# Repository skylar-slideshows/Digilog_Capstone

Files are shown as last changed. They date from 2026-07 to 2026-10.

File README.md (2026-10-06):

# Digitally Controlled Analog Mixing Console

### Capstone, 2026, Northeastern University Department of Electrical Engineering

### Contributors: Skylar Denno, Darya Petrova, Evan Forcucci, Xinhao Chen, Luke Garrity, Daniel Salas

### Advisor: [Milad Siami](https://coe.northeastern.edu/people/siami-milad/)

## [Firmware Documentation](https://docs.skylar.lgbt/)

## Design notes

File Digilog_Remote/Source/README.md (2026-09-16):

### $chct [N]^
STM32 -> Remote. Reports the number of physical channels present in the console to the remote program.
### $chnm [n] [name]^
STM32 -> Remote. Sets channel n's name in the GUI to reflect the console.
### $ud [n] [controlID]^
STM32 -> Remote. User has turned physical knob. Update it in GUI to new position.
### $sw [n] [switchID]^
STM32 -> Remote. User has toggled routing switch. Update it in GUI to new state.
### $sel [n]^
STM32 -> Remote. Indicate a channel selected in physical console. Sync to app.
### (No manual commanding) $ack [message]^
STM32 -> Remote. Indicate console's recept of any message (except ack) from remote.
###________________________________________________________________
### chnm [n] [name]
Remote -> STM32. User changed name in remote. Set it in console.
### ud [n] [controlID]
Remote -> STM32. User changed knob in remote. Update it in console.
### sw [n] [switchID]
Remote -> STM32. User toggled switch in remote. Update it in console.
### sel [n]
Remote -> STM32. Indicate a channel selected on remote app.
### sett [s] [value]
Remote -> STM32. Update a setting.
### md [t] [data]
Remote -> STM32. Send mass data (entire channel's values).
t = 0 -> channel info, t = 1 -> console settings, t = 2 -> insert/chain routing
md begin // md end
### ack [message]
Remote -> STM32. Indicate remotes's recept of any message (except ack) from console.
###________________________________________________________________
n = Channel
###________________________________________________________________
###controlID:
0 = GAIN (Input)
1 = AUX 1 (Send)
2 = PAN (Send 1)
3 = AUX 2 (Send)
4 = PAN (Send 2)
5 = AUX 3 (Send)
6 = PAN (Send 3)
7 = AUX 4 Mono (Send)
8 = HF Gain (EQ)
9 = HF Freq (EQ)
10 = HMF Gain (EQ)
11 = HMF Freq (EQ)
12 = HMF Q (EQ)
13 = LMF Gain (EQ)
14 = LMF Freq (EQ)
15 = LMF Q (EQ)
16 = LF Gain (EQ)
17 = LF Freq (EQ)
18 = Input (Comp)
19 = Attack (Comp)
20 = Threshold (Comp)
21 = Release (Comp)
22 = De-Ess (Comp)
23 = Ratio (Comp)
24 = Output (Comp)
25 = PAN (extra knob)
26 = Fader
###________________________________________________________________
###switchID:
0 = Input Source (cycle: 0 Line / 1 Mic / 2 Hi-Z)
1 = Phase (PHS)
2 = +48V
3 = HPF
4 = Solo
5 = Mute
6 = Insert (INS)
7 = Pre-fader insert
###________________________________________________________________
###s:

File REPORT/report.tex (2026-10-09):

\documentclass[11pt, letterpaper,titlepage]{article}

% --- Essential Packages ---
\usepackage[utf8]{inputenc}
\usepackage[margin=1in]{geometry}
\usepackage{fancyhdr} % For custom headers and footers
\usepackage{graphicx}
\usepackage{amsfonts}

\usepackage{amsmath}
\usepackage{float}

\usepackage{hyperref}
\usepackage{setspace}

\usepackage{ragged2e}
\usepackage{parskip}

\usepackage{booktabs}
% --- Header/Footer Configuration ---
\pagestyle{fancy}
\fancyhf{} % Clear all default header and footer settings
\fancyhead[L]{DIGITALLY CONTROLLED ANALOG MIXER} % Left header text
\fancyhead[C]{} % Center header text (empty)
\fancyhead[R]{\thepage} % Right header (page number)
\renewcommand{\headrulewidth}{0.4pt} % Line below header
\linespread{1.2}

\begin{document}
\begin{titlepage}
    \centering
    \vspace*{0cm}
    
    {\huge \textbf{Analog Mixing Console with Digital Control\\ \vspace{0.5cm}and Automated Signal Path Configuration}} \\[1cm]
    
    \vspace{0.5cm}
    
    {\huge Capstone Project Report}
    
    \vspace{5cm}

    {\Large \textbf{Skylar Denno}}
    
    \vspace{0.3cm}
    
    {\Large \textbf{Darya Petrova}}
    
        \vspace{0.3cm}
    
    {\Large \textbf{Evan Forcucci}}
    
        \vspace{0.3cm}
    
    {\Large \textbf{Xinhao Chen}}
    
        \vspace{0.3cm}
    
    {\Large \textbf{Luke Garrity}}
    
        \vspace{0.3cm}
    
    {\Large \textbf{Daniel Salas}}

    \vspace{0.5cm}
    
        {\large \textbf{Advisor: }Milad Siami \textbf{[Team \#2]}}
    
        \vspace{1.3cm}

        {\LARGE \textbf{Northeastern University}} \\
        
    Department of Electrical and Computer Engineering \\
    \vspace{1cm}

    \today

\end{titlepage}
\setlength{\parindent}{6pt}

\justify

\tableofcontents
\newpage

\section{Introduction}
\subsection{Background}
\subsection{Problem Statement}
\subsection{Scope and Design Goals}

\newpage

\section{Analog Design}

\subsection{Analog Systems Overview}

\subsection{Voltage Controlled Amplifiers}
\label{sec:vca}
% ----------------------------------------------------------------------------
% [PROSE] Opening -- sketch:
%   - Every gain in the console is set by a DC control voltage from the digital
%     side; the audio never passes through a digital stage.
%   - Pan/fader module used to introduce the basics: two identical VCAs, one
%     control voltage each, so the VCA and its temperature behavior can be
%     shown without extra circuitry. EQ, input and compressor modules reuse this.
%   - Part: THAT2180A (Blackmer log-antilog cell): dB-linear control,
%     >120 dB dynamic range, 0.005 % THD typ., pre-trimmed. [cite datasheet]
%   - One sentence on the module path (input buffer -> insert switching ->
%     two VCAs -> I/V -> balanced bus drivers), point to Fig.~\ref{fig:vca-stage}.
% ----------------------------------------------------------------------------
The most fundamental part of an audio mixer is control of each individual channels' gain before summing to the final stereo signal. To implement gain control that can be remote controlled by a voltage, voltage controlled amplifiers (VCAs) were used. Two VCAs were actually used on every channel. Since we aim to build a stereo mixer, the two VCAs feed the left and right summing channel of the mix bus, respectively. Each channel's two VCAs may be given different gain control voltages (CVs) to pan the channel's audio in the stereo field. For example, if a channel's left VCA had a CV to attenuate by -90dB (basically muted) and the right VCA had the CV to add 6dB of gain, that channel's audio would sound like it was coming from the right speaker after summing. To implement the regular fader behavior, which changes the gain of the left and right side together, both the left and right control voltages would be scaled together to change gain equally in both channels.

The specific VCA we picked for this purpose was the THAT 2180 from the Massachusetts-based THAT Corporation. It is the industry standard VCA for high fidelity audio performance. This is due to its total harmonic distortion (THD) of just 0.005\% (for the 'A' grade 2180s), which is extremely low for a VCA. Additionally, it uses a Blackmer gain cell, which has a logarithmic gain curve, allowing control voltage and decibel gain to coincide linearly. Unfortunately, in September 2026, halfway through the design of the project, THAT Corporation announced it was discontinuing its legendary 2180 series, sending shockwaves through the audio electronics community. Frantically, we bought 32 of the 'A' grade THAT 2180s to use for this purpose, but the rest of the analog systems use clones of the THAT 2180 (Alfa RPAR AS2180, which from our tests, seems to have nearly as good performance as the genuine 'A' grade 2180s) or the SSI2164 VCA.

\begin{figure}[H]
    \centering
    % \includegraphics[width=0.8\textwidth]{figures/vca_stage.pdf}
    \fbox{\parbox[c][4.5cm][c]{0.8\textwidth}{\centering
        Placeholder: one VCA channel --- $C_\text{in}$, $R_\text{in}$, THAT2180A,
        I/V converter ($R_f \parallel C_f$), control-port snubber, $R_\text{SET}$}}
    \caption{One channel of the pan/fader VCA stage.}
    \label{fig:vca-stage}
\end{figure}

\paragraph{Current-mode operation.}
% [PROSE] sketch:
%   - Current in, current out: pins 1 and 8 sit at virtual ground.
%   - R_in turns the input voltage into a current; an op-amp I/V converter turns
%     the output current back into a voltage. Overall path is non-inverting.
%   - With R_f = R_in the stage is unity gain when the cell is at 0 dB.
\begin{equation}
    I_\text{in} = \frac{V_\text{in}}{R_\text{in}}, \qquad
    I_\text{out} = A_I\, I_\text{in}, \qquad
    V_\text{out} = R_f\, I_\text{out}
    \quad\Longrightarrow\quad
    \frac{V_\text{out}}{V_\text{in}} = \frac{R_f}{R_\text{in}}\,A_I
    \label{eq:vca-transfer}
\end{equation}

\paragraph{Exponential gain control.}
% [PROSE] sketch:
%   - The cell logs the input current across matched junctions, adds the control
%     voltage, and antilogs it back. [cite THAT DN128 / Hebert, AES 1995]
%   - Gain is exponential in the control voltage, i.e. linear in dB.
%   - kappa comes from kT/q; datasheet value 6.1 mV/dB at a die temperature of
%     about 35 C.
%   - E_C+ carries the fader/pan CV here; E_C- is grounded (the compressor CV
%     enters there in a later module).
\begin{equation}
    \begin{gathered}
    A_I = \exp\!\left(\frac{q\,(E_{C+}-E_{C-})}{2kT}\right)
    \quad\Longrightarrow\quad
    G_\text{dB} = 20\log_{10}A_I = \frac{E_{C+}-E_{C-}}{\kappa(T)}, \\
    \kappa(T) = \frac{\ln 10}{10}\,\frac{kT}{q} \approx 6.1\ \mathrm{mV/dB}
    \end{gathered}
    \label{eq:vca-law}
\end{equation}

\paragraph{Temperature sensitivity.}
% [PROSE] sketch:
%   - kappa is proportional to absolute temperature (PTAT), so the dB gain scales
%     by T0/T: a span error that pivots about 0 dB.
%   - Example: -20 dB setting, +20 C warm-up -> about 1.3 dB error. This is what
%     Section~\ref{sec:cv-buffer} compensates.
\begin{equation}
    G_\text{dB}(T) = G_\text{dB}(T_0)\,\frac{T_0}{T}
    \quad\Longrightarrow\quad
    \frac{\Delta G_\text{dB}}{G_\text{dB}} \approx -\frac{\Delta T}{T_0} \approx -0.33\,\%/\mathrm{K}
    \label{eq:vca-tempco}
\end{equation}

\paragraph{Operating point.}
% [PROSE] sketch:
%   - Pin 5 is not a supply: R_SET sets the cell current (pin sits about four
%     Vbe below ground). Datasheet rule: I_SET covers the peak signal currents
%     plus 570 uA of bias. Worst case 0 dB with a 14 V peak: 0.70 mA in and out.
%   - Control port must be driven from well under 50 ohm: base currents are
%     signal-related, and 10 uV of audio at the port already gives 0.01 % THD.
%     Hence op-amp drive plus a shunt RC snubber at the pin.
%   - Remaining choices in Table~\ref{tab:vca-op}.
\begin{equation}
    I_\text{SET} = \frac{V_\text{pin5}-V_{EE}}{R_\text{SET}}
    = \frac{-2.85\,\mathrm{V}+15\,\mathrm{V}}{5.1\,\mathrm{k}\Omega} = 2.38\,\mathrm{mA}
    \;\geq\; \hat I_\text{in} + \hat I_\text{out} + 570\,\mu\mathrm{A} = 1.97\,\mathrm{mA}
    \label{eq:iset}
\end{equation}

\begin{table}[H]
    \centering
    \begin{tabular}{@{}lll@{}}
        \toprule
        Component & Value & Purpose \\
        \midrule
        $R_\text{in}$, $R_f$ & $20\,\mathrm{k}\Omega$ & unity gain at 0 dB; datasheet noise/THD point \\
        $C_\text{in}$ & $10\,\mu\mathrm{F}$ bipolar & $f_c = 1/(2\pi R_\text{in} C_\text{in}) = 0.8$ Hz; blocks DC \\
        $C_f$ & $22\,\mathrm{pF}$ & cancels 15 pF at pin 8 (I/V stability) \\
        $R_\text{SET}$ & $5.1\,\mathrm{k}\Omega$ & $I_\text{SET} = 2.38$ mA, Eq.~\eqref{eq:iset} \\
        Port snubber & $100\,\Omega$ + $2.2\,\mathrm{nF}$ to ground & damps inductive op-amp output \\
        Sym (pin 4) & open & keeps factory THD trim \\
        \bottomrule
    \end{tabular}
    \caption{THAT2180A operating point.}
    \label{tab:vca-op}
\end{table}

\paragraph{Pan and fader law.}
% [PROSE] sketch:
%   - Constant-power pan: the sum of squares is constant, so a source keeps its
%     loudness across the stereo field; -3.01 dB per side at centre.
%   - Because the VCA is dB-linear, fader and pan simply add in the control
%     domain: no multiplier, one CV per channel, computed in firmware.
\begin{gather}
    g_L = G\cos\!\left(\tfrac{\pi\theta}{2}\right), \qquad
    g_R = G\sin\!\left(\tfrac{\pi\theta}{2}\right), \qquad
    g_L^2 + g_R^2 = G^2, \qquad \theta \in [0,1]
    \label{eq:panlaw}\\
    G_{\text{dB},L} = 20\log_{10}G + 20\log_{10}\cos\!\left(\tfrac{\pi\theta}{2}\right), \qquad
    G_{\text{dB},R} = 20\log_{10}G + 20\log_{10}\sin\!\left(\tfrac{\pi\theta}{2}\right)
    \label{eq:panlaw-db}
\end{gather}

\subsection{Control Voltage Buffering and Temperature Drift Compensation}
\label{sec:cv-buffer}
% ----------------------------------------------------------------------------
% [PROSE] Opening -- sketch:
%   - One op-amp stage per channel has four jobs: (1) map the DAC range onto the
%     VCA's useful control range, (2) drive the control port from a low
%     impedance, (3) filter DAC steps and noise (ripple on E_C modulates the
%     audio), (4) cancel the PTAT drift of Eq.~\eqref{eq:vca-tempco}.
%   - Topology: inverting multiple-feedback (MFB) low-pass fed by a small
%     network -- DAC current, an offset current from a -2.5 V reference, and
%     an NTC thermistor. Fig.~\ref{fig:cv-buffer}, values in
%     Table~\ref{tab:cv-values}.
%   - Why MFB: inverting (the sign needed), good rejection far above the
%     corner, scaling and filtering in one stage.
% ----------------------------------------------------------------------------

\begin{figure}[H]
    \centering
    % \includegraphics[width=0.8\textwidth]{figures/cv_buffer.pdf}
    \fbox{\parbox[c][4.5cm][c]{0.8\textwidth}{\centering
        Placeholder: CV buffer --- DAC input, $R_\text{cv}$ + trim,
        $R_\text{off}$ to $-2.5$ V, $R_p \parallel R_\text{NTC}$,
        MFB ($R_2$, $R_3$, $C_1$, $C_2$), OPA2197, snubber at $E_{C+}$}}
    \caption{Control voltage buffer for one VCA.}
    \label{fig:cv-buffer}
\end{figure}

\begin{figure}[H]
\centering
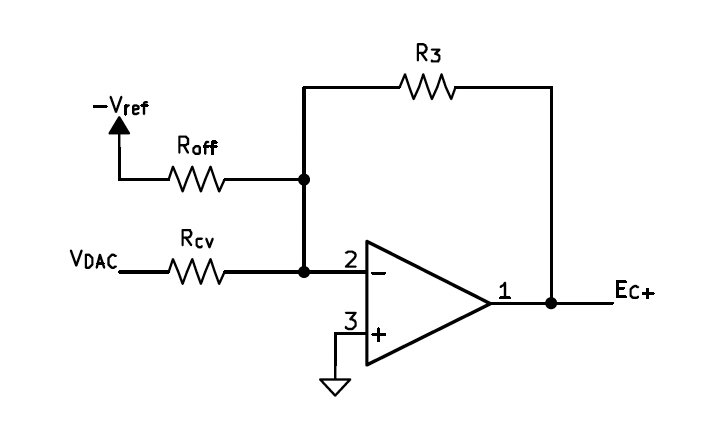
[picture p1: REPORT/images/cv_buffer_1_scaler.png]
 
\caption{TEST}
\end{figure}

\begin{figure}[H]
\centering
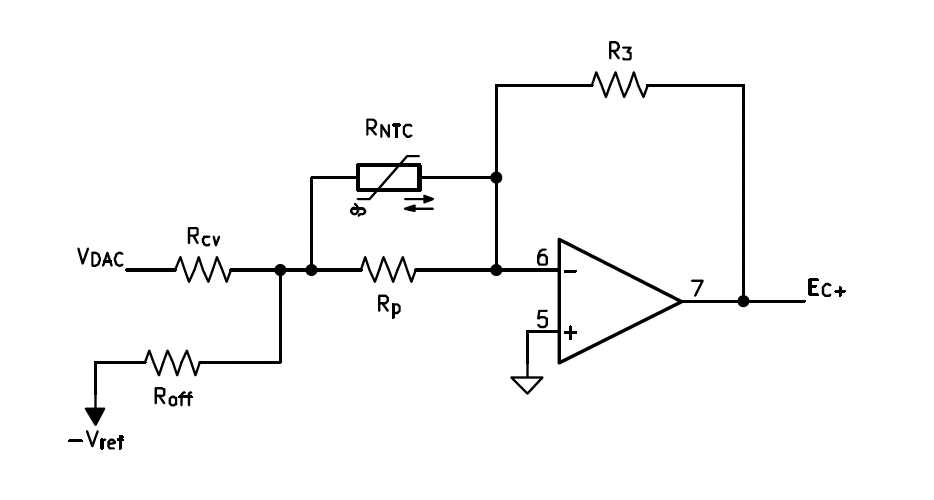
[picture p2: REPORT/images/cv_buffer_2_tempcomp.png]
 
\caption{TEST}
\end{figure}

\begin{figure}[H]
\centering
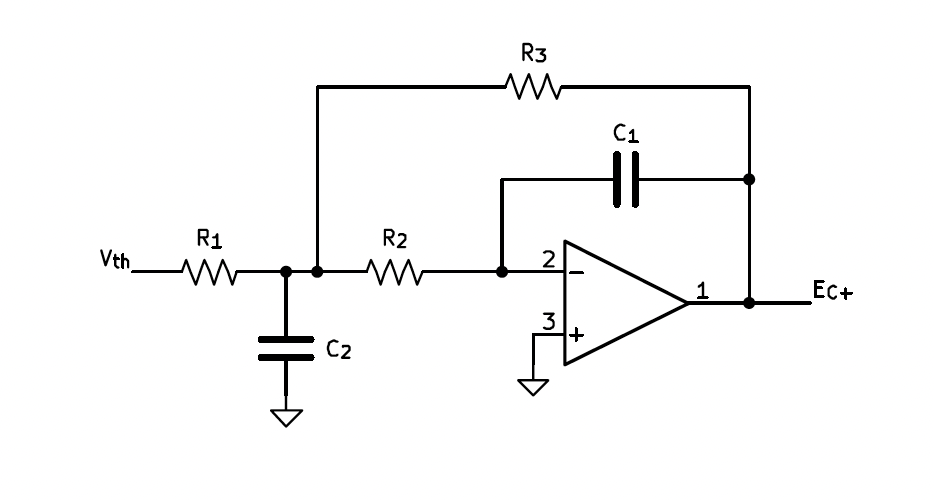
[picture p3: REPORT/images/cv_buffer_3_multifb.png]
 
\caption{TEST}
\end{figure}

\begin{figure}[H]
\centering
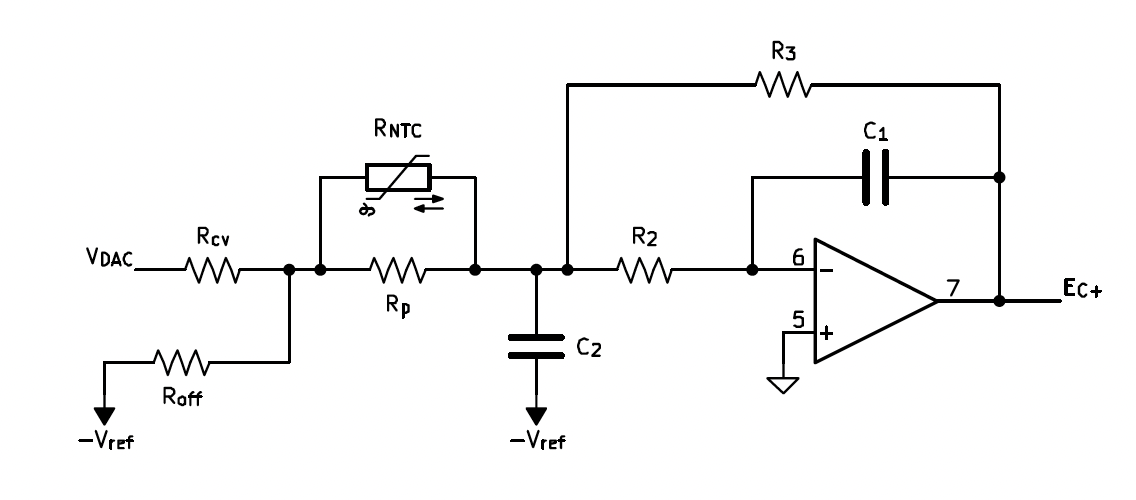
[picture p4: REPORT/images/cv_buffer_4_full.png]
 
\caption{TEST}
\end{figure}

\begin{figure}[H]
\centering
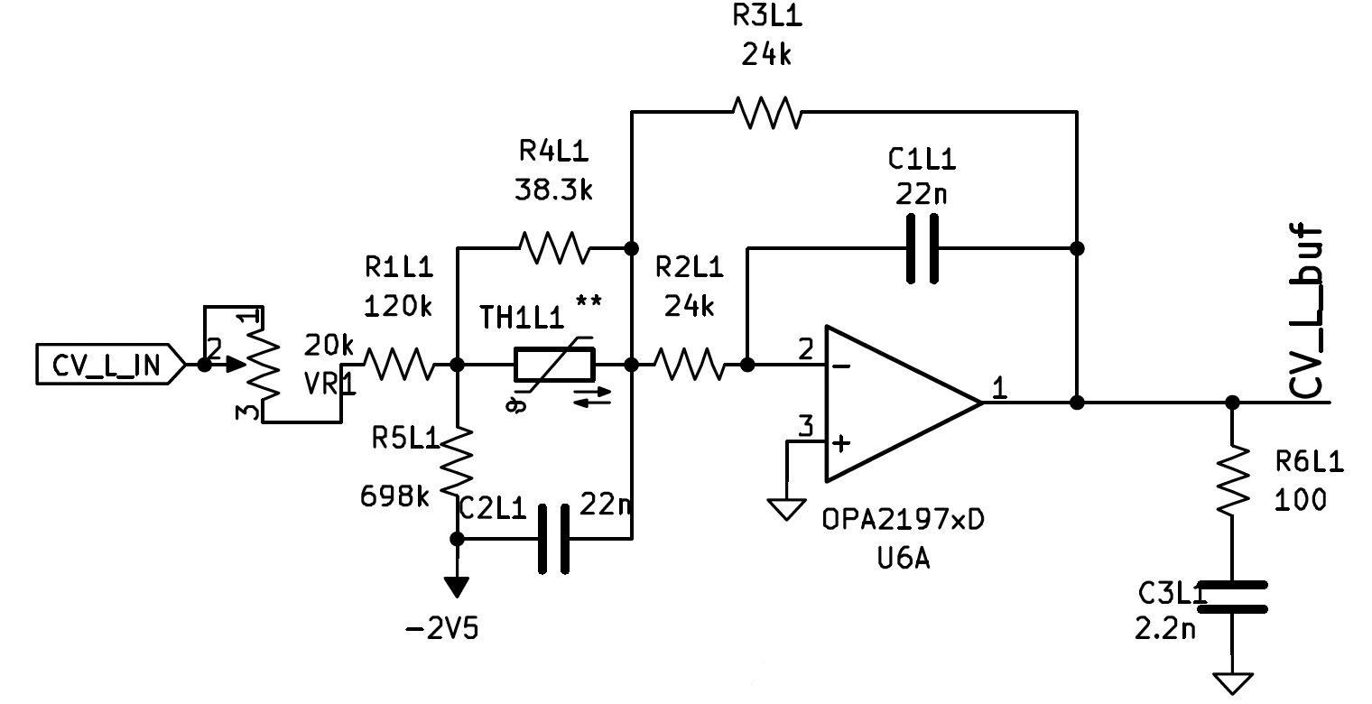
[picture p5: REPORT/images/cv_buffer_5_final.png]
 
\caption{The trim potentiometer on the left is ONLY to calibrate temperature scaling during assembly, and it is not accessible to the end user.}
\end{figure}

\begin{table}[H]
    \centering
    \begin{tabular}{@{}lll@{}}
        \toprule
        Component & Value & Role \\
        \midrule
        $R_\text{cv}$ & $120\,\mathrm{k}\Omega$ + $20\,\mathrm{k}\Omega$ trim ($133\,\mathrm{k}\Omega$ nom.) & DAC voltage to current; span trim \\
        $R_\text{off}$ & $698\,\mathrm{k}\Omega$ & offset current \\
        $R_p \parallel R_\text{NTC}$ & $38.3\,\mathrm{k}\Omega \parallel 47\,\mathrm{k}\Omega$ ($B = 4090$ K) & temperature compensation \\
        $R_2 = R_3$ & $24\,\mathrm{k}\Omega$ & filter and DC gain \\
        $C_1 = C_2$ & $22\,\mathrm{nF}$ film & filter \\
        $V_\text{ref}$ & 2.5 V (ADR5041 at $-2.5$ V, $222\,\mu$A bias) & offset reference \\
        Op-amp & OPA2197 & low offset and noise \\
        \bottomrule
    \end{tabular}
    \caption{CV buffer component values (one channel).}
    \label{tab:cv-values}
\end{table}

\paragraph{DAC.}
% [PROSE] sketch:
%   - MCP4728, internal 2.048 V reference at gain 2: 1 mV per code, and the
%     scale no longer depends on the 5 V rail.
\begin{equation}
    V_\text{DAC} = \frac{2V_\text{REF}}{4096}\,n = n \times 1\,\mathrm{mV}, \qquad
    V_\text{REF} = 2.048\,\mathrm{V}, \quad n \in \{0,\dots,4095\}
    \label{eq:dac}
\end{equation}

\paragraph{DC transfer.}
% [PROSE] sketch:
%   - Replace the DAC and offset branches by their Thevenin equivalent; Z_t is
%     in series, so the MFB sees one input resistor R_1.
%   - The node between Z_t and the MFB stays at 0 V DC (C_1 blocks DC and R_2
%     returns to the virtual ground), so the DC gain is simply -R_3/R_1.
%   - D is the fraction of the source current that reaches the MFB -- the
%     quantity the thermistor adjusts.
\begin{gather}
    R_\text{th} = R_\text{cv} \parallel R_\text{off}, \qquad
    V_\text{th} = R_\text{th}\left(\frac{V_\text{DAC}}{R_\text{cv}} - \frac{V_\text{ref}}{R_\text{off}}\right), \qquad
    Z_t = R_p \parallel R_\text{NTC}(T), \qquad
    R_1 = R_\text{th} + Z_t
    \label{eq:thevenin}\\
    E_{C+} = -\frac{R_3}{R_1}\,V_\text{th}
    = -R_3\,D\left(\frac{V_\text{DAC}}{R_\text{cv}} - \frac{V_\text{ref}}{R_\text{off}}\right), \qquad
    D = \frac{R_\text{th}}{R_\text{th}+Z_t}
    \label{eq:cv-dc}
\end{gather}
% [PROSE] sketch: with Table~\ref{tab:cv-values} at 25 C, Z_t = 21.1 k and
%   D = 0.841; give the resulting map.
\begin{equation}
    E_{C+} = 72.3\,\mathrm{mV} - 0.1518\,V_\text{DAC}
    \quad\Longrightarrow\quad
    G_\text{dB} = 11.9\,\mathrm{dB} - 24.9\,\tfrac{\mathrm{dB}}{\mathrm{V}}\,V_\text{DAC}
    \label{eq:cv-numeric}
\end{equation}

\paragraph{Code mapping.}
% [PROSE] sketch:
%   - Firmware applies the pan law (Eq.~\eqref{eq:panlaw-db}), then inverts
%     Eq.~\eqref{eq:cv-numeric} per channel. 0.025 dB per code.
%   - 0 V gives +12 dB and full scale about -90 dB, used as mute; the DAC's
%     power-up code is stored as 4095 so the board starts silent.
\begin{equation}
    n = \frac{72.3\,\mathrm{mV} - \kappa\,G_\text{dB}}{0.1518 \times 1\,\mathrm{mV}}
    \label{eq:code}
\end{equation}

\begin{table}[H]
    \centering
    \begin{tabular}{@{}lccccccc@{}}
        \toprule
        $G_\text{dB}$ & $+11.9$ & $+6$ & $0$ & $-3.01$ & $-20$ & $-70$ & $-90$ \\
        \midrule
        $n$ & 0 & 235 & 476 & 597 & 1280 & 3290 & 4095 \\
        \bottomrule
    \end{tabular}
    \caption{Example codes from Eq.~\eqref{eq:code} (nominal, before calibration).}
    \label{tab:codes}
\end{table}

\paragraph{Filtering.}
% [PROSE] sketch:
%   - Second-order low-pass smooths the 1 mV steps (zipper noise) and removes
%     digital noise before it reaches the control port.
%   - Q < 0.5 on purpose: no overshoot, since an overshooting CV is an
%     overshooting gain.
%   - Attenuation: -22 dB at 1 kHz, -40 dB at 3 kHz, -61 dB at 10 kHz.
%   - C_2 returns to the -2.5 V reference, which is an AC ground.
\begin{gather}
    \frac{E_{C+}(s)}{V_\text{th}(s)} = -\frac{R_3}{R_1}\,
    \frac{1}{1 + sC_1\!\left(R_2 + R_3 + \frac{R_2R_3}{R_1}\right) + s^2R_2R_3C_1C_2}
    \label{eq:mfb}\\
    f_0 = \frac{1}{2\pi\sqrt{R_2R_3C_1C_2}} = 301\,\mathrm{Hz}, \qquad
    Q = \frac{\sqrt{R_2R_3C_1C_2}}{C_1\left(R_2 + R_3 + R_2R_3/R_1\right)} = 0.46
    \label{eq:mfb-f0q}
\end{gather}

\paragraph{Temperature compensation.}
% [PROSE] sketch:
%   - From Eq.~\eqref{eq:vca-law}: to hold a dB setting, the control voltage
%     must itself grow in proportion to absolute temperature.
%   - E_C+ is proportional to D, and D depends on temperature only through Z_t,
%     so it is enough to make D PTAT (Eq.~\eqref{eq:dD}).
%   - The NTC is bent against the 2180 package so it follows the die; the pad
%     R_p flattens the NTC's exponential so the slope holds over a useful range.
%   - Two free parameters (R_p, R_th): set the slope at T_0 with
%     Eq.~\eqref{eq:comp-cond}, then check the residual over the range.
\begin{gather}
    E_{C+}(T) = E_{C+}(T_0)\,\frac{T}{T_0}
    \quad\Longrightarrow\quad
    \frac{1}{E_{C+}}\frac{dE_{C+}}{dT} = \frac{1}{T_0} \approx 0.33\,\%/\mathrm{K}
    \label{eq:ptat-req}\\
    \frac{1}{D}\frac{dD}{dT} = -(1-D)\,\frac{1}{Z_t}\frac{dZ_t}{dT}
    \label{eq:dD}\\
    R_\text{NTC}(T) = R_{25}\,e^{B\left(\frac{1}{T}-\frac{1}{T_{25}}\right)}, \qquad
    \frac{dR_\text{NTC}}{dT} = -\frac{B}{T^2}R_\text{NTC}, \qquad
    \frac{dZ_t}{dT} = \left(\frac{R_p}{R_p+R_\text{NTC}}\right)^{2}\frac{dR_\text{NTC}}{dT}
    \label{eq:ntc}\\
    (1-D)\left|\frac{1}{Z_t}\frac{dZ_t}{dT}\right|_{T_0} = \frac{1}{T_0}
    \label{eq:comp-cond}
\end{gather}
% [PROSE] sketch: numbers at T_0 = 25 C below. Result: residual scale error
%   0.39 % over 10--40 C (0.08 dB at -20 dB) against 1.3 dB uncompensated.
%   Optional: plot of compensated vs uncompensated error over temperature.
\begin{align}
    \left.\frac{dR_\text{NTC}}{dT}\right|_{T_0} &= -2.16\,\mathrm{k}\Omega/\mathrm{K}, &
    \frac{1}{Z_t}\frac{dZ_t}{dT} &= \frac{-436\,\Omega/\mathrm{K}}{21.1\,\mathrm{k}\Omega} = -2.07\,\%/\mathrm{K},
    \nonumber\\
    1-D &= 0.159, &
    \frac{1}{D}\frac{dD}{dT} &= 0.159 \times 2.07\,\%/\mathrm{K} = 0.33\,\%/\mathrm{K}
    \label{eq:comp-numbers}
\end{align}

\paragraph{Calibration.}
% [PROSE] sketch:
%   - Remaining static errors: resistor tolerances, DAC reference (+/-2 %), DAC
%     zero offset.
%   - Span: the 20 k trimmer in series with R_cv (120--140 k, +/-7.7 %) sets the
%     slope; it sits in the input leg so it barely affects the filter.
%   - Zero: in firmware. Measure the gain at two codes after warm-up and
%     interpolate, since the law is linear in dB.
\begin{equation}
    n(G_\text{dB}) = n_a + \left(G_\text{dB} - G_a\right)\frac{n_b - n_a}{G_b - G_a}
    \label{eq:cal}
\end{equation}

\subsection{Channel Routing and Auxiliary Buses}
\subsection{Voltage Controlled State Variable Filters and EQ Circuit}
\subsection{Input Circuitry and Preamplifier}
\subsection{Hybrid Digital/Analog Dynamic Range Compressor}
\subsection{Mix Bus and Master Section}
\subsection{Channel Insert Routing Matrix}
\subsection{PCB Design Notes}

\newpage
\section{Digital Systems}

\subsection{Digital Systems Overview}
\subsection{I2C Buses}
\subsubsection{I2C Communication Timings}
\subsubsection{Frames}
\subsubsection{Superframes}
\subsection{Control Panel Integration and Control Feedback}
\subsubsection{EC11 Rotary Encoders and Two-Bit Quadrature}
\subsubsection{Push-buttons and Debounce}
\subsubsection{MCP23017 GPIO Expanders}
\subsubsection{Shift-Register Based LED Scheme}
\subsection{LCD Displays}

\subsection{Saving of Console States}
\subsection{Communication Between Buckets and the Master Controller}
\subsection{USB Remote Control Computer Software}
\subsection{PCB Design Notes}

\newpage
\section{Testing and Results}
\subsection{Analog Performance Metrics}
\subsubsection{Linearity / Distortion}
\subsubsection{Noise}
\subsubsection{Temperature Drift Compensation}
\subsection{Digital System Bug Testing}

\newpage
\section{Financials}
\subsection{This Project's Budget and Bill of Materials}
\subsection{Exploration of Cost Reduction for Making a Commercial Product}

\end{document}

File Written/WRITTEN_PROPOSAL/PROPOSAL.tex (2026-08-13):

\documentclass[11pt, letterpaper,titlepage]{article}

% --- Essential Packages ---
\usepackage[utf8]{inputenc}
\usepackage[margin=1in]{geometry}
\usepackage{fancyhdr} % For custom headers and footers
\usepackage{graphicx}
\usepackage{amsfonts}

\usepackage{amsmath}
\usepackage{float}

\usepackage{hyperref}
\usepackage{setspace}

\usepackage{ragged2e}
\usepackage{parskip}

\usepackage{booktabs}
% --- Header/Footer Configuration ---
\pagestyle{fancy}
\fancyhf{} % Clear all default header and footer settings
\fancyhead[L]{DIGITALLY CONTROLLED ANALOG MIXER} % Left header text
\fancyhead[C]{} % Center header text (empty)
\fancyhead[R]{\thepage} % Right header (page number)
\renewcommand{\headrulewidth}{0.4pt} % Line below header
\linespread{1.2}

\begin{document}
\begin{titlepage}
    \centering
    \vspace*{0cm}
    
    {\huge \textbf{Analog Mixing Console with Digital Control\\ \vspace{0.5cm}and Automated Signal Path Configuration}} \\[1cm]
    
    \vspace{0.5cm}
    
    {\huge Capstone Project Proposal}
    
    \vspace{5cm}

    {\Large \textbf{Skylar Denno}}
    
    \vspace{0.3cm}
    
    {\Large \textbf{Evan Forcucci}}
    
        \vspace{0.3cm}
    
    {\Large \textbf{Daniil Petrov}}
    
        \vspace{0.3cm}
    
    {\Large \textbf{Xinhao Chen}}
    
        \vspace{0.3cm}
    
    {\Large \textbf{Daniel Salas}}
    
        \vspace{0.3cm}
    
    {\Large \textbf{Luke Garrity}}

    \vspace{0.5cm}
    
        {\large \textbf{Advisor: }Milad Siami \textbf{[Team \#2]}}
    
        \vspace{1.3cm}

        {\LARGE \textbf{Northeastern University}} \\
        
    Department of Electrical and Computer Engineering \\
    \vspace{1cm}

    \today

\end{titlepage}
\setlength{\parindent}{6pt}

\justify

\tableofcontents

\section{Abstract}

An analog mixing console cannot remember its own settings. Every parameter lives
in the position of a potentiometer, and the audio passes through that
potentiometer, so the two roles cannot be separated. Restoring a session means
turning every knob by hand against a paper recall sheet, and the result is never
exact. A digital console solves recall completely, but only by converting the
audio to numbers at the input and back to a voltage at the output.

This proposal describes a console that takes neither path. The audio stays
analog from the input connector to the summing bus. Only the control values
become digital. A rotary encoder produces a number instead of a resistance, a
control processor stores that number, and a control voltage carries it to the
analog circuit. The circuit then responds as though a hand had moved a knob.
Voltage controlled amplifiers set every gain, and operational transconductance
amplifiers supply every variable resistance in the equalizer. One command
therefore reconfigures a whole channel, and nothing in the signal path moves.

The design covers 16 channels and a master section. One STM32G474 processor
serves each group of four channels through four independent
I\textsuperscript{2}C buses, and it drives 20 control voltages and 42 input pins
per channel. Each channel carries a microphone preamplifier or a line receiver,
a four band state variable filter equalizer, a compressor with a digital
detector and an analog gain element, auxiliary sends, a pan control, and a
motorized fader with a touch sensor.

The difficulty is not the control plane. The difficulty is keeping the audio
clean while converters, expanders, shift registers, motor drivers, and switching
supplies all sit centimetres from the signal path. Three quantities decide the
outcome: the linearity of every voltage controlled element, the noise that the
control plane couples into the audio, and the repeatability of a recall as the
temperature changes. Success is therefore a measurement rather than an opinion.
The project reports total harmonic distortion, the noise floor, the crosstalk
between channels, and the recall error across a temperature range, and it
compares each figure against a conventional analog desk.

\newpage

\section{Introduction}
\label{sec:intro}

A mixing console routes, shapes, and balances many audio signals at once, before summing each processed signal together into a full mixed, recorded performance of a song. Two kinds of audio mixing console serve this job today, and each one gives up something that the other holds.

An analog console carries the audio as a continuous voltage from the input to
the output. Many audio engineers prefer the result of analog hardware and insist, even today, to use it despite its expense and many drawbacks. These drawbacks include the issue of recall of settings. An analog console cannot store a
setting to load later, since all the knobs and faders control physical potentiometers that have physical resistances that the audio signal passes through. To set a parameter (a resistance) for a different configuration or song, one must physically rotate the knobs by hand to physically recall the state. To reconfigure an entire console (often with 64+ channels, each with several tens of knobs), can take hours. The state of a session lives in the position of every knob and every fader on the surface. An audio engineer who needs that state again writes it (or often their assistant writes it) on a paper recall sheet and rebuilds it by hand. The rebuild is slow, and it is never exact.

Conversely, a digital console converts the audio to discrete samples at the input and back to a continuous
voltage at the output. All the processing is done digitally with digital signal processing (DSP). The digital console stores and recalls every parameter without error, but the
audio only reaches those settings and that memory after passing through converters and arithmetic. No matter if DSP really "sounds" worse than analog processing or not, the analog music equipment market is massive.

We propose a mixing console that takes a third path. The audio stays analog through the whole console signal chain. Only the control values become digital, and using deep integration between digital and analog systems, we may configure the console's analog signal path instantly and exactly, eliminating the need for manual recall.

\subsubsection*{What the Console Does}

In traditional mixing consoles, the potentiometers do two jobs at once, and these jobs are inseparable. They provide a physical control and indication of position, and they provide a variable resistance related to that position. If we separate the potentiometer into a rotary encoder, which provides the physical control and indication, but no resistance, and a voltage controlled resistor of some sort, which provides the variable resistance without moving parts, we can eliminate the problem of having to physically match the state on real resistor strips for recall.

In our console, every parameter that an engineer would normally set with a potentiometer becomes a number in the memory of a control processor. That number is set by a rotary encoder, and that number reaches the analog
circuit as a control voltage, and the circuit responds as if a hand had moved a
knob.

Crucially, the controller itself can also change all of the control voltages independently of the physical positions of any knobs, instantly reconfiguring hundreds of parameters from a saved state with no moving parts. Additionally, an arbitrary number of controls may be automated to change values throughout a song, and arbitrarily many parameters may be changed at once in real time for live applications (unlike a physical potentiometer, where an audio engineer only has two hands).

An audio console is simply made up of many individual channels of identical signal processors. Each channel processes each part/layer of audio within of the song, such as the snare drum, the bass guitar, the lead vocal, etc. and each layer of audio needs different processing to fit in the full "picture" of the full recorded performance. Audio consoles simply combine many of these channels together, add some useful routing options, and sum the processed outputs of each channel together at the end. We aim to create a console with a modest 16 channels, using one STM32 microcontroller for every group of 4 channels. The actual remote control of parameters and analog processing of audio happens within those channels, and each channel identically requires the following features.

Every channel carries its own microphone preamplifier or a line receiver, its own four band
equalizer, a dynamic range compressor, routing options for auxiliary sends, a pan control, and a fader / main volume control. For our design, we plan for voltage
controlled amplifiers (VCAs) to set every gain in that chain. Operational transconductance
amplifiers (OTAs) will supply every variable resistance, which are needed to control the corner frequencies
and the Q (quality/BW) factor of each band in the equalizer. Analog multiplexers select the band shapes, the
bypass paths, and other routing options. Section~\ref{sec:technical}
describes each of these circuits in turn.

The control surface reports the state that the memory holds. Each channel
carries ten rotary encoders with rings of LEDs around each encoder to show their "position" in a way that can be changed remotely without movement. Each channel also will have sixteen buttons with lamps, a small
display, and a motorized fader with a touch sensor. None of these controls
touch the audio. An encoder produces a number and nothing else, so the same
encoder can serve the equalizer, the compressor, or the sends as the engineer
selects. One physical control therefore covers several parameters, and the panel
holds far fewer controls than the channel has settings, which reduces the cost, complexity, and size as compared to a fully analog console. Additionally all the rotary encoders may be the same across the entire system, whereas using potentiometers in a fully analog audio path usually requires a large variety of hard-to-source potentiometers with different values and exotic taper curves.

\begin{figure}[H]
    \centering
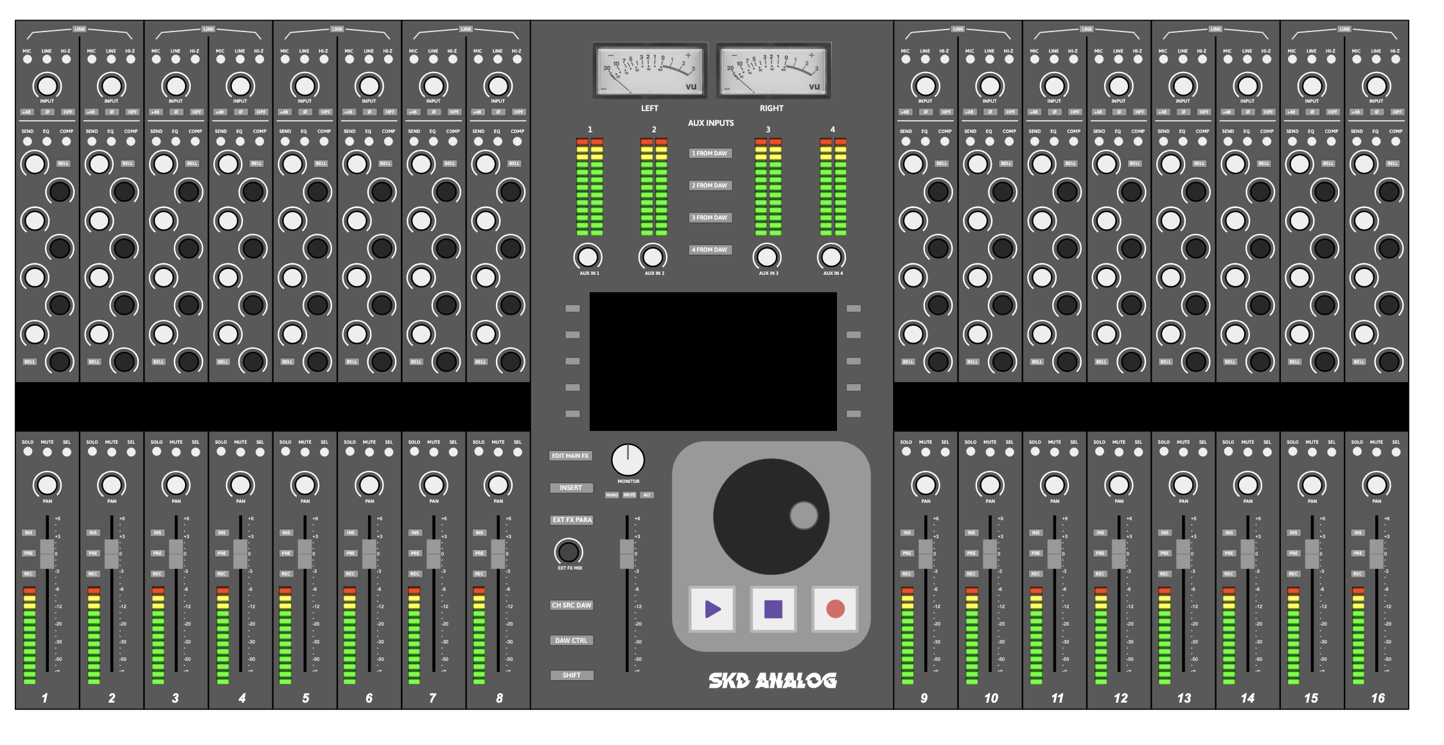
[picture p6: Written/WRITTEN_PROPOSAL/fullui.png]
    
    \caption{Mockup of the front panel of a 16 channel console under this vision.}
    \label{fig:panel-mockup}
\end{figure}

\subsubsection*{Greatest Challenges}

Moving the control plane into a processor is not the hard part. Keeping the
audio clean while that processor sits centimeters away, along with the depth and number of points of the analog/digital integration, is the hard part. Three
problems decide whether the approach works.

The first problem is linearity. A fixed resistor and a good operational
amplifier, as used in traditional consoles, are close to ideal. A voltage controlled element is not. Every gain stage and every filter in the channel therefore could add
distortion that a passive component would not add. The
differential pair inside an operational transconductance amplifier stays linear
only across a few tens of millivolts, so the design attenuates the signal before
it reaches that input and takes advantage of linearizing distortion, which predistorts the signal in a way such that the OTAs nonlinearities will undo this distortion.

The second problem is noise, of which the digital control circuitry
supplies the largest source. A digital console can place its processor far from
any analog circuit, and the digital audio is impervious to external interference. This console does not have this luxury. Converters, port expanders, shift
registers, motor drivers, and switching supplies all sit near the signal path.
Noise on a control port also does more damage than noise on a signal wire,
because a voltage controlled amplifier multiplies that noise into the audio. One
millivolt on a control port for the filter circuitry produces sidebands only 55\,dB below the signal.

The third problem is recall accuracy. For the most part, the console runs open loop. No sensor
measures the true gain of a channel, and no controller corrects it. This is in order to allow the audio engineer to change anything in realtime, whenever they want. We may add a short startup sequence that calibrates some things, but for normal operation, there is nothing on the output side to ensure nothing drifts. The
transconductance of an operational transconductance amplifier and the gain
constant of a voltage controlled amplifier both scale with absolute temperature.
A stored number therefore does not produce the same result on a cold morning
that it produced during the session it came from.
Section~\ref{sssec:temperature} discusses this topic in more detail.

\subsubsection*{Goal}

The goal of this project is first and foremost a demonstration. We aim to show
that our audio console can hold every parameter in memory, recall it and reconfigure a fully analog signal path on command, and
still meet the audio performance that engineers expect from a conventional
analog desk. Digital control must cost nothing that even an experienced audio engineer can hear.

Additionally, a second and more movable goal is to build these concepts into a somewhat polished, nearly release-ready "demonstration product." Since much of the challenges with noise and linearity can only solved by designing our own PCBs, and since some of the digital systems will be too fast to rely on breadboards, due to their intrinsic parasitic capacitance and inductance, we will have to design PCBs and use hobbyist/prototype manufacturing services such as JLCPCB. If we just make a nice enclosure, making a "proto-product" kind of thing is not much of a step past demonstration.

However, for the first (and main goal of demonstration), success is a measurement and not an opinion. We will report total harmonic
distortion, the noise floor, the crosstalk between channels, and the
repeatability of a recall across a range of temperature. We will compare these values to existing, fully analog tradition, processors. A design that recalls the settings
perfectly but adds audible distortion or hiss has failed the claim that matters.

\subsection{Applications in Other Fields}
\label{ssec:other-fields}

The split between an analog signal plane and a digital control plane is neither
new nor unique to audio. Numerous industries run a physical processes that produce and handle highly sensitive analog signals in their native
domain and command those processes from a computer. They meet the same problems
that this console meets, so their answers inform its design.

Electric power gives the clearest case, because nobody can digitize the signal.
A substation handles hundreds of megawatts, and if a converter could sample that power
and rebuild it, what would power the output buffer?! So the power path stays analog by necessity. Every improvement
must therefore come from the control plane, and the IEC 61850 standard~\cite{iec61850} carries
settings, measurements, and commands across that plane.

The devices in a substation divide the same way the channel strip on an audio console divides. The
on-load tap changer of a transformer moves in discrete steps, much like the
switched resistor network inside the PGA2500~\cite{pga2500} digitally controlled microphone preamplifier we will use.
A static VAR compensator varies its output in a continuous way through a
thyristor firing angle, much like a voltage controlled amplifier follows a
control voltage. Recall appears in the same form as well. A protective relay
holds several groups of settings, and an operator selects a different group when
the network configuration changes. One command therefore moves many parameters
to a known state, which is exactly what a snapshot does on a console.

A power system also adds one rule that this design needs. An interlock checks
the preconditions before a command executes, because the wrong order of
operations can damage infrastructure. The recall sequence of Section~\ref{sssec:recall}
follows the same logic when it mutes a channel before it writes new values, to avoid clicks and pops on the output, which when amplified could (and have, many times) destroy the speaker drivers in highly accurate studio monitors with extremely fast transient responses.

Two further fields each contribute a method. A chemical plant stores its
settings as recipes and recalls them at the start of a production run, which is
a snapshot under a different name. Process control also names the transition
itself. A bumpless transfer moves an output to a new setpoint without a step at
the process, and the mute and ramp of a console recall performs the same work.
A phased array radar holds thousands of antenna elements, and no two of them
match. Every element therefore carries a calibration table against frequency and
against temperature. Section~\ref{sssec:temperature} applies that same method to
each channel of this console, and for the same reason.

\newpage
\section{System Overview}
\label{sec:overview}

\subsection{Analog Systems}
\label{ssec:analog-overview}

\subsubsection*{Remote Controlled Analog Systems}
To remotely control parameters of the analog signal processing, all the required processing may be (and usually is, even in fully analog systems) designed to only require variable resistors and variable gain. For example, to change the resonant frequency of a band on the equalizer, we may keep the capacitor value constant and vary only the resistor to change the resonant frequency. The implementation details of these voltage controlled amplifiers and voltage controlled resistors are covered in Sections~\ref{sssec:vca} and~\ref{ssec:vcr-sec}, respectively.

In short, voltage controlled amplification will be implemented using voltage controlled amplifiers (VCAs), specifically the SSI2164~\cite{ssi2164} for most signals, and the PGA2500 digitally controlled microphone preamplifier (on an SPI control bus rather than using an analog control voltage) for the microphone inputs. Any switching or reconfiguration of channel paths will be implemented by the DG409~\cite{dg409} CMOS analog multiplexer. Voltage controlled resistors will be implemented using the LM13700~\cite{lm13700} operational transconductance amplifier (OTA).

For these components, temperature often changes their behavior, and parameters may differ between units. Details on calibration and temperature compensation schemes are outlined in Section~\ref{sssec:temperature}. Using these components, a voltage controlled parametric equalizer (Section~\ref{ssec:eq}) may be implemented.

\subsubsection*{Control Voltages}
To produce the control voltages, we will rely on a set of MCP4728~\cite{mcp4728} digital-to-analog converter (DAC) chips on I2C busses (running at "Fast mode," 400kHz~\cite{i2cspec}). These chips have 12-bit accuracy (4,096 voltage levels), which provides more than enough definition for our purposes. We will use a low sample rate around 400Hz, as these control voltages do not need fast changes or high bandwidth. The 0-3.3V output from these DACs will be mapped to a larger voltage range of around $+/- 15V$ using low offset op-amps and a reference offset voltage. The amplification circuit will also provide low pass filtering which both smooths the control voltages and removes any digital noise. Only then will the control voltages be allowed to pass physically to the low noise analog section. More information on this topic is in Section~\ref{ssec:cv-dacs}.

\subsubsection*{Noise and Power}
The analog systems will be powered by a set of low noise, bipolar rails at about $+/- 16.5V$. The power supply for the analog components will be of a linear topology, to avoid polluting the voltage rails with the switching noise present in other power supply designs. Additionally, the DACs and ADCs will use a dedicated 3.3V voltage reference, designed as a small, low noise supply and separate from the main, high current 3.3V logic supply, but sharing the same ground potential. The power supply is discussed in Section~\ref{ssec:psu}.

To further isolate the analog section from the digital section, the analog circuitry will be physically located on a different printed circuit board (PCB) than the digital components. The boards will be the same size and stack on top of each other in a mezzanine configuration, with pin headers, similarly to a shield board for microcontroller development boards, but at a much larger size. The digital PCB will be on top of the analog PCB. Any high speed or low-noise analog signals that must travel between the boards will do so via the pin headers. Interlacing these signals with ground pins in the physical pin header layout will reduce crosstalk between channels. We will avoid placing high speed or low noise signals near each other in the pin header, without a ground pin between them.

The digital and analog systems will essentially share the same ground node, but the digital and analog grounds will only connect at a single point at the power supply. Most of the noise protection will be due to the PCB layout and physical separation, rather than trying to separate the ground nodes. The digital PCB, from top to bottom, will likely have the four following copper layers: Top: Digital signals, SMD; Inner 1: Ground plane; Inner 2: Digital signals (heavily shielded); Bottom: Ground plane. Stitching vias in the ground plane will help equalize them with a very low impedance path between them. Ground vias will also be placed near each chip's ground pins. The analog PCB (below the digital PCB), from top to bottom, will have the following four copper layers: Top: Analog signals, SMD; Inner 1: Ground plane; Inner 2: Ground plane; Bottom: Analog signals. With this stackup, we can see that the bottom layer of the digital PCB, sitting right above the first layer of the analog PCB, is a ground plane, rather than a signal layer. This will help prevent interference from the digital electronics from inducing noise in the sensitive analog circuitry.

Local decoupling and filtering will be added physically closer to many of the chips and devices to shunt any noise from crosstalk of digital traces and systems to ground.

\subsubsection*{Summing Bus}
The output of each of the individual audio channels will feed a summing bus, from which the "mixed" audio may be recorded from back into a computer. The processing and gain/attenuation happens on all the individual channels, and the summing bus is just a "dumb" summing amplifier with equal input impedance see by every channel output (post channel gain).

\subsection{Digital Systems}
\label{ssec:digital-overview}

\subsubsection*{STM32G474}
For this project, the STM32 microcontroller was chosen. Specifically, we chose the ARM based STM32G474~\cite{stm32g474} variety, for its expansive I/O, deep analog integration with onboard DACs and ADCs, and its ability for standard-speed USB. We plan to run the CPU clock at its maximum speed of 170MHz. This will be more than enough processing power for our requirements. Additionally, our team already has a few Nucleo 64 development boards of this exact chip, allowing those to be excluded from the budget.

We will use an external 24MHz crystal oscillator on our final PCBs (exact same as the Nucleo boards) to simplify all of the different timers for busses running at different speeds. If the firmware will not fit on the chip's internal flash, we will add an SPI flash chip, on a separate SPI bus. This connection, while slow in today's standards, will be more than enough for the controller to access the program during operation.

\subsubsection*{Channel Buckets}
Each STM32 controller will be in charge of a "bucket" of four channels. We will make everything for this entire project as a set of 4 channels, and during final production, we will combine a few of these buckets together to create a console. The current goal is 16 channels, requiring 4 sets of 4-channel buckets. The numbers listed in the budget proposal are for this 16 channel configuration. However, if budget requires, the design can be reduced to 12 or 8 channels extremely easily, as a result of this bucket setup.

\subsubsection*{Master Section}
There will also be a simple master section with its own STM32G474. The master section does not need remote control, as all the processing will be done on the individual channels of audio. The master section is just a "dumb" summing bus which accepts the output of an arbitrary number of channels, with their respective gain factors already applied by the VCAs. The summing bus can then be fixed gain for each channel. The master section controller will mostly be to run the large center screen, which will allow for track naming and console setting configuration. This highly modular design allows a console with any number of channels (divisible by 4) to be created by using any number of individual buckets of 4 channels and a single master section.

\subsubsection*{Communication Between Devices and Pin Assignment}

The controllers will communicate with each other on an SPI (Serial Peripheral Interface) bus, but for the most part, communication between controllers is not needed, since each manages the signal path configuration of its own four channels, and the outputs from those channels just dump onto the main "dumb" summing bus with the processing and gain already completed. This bus will be mostly used for saving the console state, where the master section controller polls each of the bucket controllers for their channel parameter values. Each bucket will dump its numerous values of settings onto the bus, and the master controller will collect these and save them. Upon loading, the same thing will happen in reverse.

The STM32G474 has four $I^2C$ (Inter-integrated Circuit) buses and three SPI (Serial Peripheral Interface) buses. Each $I^2C$ bus consists of a clock pin and a data pin, carrying signals in both directions.  Multiple devices may communicate, with 3 bit addresses, allowing 8 addressable chips on the same bus. Each I2C bus will be used for one channel's chips, so all four I2C busses will be identical for simplicity, and we can address specific channels by changing which I2C bus we are communicating on. 

Each I2C bus will have three, MCP23017~\cite{mcp23017} GPIO expanders (giving 42 total input pins per channel = 168 additional GPIOs for each bucket/STM32). These pins will be connected to the physical control devices such as the rotary encoders and pushbutton switches. More information about GPIO expansion and control is in Section~\ref{ssec:gpio}. Each bus will also have five, MCP4728 quad DACs, for a total count of 20 control voltage DAC channels per console channel, which fits in the required number for the analog processors we plan to implement. More information about control voltage DACs is in Section~\ref{ssec:cv-dacs}.

The STM32 controller also has three SPI busses. Bus 1 will be configured as a 4-wire full duplex, in slave mode, where a master controller selects which chip to talk to. This is for the aforementioned communication between controllers and the master section. SPI bus 2 will be a 2-wire transmit only bus, which will be connected to all four of the small channel LCD screens. These screens only receive data and never send it. More information about the LCD screens is in Section~\ref{ssec:displays}.

Finally, the third SPI bus will be reserved for a potential SPI flash chip, if the onboard flash is not enough to contain the controller's firmware. We may also use dedicated ADC channels for the dynamic compressor sidechain (See Section~\ref{ssec:compressor}) and control voltage envelope generation. We might also move some things around, adding an SPI GPIO expander such as the MCP23S17 to this bus, to move signals like the fader touch sensors or display chip select pins, making room to use onboard ADCs for the compressor instead (See Figure~\ref{fig:pinlist}).

\begin{figure}[H]
    \centering
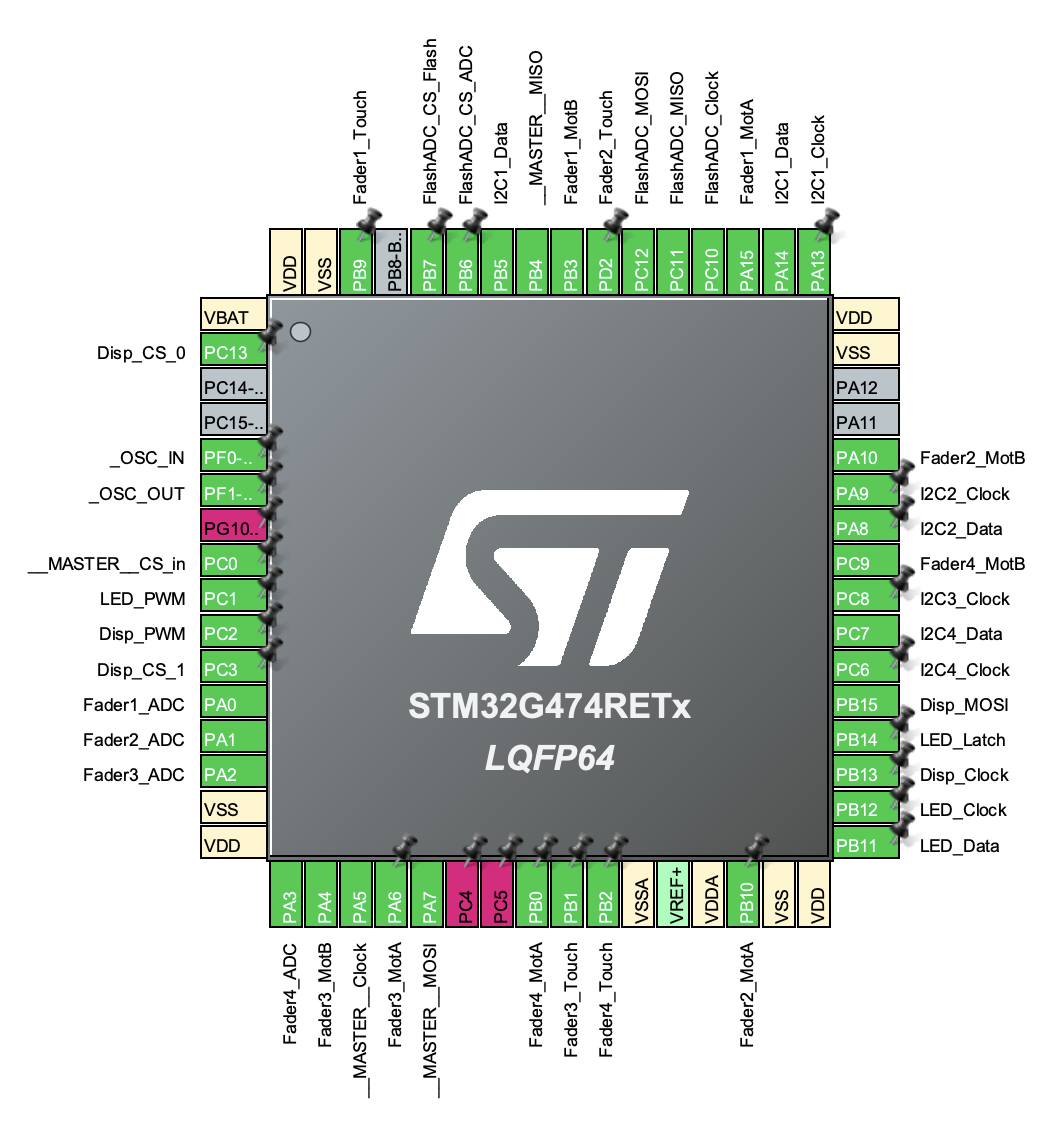
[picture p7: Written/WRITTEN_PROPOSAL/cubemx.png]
    
    \caption{Pin assignments in STM32CubeMX. PG10 is dedicated for reset only. PC4 and 5 are multiplexed with PA2 and 3, respectively on the Nucleo development board, and to reduce complexity, we just avoid PC4 and 5. This is for one bucket of 4 channels. PB8 is the boot mode pin, left open in case we need to tell the microcontroller to boot from the external SPI flash chip (if the firmware does not fit on internal flash)}
    \label{fig:cubemx}
\end{figure}

\begin{figure}[H]
    \centering
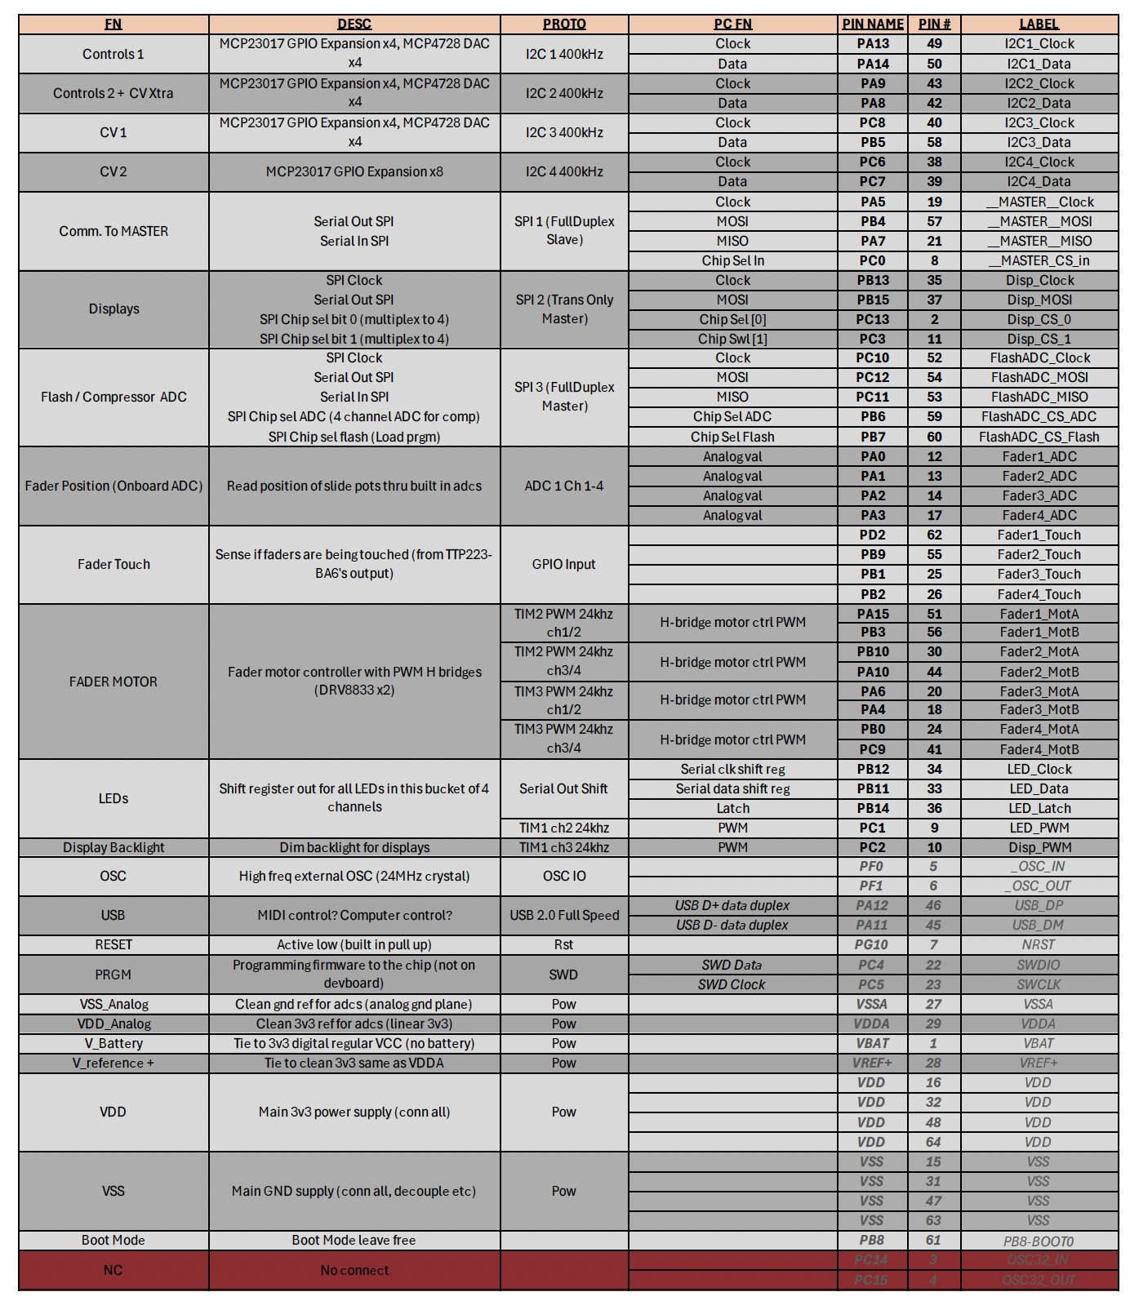
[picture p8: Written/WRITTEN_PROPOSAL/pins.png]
    
    \caption{Pin assignment listing. Some of the general purpose output pins may be moved to extra pins on the MCP23017s instead.}
    \label{fig:pinlist}
\end{figure}

10 pins are configured as pulse width modulation (PWM) outputs. 8 of these are for the fader motor H-bridge control (two for each motor, see Section~\ref{ssec:faders}). The other two pins are to change the brightness of the LCD backlights and of all the LEDs on the bucket of channels, through PWM on every LED driver shift register's output enable pin (See Section~\ref{ssec:gpio}). To keep potential audible noise out of the audio, all PWM signals will run at 24KHz or more, beyond human hearing.

Additionally (not shown in Figures~\ref{fig:cubemx} and~\ref{fig:pinlist}) we plan, if needed, to have a small temperature sensor IC for every bucket of channels, in order to reverse any performance drifts due to temperature. See Section~\ref{sssec:temperature} for more details.

\subsubsection*{RTOS}
Due to the anticipated complexity of the firmware, especially with its multiple busses running at different speeds and interrupts from various chips, a real-time operating system (RTOS) will be used to help schedule and organize parts of the firmware with various priority levels. This way, we can move away from the regular design of a huge, very complex single main loop which checks everything. We just will need to write individual programs or "tasks" and give them a priority level. We plan to use FreeRTOS~\cite{freertos}, which is a simple, open source RTOS that provides CPU scheduling. Being simpler than many other RTOS options, it does not provide memory management or built-in peripheral drivers, which would only complicate things, since we do not anticipate needing these. If we do need these things, we will switch to a more complex RTOS like Zephyr.

\newpage
\section{Technical Details}
\label{sec:technical}

This section contains descriptions and technical explanations of each system, in \textbf{\textit{as much detail as we currently have.}} A large amount of research and simulations, and some design and physical prototyping has already been completed, in order to verify the feasibility of these systems. Designs are subject to change.

\subsection{Voltage Controlled Amplification}
\label{sssec:vca}

To implement the variable gain, voltage controlled amplifiers (VCAs) will be used, which have a gain factor related to a control voltage. The first place that gain must be remotely controlled is in the input section, which takes in either a balanced line level (preamplified) signal, or a balanced quiet microphone signal. For line level inputs, an INA2137~\cite{ina2137} line input receiver with fixed unity gain will impedance balance and convert the double ended signal into a single ended signal for processing. A SSI2164~\cite{ssi2164} VCA will be used to vary the gain with remote control. For a microphone input, a PGA2500~\cite{pga2500} digitally controlled microphone preamplifier will be used on an SPI bus to allow control of the microphone gain. The PGA2500 does not need a control voltage, and thus does not need another control voltage DAC channel. Instead, the gain is digitally controlled through a control word sent on a serial bus.

\begin{figure}[H]
    \centering
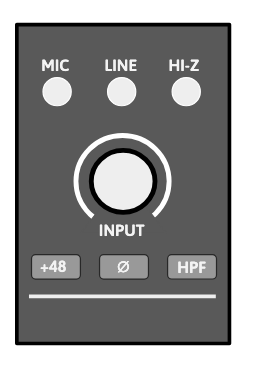
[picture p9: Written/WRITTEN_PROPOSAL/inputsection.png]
    
    \caption{Input section controls, at the top of each channel strip. Input knob controls gain applied by the VCA. The switches at the top select the source type. (MIC switches the input to pass through the PGA2500 preamplifier, and HI-Z switches in a resistor to increase the input impedance to accept direct input instrument signals from things like electric guitar coil pickups. The buttons on the bottom control the +48V phantom power for condenser microphones, phase polarity invert, and high pass filter, respectively. These functions are easy to implement with the PGA2500, but they are luxuries and will only be added if we have time.}
    \label{fig:input-section}
\end{figure}

The second place gain will need control is on the auxiliary send section, where variable amounts of audio from each channel may be summed to auxiliary signal buses for group external processing. These busses will be fed by VCAs, specifically the SSI2164~\cite{ssi2164}. The third place for voltage controlled gain is the feed into the main summing bus. For this, two VCAs (SSI2164s) will be used per channel. One VCA will feed the left channel summing bus, and the other VCA will feed the right channel summing bus. A pan (stereo panorama balance) knob will control the difference in gain between the two VCAs for each channel, and the channel fader (volume control) will scale both VCAs equally. 

\begin{figure}[H]
    \centering
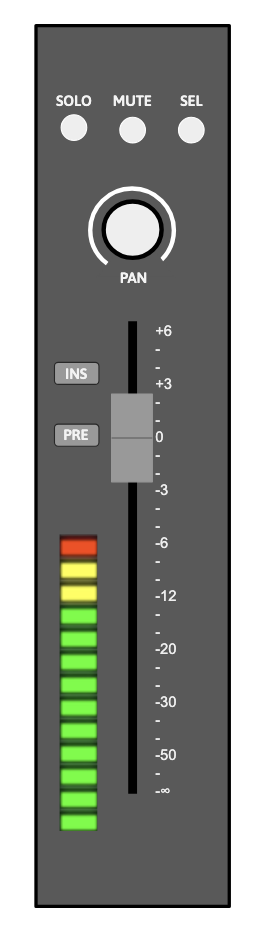
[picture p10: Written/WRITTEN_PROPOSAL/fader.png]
    
    \caption{Output section controls, at the bottom of each channel strip. The LED strip is a simple VU meter bar display implemented with a LM3916~\cite{lm3916}. The channel fader is shown (See Section~\ref{ssec:faders}), and the stereo pan(orama) balance control. SOLO mutes all other channels, MUTE mutes this channel, SEL selects the channel for functions like channel grouping or group parameter changes. INS switches the channel effects insert loop, which sends the audio out, to some external processor, and recieves it back as a line-level signal. PRE sets the source point for this effects loop to be before the application of the fader and pan VCA gain. (PREfader)}
    \label{fig:output-section}
\end{figure}

\subsubsection*{Component: PGA2500}

The PGA2500 digitally controlled microphone preamplifier~\cite{pga2500} accepts its gain setting as a number, so it needs no control voltage DAC. A
16-bit control word travels over a serial port using the SPI protocol. The gain range runs from
10\,dB to 65\,dB in 1\,dB steps, with a separate unity gain setting. Several
devices may share one port in a daisy chain, which keeps the wiring count low across a
large number of channels. The device also provides four programmable digital outputs. These
outputs drive the pad, the phantom power supply (for condenser / capacitance microphones), the high-pass filter, and the
polarity reverse relay.

The zero-crossing detector delays each gain change until the input signal
crosses zero. This limits the glitch energy from the switched gain network, preventing pops and clicks on the output. A
channel with no input signal therefore shows some delay before the new gain
takes effect. Preamplifier recall is exact, since a switched resistor network sets
the gain, and no control voltage takes part.

\subsubsection*{Component: SSI2164}
The SSI2164~\cite{ssi2164} provides four VCAs in one package. Each VCA takes a current input,
produces a current output, and accepts a ground-referenced control port. The
control law is exponential:
%
\begin{equation}
    V_C = -\left(33\,\mathrm{mV/dB}\right) G ,
    \label{eq:vca-law}
\end{equation}
%
where $G$ is the gain in decibels. A control span of $-660$\,mV to $+3.3$\,V
therefore covers the full range of $+20$\,dB to $-100$\,dB. We can just cap the lowest control voltage to 0V, so we do not need CV amplifiers. We will still need a buffer.

Noise on the control port becomes gain modulation, so the control path needs
care. Noise of 1\,mV RMS produces sidebands about 55\,dB below the signal. Our DACs have a nominal noise voltage of $290\mu$V peak-to-peak~\cite{mcp4728} so as long as we are careful to not add much more noise, it will not be an issue. See Section~\ref{ssec:cv-dacs} for more information on the control voltage converters.

\subsection{Voltage Controlled Resistors}
\label{ssec:vcr-sec}

Parts of the channel need a variable resistance and not a variable gain. The
equalizer corner frequencies and the filter $Q$ are the main examples. We plan to use operational transconductance amplifiers (OTAs) to implement this voltage controlled resistance, specifically the LM13700~\cite{lm13700}, for its output Darlington buffers and linearizing diodes, which help it achieve a THD of $<1\%.$  For the
LM13700 OTA~\cite{lm13700}, transconductance follows the amplifier
bias current:
%
\begin{equation}
    g_m = \frac{I_\mathrm{ABC}}{2 V_T} ,
    \qquad
    R_\mathrm{eq} = \frac{1}{g_m} = \frac{2 V_T}{I_\mathrm{ABC}} ,
    \label{eq:ota-gm}
\end{equation}
%
where $V_T = kT/q$ is the thermal voltage. A bias current from 1\,$\mu$A to
500\,$\mu$A gives a resistance from about 51\,k$\Omega$ down to about
100\,$\Omega$. Three decades of range cover a wide sweep of one corner
frequency. To achieve that though, we will have to amplify the control voltages, mapping their small 0-3.3V range to something near $+/-15V$. The VCAs do not need this amplification.

A standard, real resistor will convert this buffered and amplified voltage into the biasing control current.
Transconductance follows bias current in a linear way, so corner frequency also
follows the control DAC code in a linear way. A lookup table in the control
processor maps a target frequency to the correct code. The analog circuit
therefore needs no exponential converter.

The OTA stays linear only for small differential input voltages. In most existing designs, a resistive voltage
divider holds the signal at the OTA input below about 20\,mV peak. The
linearizing diodes extend this limit. We will do both.

\subsubsection*{Component: LM13700}

\label{sssec:vcr}

The LM13700~\cite{lm13700} is a dual operational transconductance amplifier, manufactured originally by National Semiconductor, and now TI. Unlike an op-amp (which is a voltage controlled voltage source), OTAs produce an output CURRENT proportional to the differential input voltage, just like a resistor. The scaling factor (the effective resistor value) is set by an external amplifier bias current: $gm = I_ABC / 2V_T$, or roughly 19 mS per mA of bias at room temperature. OTAs have been widely used in music circuits, most commonly in synthesizers, in voltage controlled filters.

Each of the two channels adds linearizing diodes and a Darlington buffer. The Darlington buffer helps drive loads at the output without loading the real output of the OTA which can affect its performance. The
diodes take advantage of linearizing distortion, which predistorts the signal in a way such that the OTAs nonlinearities will undo this distortion.

The bare differential pair inside the OTA follows a hyperbolic tangent:
%
\begin{equation}
    I_\mathrm{out} = I_\mathrm{ABC} \tanh\!\left( \frac{V_\mathrm{in}}{2 V_T} \right) .
    \label{eq:ota-tanh}
\end{equation}
%
This curve stays linear only near the origin, which is why the bare part needs a
small input signal. The linearizing diodes place the inverse of that curve in
front of it. Two diode-connected transistors split a bias current $I_D$ around
the signal current $I_s$, so the voltage across the pair follows a logarithm:
%
\begin{equation}
    \frac{V_D}{2 V_T}
    = \frac{1}{2} \ln\!\left( \frac{I_D/2 + I_s}{I_D/2 - I_s} \right)
    = \operatorname{artanh}\!\left( \frac{2 I_s}{I_D} \right) .
    \label{eq:ota-diode}
\end{equation}
%
The differential pair then applies $\tanh$ to this result, and the two functions
cancel exactly:
%
\begin{equation}
    I_\mathrm{out} = \frac{2 I_\mathrm{ABC} I_s}{I_D} .
    \label{eq:ota-linear}
\end{equation}
%
The output is therefore linear in $I_s$, and the thermal voltage cancels with
the curvature. Both functions come from the same junction physics on one die, so
the cancellation holds across temperature. The signal current must stay below
$I_D/2$, because one diode starves at that limit and the logarithm fails.

\subsection{Calibration and Temperature Sensitivity}
\label{sssec:temperature}

The gain constant in Equation~\eqref{eq:vca-law} and the thermal voltage in
Equation~\eqref{eq:ota-gm} both scale with absolute temperature. This is the
largest threat to recall accuracy in the channel.

If we use the linearizing diodes provided for each OTA on the LM13700 chip (mentioned just above), we can greatly reduce the temperature dependency of the OTAs (Equation (2)), leaving the SSI2164 VCAs as the main problem.

The gain constant of the SSI2164 rises with absolute temperature. A rise of
30\,$^\circ$C moves the constant from about 33\,mV/dB to about 36\,mV/dB. A
control voltage stored for 40\,dB of attenuation then produces about 36\,dB.
The error grows with distance from unity gain and falls to zero at 0\,dB. The
thermal voltage $V_T$ drifts in the same manner. The equivalent resistance
rises by about 0.33\,\% per $^\circ$C, and any corner frequency set by that
resistance falls by the same fraction.

We correct this drift in the following way. A resistor with a $+3300$\,ppm/$^\circ$C
coefficient scales the control voltage at each SSI2164 control port. If needed, we will also add a temperature sensor to the board. The
control processor would read it and and trim the
control DAC codes to account for the different temperature. This sensor correction could handle the residual error and the
slow drift of the voltage reference.

\subsubsection*{Recall Sequence}
\label{sssec:recall}

Reconfiguring the console's state follows a fixed order. This order prevents transients at the output.

\begin{enumerate}
    \item Ramp the channel VCA to full attenuation.
    \item Write the routing, pad, polarity, and phantom power states.
    \item Write the gain word to the PGA2500.
    \item Write the control DAC codes for the voltage-controlled resistors.
    \item Wait for the control filters to settle.
    \item Ramp the channel VCA to the stored control voltage.
\end{enumerate}

\subsection{State-Variable Filter Equalizer}
\label{ssec:eq}

\subsubsection*{State Variable Filter Core}
\label{sssec:svf}

Each band uses a state variable filter. The topology of a state variable filter is a loop of one summing
amplifier and two integrators. The output of the second integrator returns to
the summing input. Three useful outputs appear at different points in this loop. The summing amplifier's output
gives a high-pass response, the first integrator's output gives a band-pass response, and
the second integrator's output gives a low-pass response. One filter therefore supplies every shape
the band needs, and a switch (DG409) selects between them.

To build a four band equalizer, the signal is sent in parallel through four state variable filters. The output from each filter, set by the audio engineer to the desired frequency, band type, and bandwidth, is summed using a configurable gain factor and placement in the circuit to switch between cut and boost, with the raw input signal. Leaving all bands' gains at 0 will not affect the input signal, no matter their frequency or Q setting.

Traditionally, a resistor and a capacitor form each integrator. However, to implement voltage controlled center frequency, we replace the resistor with an OTA, keeping the capacitor constant and hardwired. Equation~\eqref{eq:ota-gm} of
Section~\ref{sssec:vcr} gives the transconductance, so the corner frequency
follows the bias current:
%
\begin{equation}
    \omega_0 = \frac{g_m}{C} = \frac{I_\mathrm{ABC}}{2 V_T C} .
    \label{eq:svf-freq}
\end{equation}
%
Both integrators must have an identical resistance, so there will be two OTAs for frequency, but both will be controlled by one control voltage / current. A third path and OTA sets the bandwidth, or quality factor, Q. The band-pass output returns to the summing node through a
damping coefficient, and Q is the reciprocal of that coefficient. The third OTA  therefore makes Q variable.

\begin{figure}[H]
    \centering
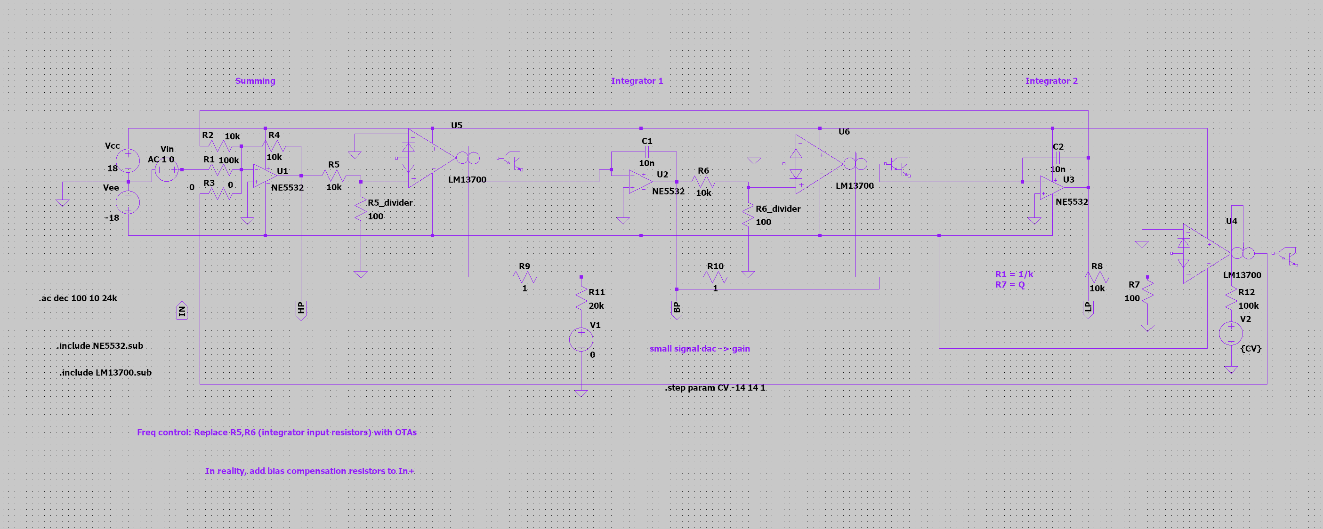
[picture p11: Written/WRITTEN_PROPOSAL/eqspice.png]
    
    \caption{A single variable state filter configured with voltage-controlled center frequency and Q factor, in LTSpice.}
    \label{fig:svf-schematic}
\end{figure}

\begin{figure}[H]
    \centering
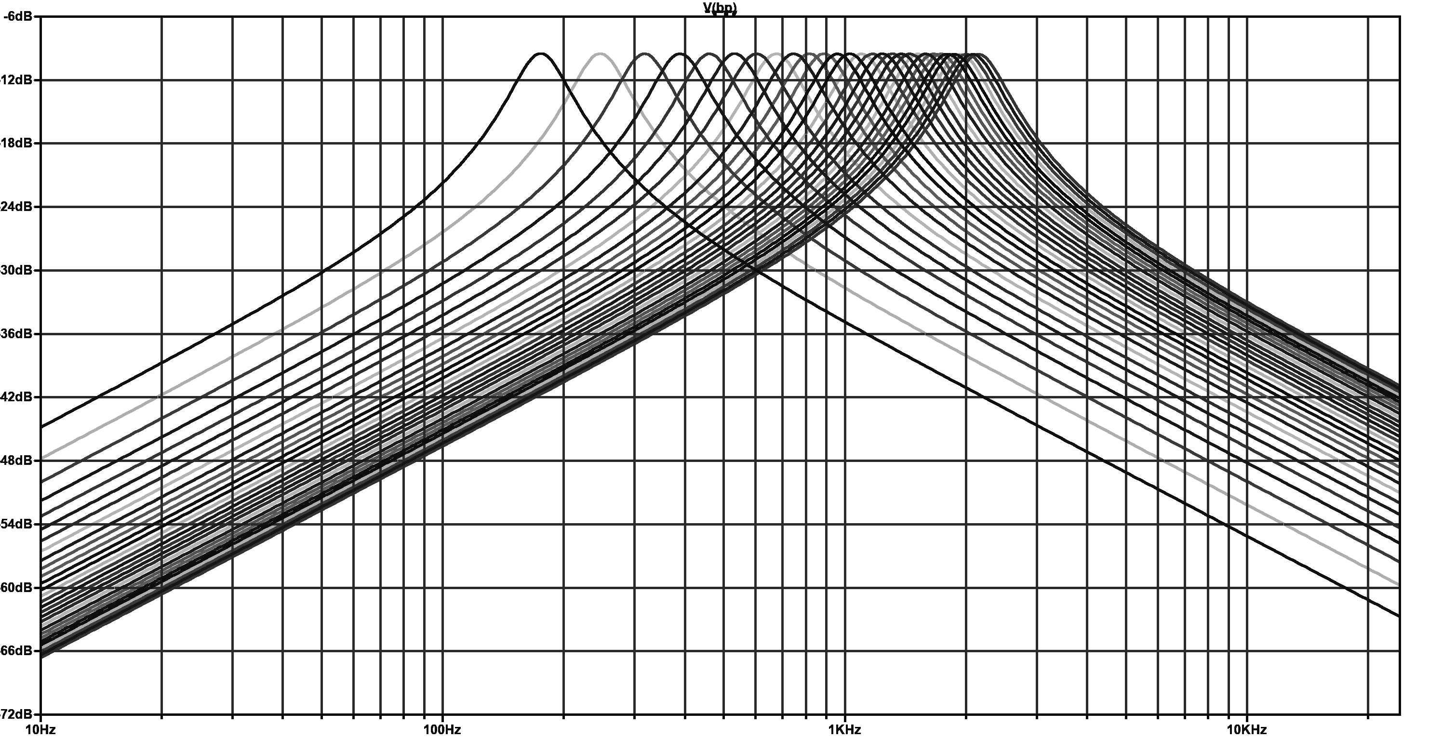
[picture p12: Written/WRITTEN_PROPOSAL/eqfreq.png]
    
    \caption{Output frequency response at the band pass output, during a sweep of the frequency control voltage from -14V to +14V with 1V steps. Q is kept constant. Frequency follows the same direction as voltage, so when voltage increases, so does frequency. For the other 3 in other frequency ranges, this circuit may be duplicated and the integration capacitor value changed.}
    \label{fig:svf-freq-sweep}
\end{figure}

\begin{figure}[H]
    \centering
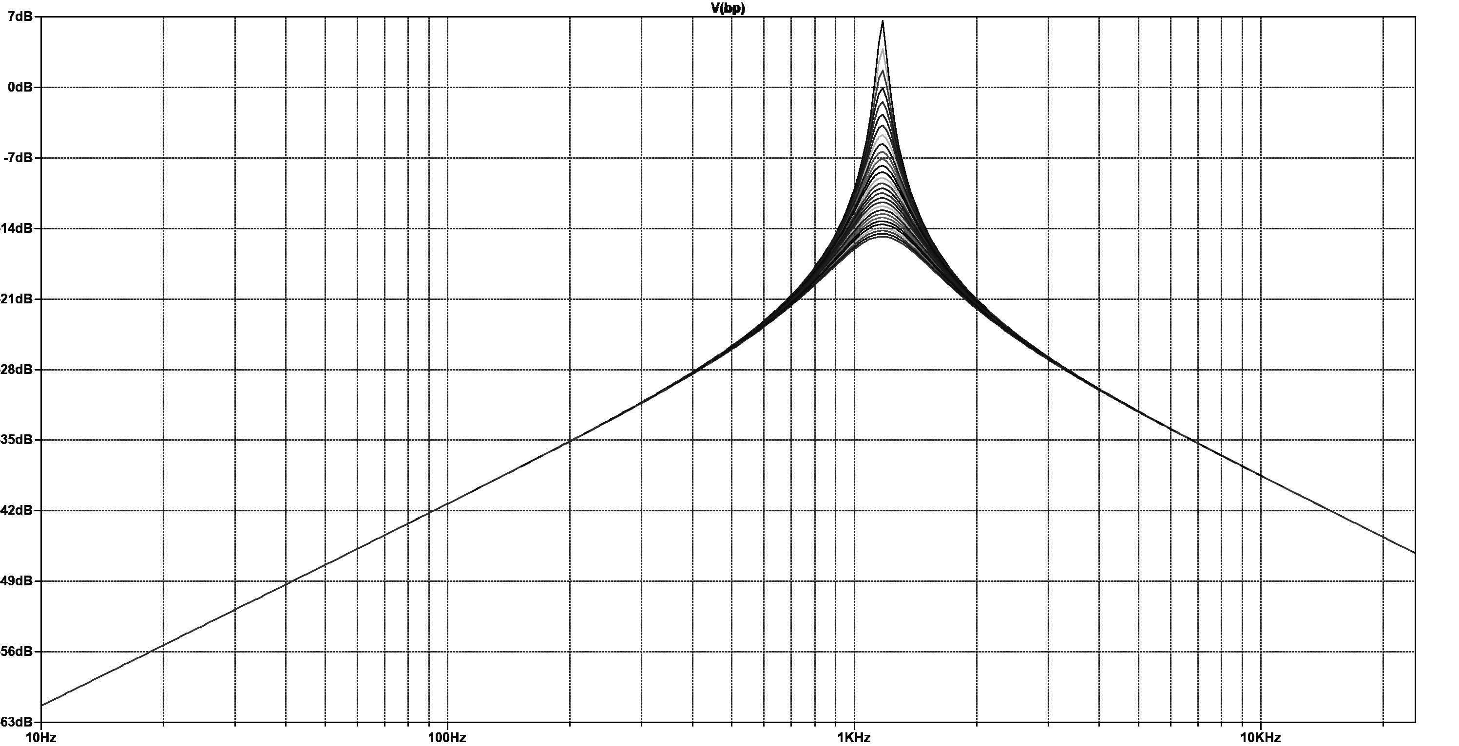
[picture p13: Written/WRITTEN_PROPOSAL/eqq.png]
    
    \caption{Output frequency response at the band pass output, during a sweep of the Q control voltage from -14V to +14V with 1V steps. Frequency is kept constant.}
    \label{fig:svf-q-sweep}
\end{figure}

\subsubsection*{Band Types and Switching}
\label{sssec:eq-bands}

The two middle bands are bells with variable frequency, Q, and gain. They take
the band-pass output only, with no option to switch to shelves. The top and bottom bands are shelves that may be switched to bells, with variable
frequency and gain and a constant Q. A shelf comes from the low-pass or the
high-pass output of the filter circuit summed with the direct signal. A DG409 CMOS signal multiplexer selects which filter output reaches the gain stage for the top and bottom band. This part is a dual
4-to-1 multiplexer, so one device covers every mode of two bands. Its on
resistance is a few hundred ohms, so each switch feeds a summing node rather
than a high impedance node, which keeps the resistance out of the response. The low band selects its low-pass output for a shelf or its band-pass
output for a bell. The high band does the same with its high-pass output. Further DG408~\cite{dg409} devices bypass the whole
equalizer and reorder it against the compressor.

\subsubsection*{Boost and Cut}
\label{sssec:eq-gain}

Gain is the one parameter that a single OTA cannot supply well, because boost
and cut of frequency bands on an equalizer need opposite signs and a reciprocal shape. The design uses one SSI2164
VCA channel per band, so one package serves all four bands. The VCA sets the
magnitude of the filter contribution. In the frequency domain, using $B(s)$ for the selected filter's
output and $K$ for the VCA gain:
%
\begin{equation}
    H_\mathrm{boost}(s) = 1 + K B(s) ,
    \qquad
    H_\mathrm{cut}(s) = \frac{1}{1 + K B(s)} .
    \label{eq:eq-gain}
\end{equation}
%
The two forms are reciprocals, so a cut of 6\,dB mirrors a boost of 6\,dB. One
analog switch chooses between them. It places the VCA output at the summing node
for a boost, and inside the feedback path of the summing amplifier for a cut.

The switch never clicks, because of where it operates. The two forms meet at
$K = 0$, which is the flat setting. The control processor drives the VCA to full
attenuation before it moves the switch. 
The VCA follows an exponential law, and a boost in decibels needs a linear value
of $K$. A lookup table in the control processor performs this conversion. The
analog circuit needs no linearizing network, which is a direct benefit of
digital control.

\subsubsection*{Control Voltage Budget}
\label{sssec:eq-cv}

Each (middle two) bell band takes three control voltages for frequency, Q, and gain. Each (outer two)
shelf band take two, because their Q will be fixed. The equalizer therefore uses ten
of the twenty control voltages that Section~\ref{ssec:cv-dacs} provides for a
channel. The remaining ten serve the fader, the pan control, the compressor, and
the sends.

\subsubsection*{Control Surface}
\label{sssec:eq-surface}

The panel holds four frequency encoders and four gain encoders. A potentiometer in a
conventional console sits in the signal path, so each parameter needs its own
potentiometer. Here, an encoder produces a number and touches no audio. The same encoder
can therefore serve several parameters, and the panel carries far fewer controls
than the channel has parameters.

The design uses this freedom twice. The four gain encoders carry push switches,
described in Section~\ref{ssec:gpio}. A held push switch turns the same encoder
into the Q control for that band. The two shelf bands hold a constant Q, so
their push switches select between shelf and bell instead.

Three buttons above the section form a radio group, and one lamp stays lit. They
point the whole encoder group at the equalizer, at the compressor, or at the
sends. Later sections describe those two processors. The encoder rings and the
channel display redraw on every change of layer, so the panel always reports the
parameters that the encoders now hold.

\begin{figure}[H]
    \centering
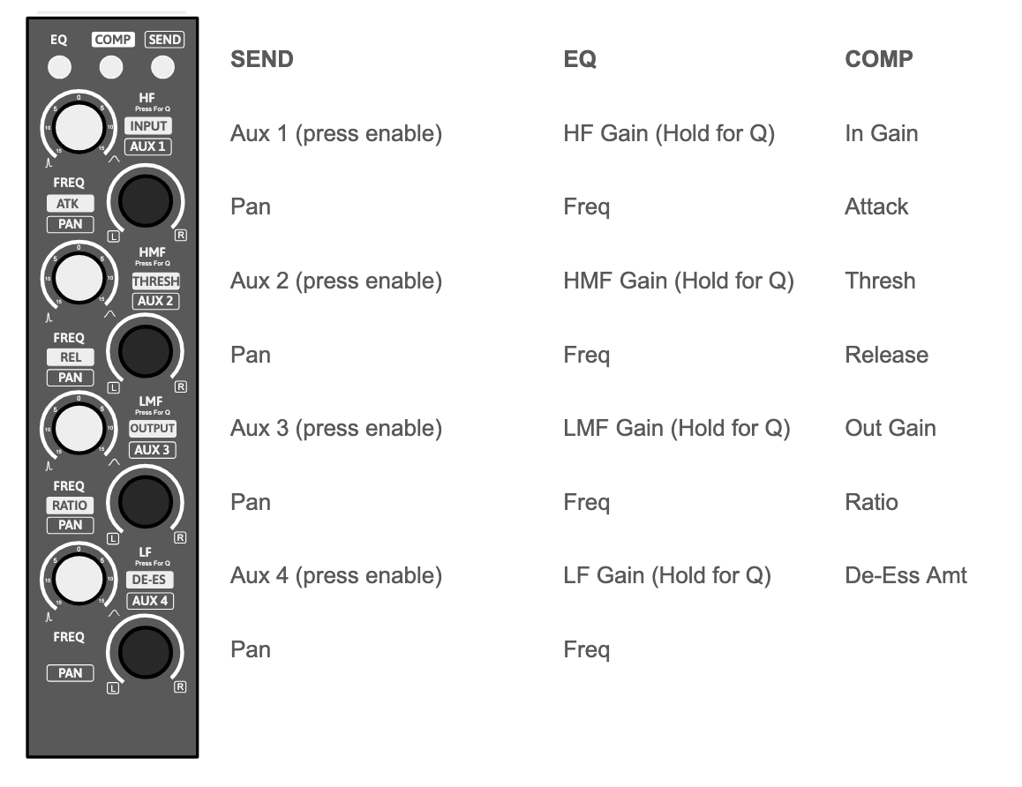
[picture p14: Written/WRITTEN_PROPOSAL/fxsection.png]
    
    \caption{Since we have separated the control from the parameter being controlled, one encoder can be used for multiple functions. The audio engineer may select which part of the channel processing they are controlling with the "digital radio buttons" at the top.}
    \label{fig:fx-section}
\end{figure}

A single press of a radio button selects which effect is being controlled. We also plan to add three additional control options using the existing buttons, improving flexibility and ergonomics. A double tap bypasses that processor and a second double tap restores it.
A held press resets the parameters of that processor. A held press of the
equalizer button and the compressor button together for three seconds exchanges
the order of the two processors in the chain. The control processor mutes the
channel across this last change, to prevent clicks, because it rearranges the analog path.

\subsection{Dynamic Range Compressor}
\label{ssec:compressor}

A compressor reduces the dynamic range of a signal: once the input rises above a set threshold, the compressor turns the gain down, so loud passages are pulled closer to quiet ones. Engineers use compressors to keep a vocal or bass sitting at a more constant volume in a mix rather than jumping forward and disappearing, and because the whole signal can be turned up to make a track sound louder and more consistent without clipping on previously loud parts, after compression is applied.

The compressor splits along the same line as the rest of the console. The
detector is digital and the audio path is analog. Four high-speed
analog-to-digital converters sit on either the third SPI bus (See Section~\ref{ssec:digital-overview}), or some pins will be rearranged and the onboard ADCs used. There will be one ADC for each channel, and
they report the signal to the control processor. This is the only time we will ever read the audio signal in digitally, but it is not for digital processing. The digitized signal will never be converted back; it is just to generate a control voltage envelope. From this audio signal, the processor computes the
gain reduction from the threshold, the ratio, the attack, the release, and the
makeup gain settings. It then drives one SSI2164 channel, and that VCA does the work on
the audio.

This arrangement costs little. The converters never touch the audio path, so
they need no audio-grade linearity. Only their magnitude accuracy matters. A
16-bit part gives 96\,dB of detection range, which covers the working range of
the compressor with room to spare. Four channels at a 48\,kHz sample rate and 16
bits produce 3.1\,Mbit/s, or about a third of a 10\,MHz SPI bus. The detector
arithmetic costs near 11\,\% of the processor.

\subsubsection*{The Sidechain Needs Its Own Path}
\label{sssec:comp-latency}

One constraint governs the design. The control voltage of the compressor must
not travel through the shared converters of Section~\ref{ssec:cv-dacs}. That
path updates at 400\,Hz and smooths its output with a 100\,Hz pole. The attack
time would then never fall below about 4\,ms, and no setting could recover it.

The sidechain therefore carries its own converter, on the same SPI bus as the
analog-to-digital converters and at the same sample rate. A reconstruction pole
near 5\,kHz follows it, which gives a time constant of 32\,$\mu$s. The whole
detection loop stays on one fast bus, and the slow control plane sets only the
five parameters.

The audio path holds no delay, so the detector cannot look ahead. The gain
reduction always arrives a little after the event that caused it. This suits a
program-dependent leveling compressor well. It does not suit a peak limiter, and
the paper does not claim one.

\subsubsection*{What Software Detection Adds}
\label{sssec:comp-software}

Several features arrive at no extra cost in parts. The sidechain filter is a few
lines of code, so the detector can ignore low frequencies without an analog
network. The detector law is a choice rather than a circuit, so peak and RMS
behavior both become settings. A soft knee and a program-dependent release cost
nothing further. Additionally, the console may be set up to feed other channels' signals into the sidechain ADC, allowing sidechain linking compression between sources, allowing the engineer to for example, have the bass dynamically duck during kick drum hits. Still, the actual audio signal travels through a fully analog path, as the ADCs are only to read the levels and generate the compressor CV envelope. The gain reduction is applied by analog VCAs.

Metering also comes free. The processor already holds the gain reduction as a
number, so the channel display of Section~\ref{ssec:displays} needs no
measurement circuit to draw it.

\subsubsection*{De-esser Mode}
\label{sssec:comp-deess}

A switched crossover turns the compressor into a de-esser. A DG409 routes the
audio through a first-order high-pass and low-pass pair with a corner near
5\,kHz. The VCA then acts on the high band alone, and the two bands rejoin at a
summing amplifier. A first-order pair sums back to a flat magnitude response, so
the recombined signal stays correct when the compressor is idle. The processor
also moves its sidechain filter to match, so the detector responds only to the
band that the VCA controls.

The detector tap follows the chain order. Section~\ref{ssec:eq} describes the
switch that exchanges the equalizer and the compressor, and the same switch
moves the point at which the analog-to-digital converter reads the signal.

\subsection{Motorized Faders}
\label{ssec:faders}

Each channel carries one Alps RSA0N fader~\cite{rsa0n}. This is a 100\,mm motorized slide
potentiometer with a 10\,k$\Omega$ linear track and a touch sense track. The
fader does two jobs and only two. It reports where the hand put it, and it shows
where the stored value sits. The audio never reaches the resistive track.

A
conventional console passes the signal through the fader track, so a worn or
dirty track produces crackle in the audio. Here, the track carries a steady
direct voltage and nothing else. A noisy track produces a noisy reading, and
software removes that noise before the reading becomes a control voltage. The
track needs to be readable, not quiet.

\begin{figure}[H]
    \centering
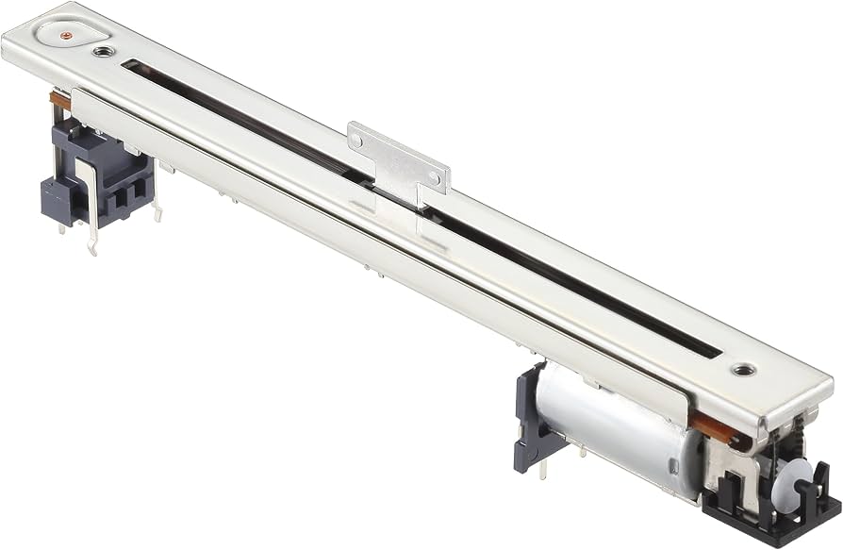
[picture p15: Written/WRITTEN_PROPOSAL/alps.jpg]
    
    \caption{An Alps 100mm motorized fader, part number RSA0N11M9}
    \label{fig:alps-fader}
\end{figure}

\subsubsection*{Position Sensing}
\label{sssec:fader-sense}

The top of the track connects to VDDA at 3.3\,V, and the bottom connects to
analog ground. The wiper therefore returns a fraction of VDDA. This voltage
reaches an analog-to-digital converter inside the STM32G474~\cite{stm32g474}, and one converter
channel serves each of the four faders. The maximum operating voltage of the
track is 10\,V DC~\cite{rsa0n}, so 3.3\,V leaves a wide margin.

VDDA also serves as the reference for the converter, as
Section~\ref{ssec:cv-dacs} describes. The reading is therefore ratiometric. A
drift of VDDA moves the track voltage and the reference together, and the
reported position does not change.

A 1\,k$\Omega$ resistor and a 10\,nF capacitor sit at each converter input. The
capacitor supplies the charge that the sampling network demands, and the pair
also removes noise that the motor drive couples into the wiper. The converter
runs with hardware oversampling, which averages the contact noise of the track.
Twelve bits across 100\,mm of travel give 41 counts per millimetre, or one count
every 24\,$\mu$m. The mechanical repeatability of the fader is far coarser than
this, so the converter never limits the result.

\subsubsection*{Motor Drive}
\label{sssec:fader-motor}

A DRV8871~\cite{drv8871} drives each motor. The device holds one full H-bridge and accepts two
logic inputs, so each motor uses two pins on the processor. One input carries
the PWM signal and the other stays static, and the pair that carries the PWM
sets the direction. Both inputs high shorts the motor windings and brakes.

The motor rail is a dedicated 10\,V supply, which falls comfortably within the supply range of the DRV8871 and is the recommended motor voltage of the Alps RSA0N series. A resistor on the ILIM pin sets a hard ceiling on current, and this ceiling does
not depend on the duty cap. The datasheet gives 32\,k$\Omega$ for a limit of
2\,A~\cite{drv8871}. The fader motor needs far less, so the design sets the limit just above
the stall current of the motor. The driver also protects itself against a short
circuit and against overtemperature.

The PWM runs at 25\,kHz. This frequency sits above the audio band, so the motor produces no whine that a listener can hear.

\subsubsection*{Touch Sense}
\label{sssec:fader-touch}

A TTP223-BA6~\cite{ttp223} capacitive sensor watches the touch track of each fader. Its output
reaches one input pin on the processor, so four pins serve the four faders.

The sensor reports whether a hand is on the fader by repeatedly charging the metal fader cap and reporting capacitance via charge time. A human has additional capacitance, so when the user touches the fader, their capacitance is added to the detected amount, and the charge time increases. This way, a
knocked fader or a resting cable moves the fader, but without activating the sensor. Without the TTP223, that movement would overwrite the stored value. With
the sensor, the loop treats the movement as an error, since no finger was detected, drives the fader back, and
leaves the stored value alone.

\subsubsection*{Position Loop}
\label{sssec:fader-loop}

The fader position sensing loop runs at 1\,kHz on the processor. It needs no traffic on the
I\textsuperscript{2}C bus, because the converter and the timers are onboard the STM32 chip. The loop watches the fader's position as it
drives and actively corrects the position in a feedback loop. \textit{The fader position is updated by the value in memory}. An error in the position of the fader in this state will not effect the actual gain value stored in memory. However, when the fader is touched, this is stopped, so the audio engineer can freely move the fader, and \textit{the value in memory is updated from the fader position}.

\subsection{LCD Displays}
\label{ssec:displays}

The knob rings, the motorized fader, and the button lamps already report
position and state. They cannot report a name, and they cannot report a shape.
A small display adds these two things. Each channel strip carries one Adafruit
4421 module~\cite{ada4421}, which holds a 1.54\,inch IPS panel of 240 by 240 pixels and an
ST7789 controller~\cite{st7789}. The screen shows the track name, the transfer curve of the
equalizer, and the gain reduction of the compressor. Adafruit supplies this
part as a bare module on a flexible cable, so each strip also needs a small
connector for the 22 pin "flat-flex" ribbon cable.

One controller board drives four screens on a single SPI bus configured as transmit only (no data return from screens to controller). The four modules will 
share the clock line and the data line (MOSI). Each module receives its own chip select line. Two pins on the controller will be used to select the module to talk to using a two bit number. A 2-to-4 decoder generates the four chip select lines and saves two pins on the processor. The backlight of all four displays will be controlled by another pin, and pulse width modulation (PWM) will be used to vary its brightness.

Bus bandwidth sets the whole update strategy. A full frame holds 57,600 pixels
at 16 bits per pixel, or 115,200 bytes. A clock of 40\,MHz therefore needs
23\,ms for one full frame, and 92\,ms for all four screens. A screen that always
redraws in full is too slow for a meter.

The ST7789 holds its own frame memory. The controller sets an address window
and then writes only the pixels inside that window. The design uses this
feature and divides each screen into three zones.

\begin{itemize}
    \item The track name changes only on a rename or a snapshot recall. The
          controller redraws this zone on that event.
    \item The equalizer curve changes only when the user moves an encoder. One
          hand moves one encoder, so at most one channel redraws this zone at
          a time.
    \item The gain reduction meter changes all the time, so this zone stays
          small. A bar of 16 by 200 pixels needs 6400 bytes, or 1.3\,ms. Four
          meters at 30 updates per second use about 15\,\% of the bus.
\end{itemize}

A full frame buffer for four screens would need 461\,kB of memory, and the
controller does not hold one. The controller renders one tile at a time into a
small buffer instead. A tile of 240 by 32 pixels needs 15\,kB. The controller
keeps two tiles and uses DMA. The processor draws into the second tile while
the DMA engine sends the first tile to the bus. It is likely that during design, we will sacrifice colors to reduce the bits per pixel, in order to increase framerate. We also plan to have a single, larger display in the center / master section, for the user to configure settings and save and load console states.

\subsection{GPIO Expansion and Control Hardware}

\label{ssec:gpio}

Every control on a channel strip reaches the processor through the same three
MCP23017 expanders~\cite{mcp23017} that share the I\textsuperscript{2}C bus with the converters.
Each expander carries 16 pins, but two of them cannot serve as inputs. Microchip
advises that GPA7 and GPB7 drive outputs only, because those pins react to noise
and can corrupt the bus~\cite{mcp23017}. Each expander therefore offers 14 input pins, and three
expanders offer 42.

The channel needs exactly 42. Ten EC11 encoders~\cite{ec11} use two pins each for their
phases. Six of those encoders also carry a push switch. Sixteen buttons take the
rest. The budget closes with nothing spare, so any later control needs a fourth
expander. The six output-only pins remain available for indicators.

\subsubsection*{Pin Allocation}
\label{sssec:pin-allocation}

Allocation is not free choice. The expander latches a whole port at one instant,
so the two phases of one encoder must sit in the same port byte. Phases split
across two ports, or across two devices, would arrive from two different reads.
The decoder would then see a transition that never happened.
Table~\ref{tab:pin-allocation} keeps every encoder inside one port.

\begin{table}[t]
\centering
\caption{Input allocation for one channel. Each port supplies seven usable
pins, because pin 7 of each port drives outputs only.}
\label{tab:pin-allocation}
\begin{tabular}{l l l}
\toprule
\textbf{Device} & \textbf{Port A} & \textbf{Port B} \\
\midrule
Expander 1 & Encoders 1 to 3, 1 button & Encoders 4 and 5, 3 buttons \\
Expander 2 & Encoders 6 to 8, 1 button & Encoders 9 and 10, 3 buttons \\
Expander 3 & 6 push switches, 1 button & 7 buttons \\
\bottomrule
\end{tabular}
\end{table}

\subsubsection*{Encoder Signals}
\label{sssec:quadrature}

The EC11 is an incremental encoder with quadrature output. It holds two contact
sets that open and close a quarter cycle apart. One phase leads the other, and
which phase leads gives the direction of rotation. The encoder reports no
absolute position and no rate. It reports only steps and direction.

The processor decodes each encoder with a small state machine. The two phases
form a 2-bit value, and one detent produces one full cycle of that value. A
valid step changes exactly one bit. A table of 16 entries maps the previous
value and the new value to a count of $+1$, $-1$, or zero. A change of both bits
at once cannot occur on a real rotation. The state machine treats that case as a
lost sample, discards it, and resynchronizes on the next valid step. This rule
matters more than raw speed. A fast turn may lose a count, but the machine never
produces a count in the wrong direction.

\subsubsection*{Contact Debounce}
\label{sssec:debounce}

Mechanical contacts bounce for one to five milliseconds. The expander cannot
help with this on its own. Its internal glitch filter removes pulses shorter
than 150\,ns~\cite{mcp23017}, which suppresses electrical noise but not a bouncing contact.
Every input therefore passes through an RC network first.

Each input uses a 10\,k$\Omega$ pull-up to the rail and a 1\,k$\Omega$ resistor
in series with the contact. A capacitor to ground completes the network. The
series resistor also limits the discharge current through the contact to about
3\,mA, which extends contact life. The GPIO pins of the MCP23017 are Schmitt
trigger inputs. They switch at 0.2\,VDD and 0.8\,VDD~\cite{mcp23017}, so the hysteresis band
covers nearly 2\,V at a 3.3\,V rail. A slow edge through that band produces one
clean transition and no repeat.

Two capacitor values serve two needs. Buttons use 100\,nF, which gives an edge
of about 1.8\,ms and removes all normal bounce. Encoder phases use 22\,nF, which
gives an edge of about 0.4\,ms. The encoder needs the faster network because its
phases change far more often than a button does. A fast turn of three
revolutions per second on a 20 detent encoder produces 240 transitions per
second, or one transition every 4\,ms.

\begin{figure}[H]
    \centering
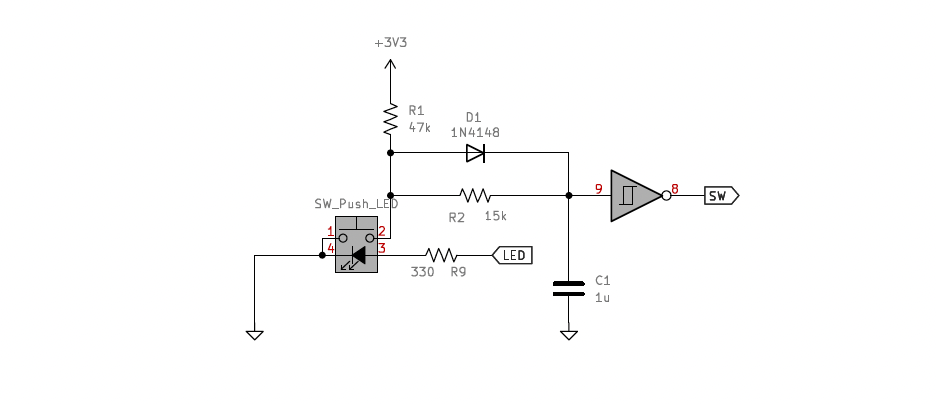
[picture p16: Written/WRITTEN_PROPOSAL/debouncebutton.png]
    
    \caption{A debounce circuit for push buttons, with debounce time about 15ms. The Schmidt trigger is already present on the MCP23017 input pins, so an additional one does not needed to be added. We would plug node 9 straight into the MCP23017.}
    \label{fig:debounce-button}
\end{figure}

\begin{figure}[H]
    \centering
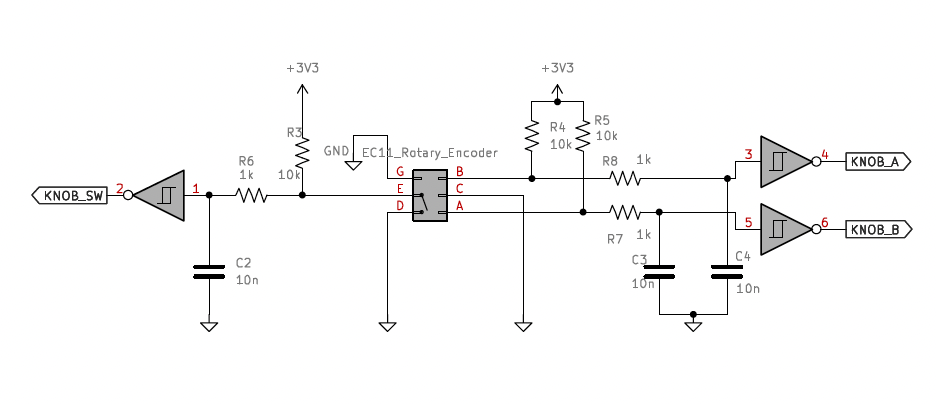
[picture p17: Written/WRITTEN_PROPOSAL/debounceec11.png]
    
    \caption{A debounce circuit for the EC11 rotary encoder, with both rotary step debouncing (KNOB\_A and KNOB\_B) and debouncing of the push switch (pressing the knob down, KNOB\_SW). The Schmidt triggers are already present on the MCP23017 input pins, so additional ones do not needed to be added. We would plug nodes 1, 3 and 5 straight into the MCP23017.}
    \label{fig:debounce-encoder}
\end{figure}

\subsubsection*{Interrupt Handling}
\label{sssec:gpio-interrupts}

A scan of every input on every frame would waste the bus. The expanders raise an
interrupt instead, and the processor reads only after a control moves. Each
device enables interrupt-on-change on all input pins through GPINTEN. INTCON
stays clear, so each pin compares against its own previous value.

The three devices share one interrupt line. Two configuration bits make this
possible. IOCON.MIRROR joins INTA and INTB inside each device, so one pin
reports both ports. IOCON.ODR makes that pin an open-drain output. The three
pins then join at one node with a single 4.7\,k$\Omega$ pull-up, and any device
can pull the node low without a conflict. One line therefore serves a whole
channel, and the processor uses four lines in total.

The shared line does not name its source, so the service routine scans. It reads
both ports of all three devices, which takes about 370\,$\mu$s at 400\,kHz. It
compares each byte against the stored previous value, and the changed bits
identify the control. The routine then feeds the changed encoder phases to the
state machine.

A read of the port registers also clears the interrupt inside each device. This
step is not optional. A device that nobody reads holds the shared line low and
blocks every later interrupt on that channel. The routine therefore reads all
three devices on every event, and it checks the line again before it exits.

This design costs nothing while the console sits still. A fast turn of one
encoder raises 240 events per second, and each event costs 370\,$\mu$s. The
input traffic therefore reaches about 9\,\% of the bus at its worst. The
allowance in Table~\ref{tab:i2c-budget} of Section~\ref{ssec:cv-dacs} treats this
traffic as continuous, so that budget states an upper bound rather than a normal
load.

\subsubsection*{Knob Position Indication}
\label{sssec:led-rings}
 
These encoders may control different parameters at different times or need to be set to display a different value than before during a state load. To do this, we use knobs with no indicator marking and rotary encoders with no stop point (360 degrees around, forever). A ring of 32 LEDs in small 0201 SMD packages surrounds each knob to display the position Each set set of 32 LEDs covers 270 degrees, which is the standard range of real potentiometers used in audio. One LED therefore covers about
8.7 degrees, and the ring resolves the travel to one part in 32. The ring gives
a coarse reading that the eye takes in at a glance. The channel controller carries
the exact value (and maybe the exact value can be shown on the channel display).

\begin{figure}[H]
    \centering
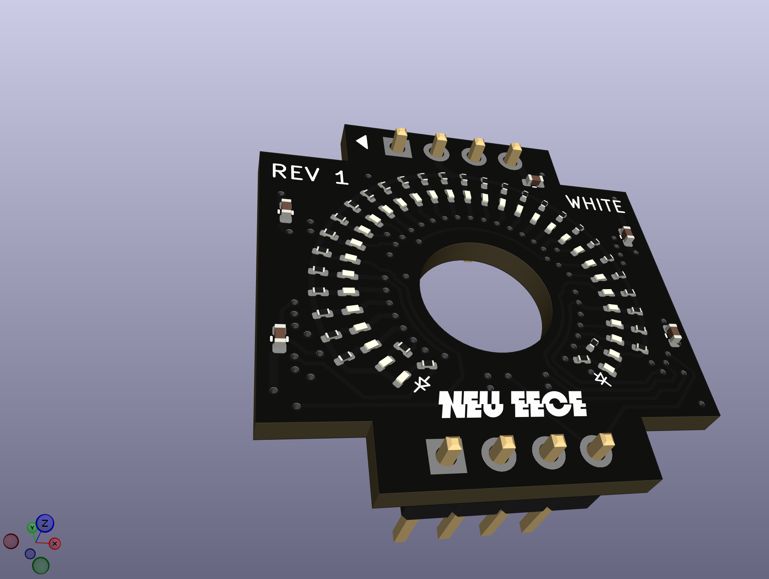
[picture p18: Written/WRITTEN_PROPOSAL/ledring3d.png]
    
    \caption{3D Render of the LED ring, for the small 6mm shaft EC11 encoders, with a 7.5mm diameter hole for that shaft.}
    \label{fig:ledring-3d}
\end{figure}

\begin{figure}[H]
    \centering
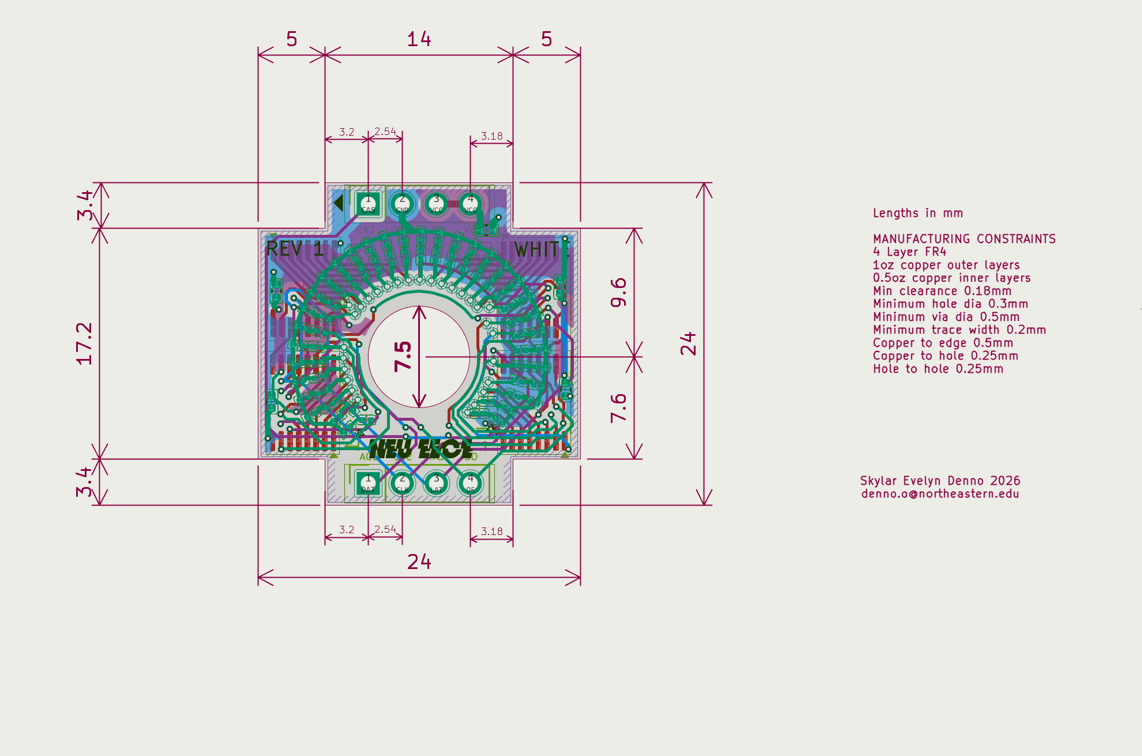
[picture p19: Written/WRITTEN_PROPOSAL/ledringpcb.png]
    
    \caption{PCB layout. Inner layers are ground plane and VCC=5V plane. The width of these boards is only 24mm!}
    \label{fig:ledring-pcb}
\end{figure}

\begin{figure}[H]
    \centering
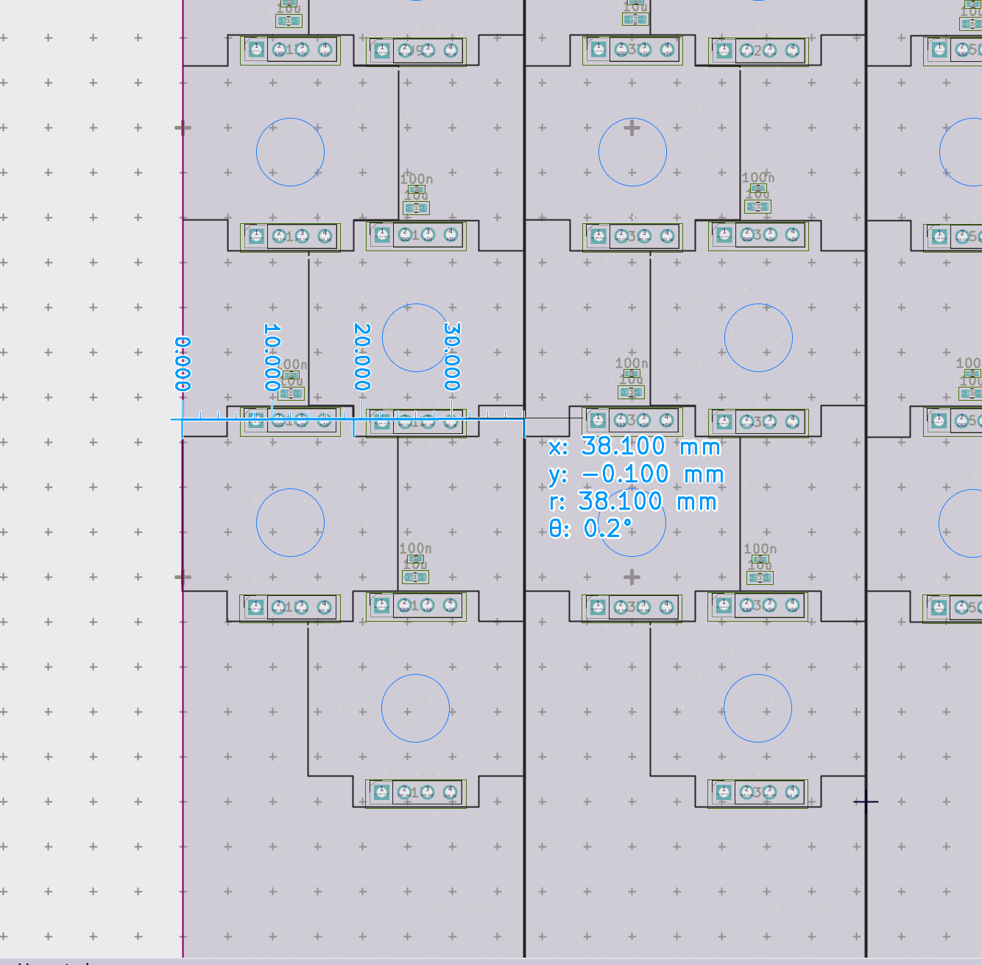
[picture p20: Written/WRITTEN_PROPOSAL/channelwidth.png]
    
    \caption{Aiming for a standard channel strip width of 1.5 inches (38mm), we may stagger the LED boards like this to fit knobs in two columns.}
    \label{fig:ledring-stagger}
\end{figure}
 
Four 74HCT595 shift registers~\cite{hct595} drive the 32 LEDs of one ring. They sit on a small
dedicated board behind the front panel, with the encoder through the middle. Each
board carries a connector for power, ground, data/clock in, latch, output enable, and data out (to cascade the bitstream to the next knob's shift registers). There are 10 knobs per channel, so forty knobs serve four channels, so 160 shift registers sit in the chain.
Eight further devices on the main board drive the 64 button lamps of the four channels controlled by the bucket's controller. The chain therefore holds 168 devices and 1344 bits.
 
The choice of the HCT family is due to the following reason. The processor drives 3.3\,V
logic, and these devices run from the 5\,V LED rail. An HCT input switches at
2.0\,V, so it comfortably accepts a 3.3\,V logic signal as high, while running at 5V\,~\cite{hct595}. The regular "HC" variant running at 5V sees logic high only beyond,
3.5\,V, which would not work with 3.3V logic.
 
 \begin{figure}[H]
    \centering
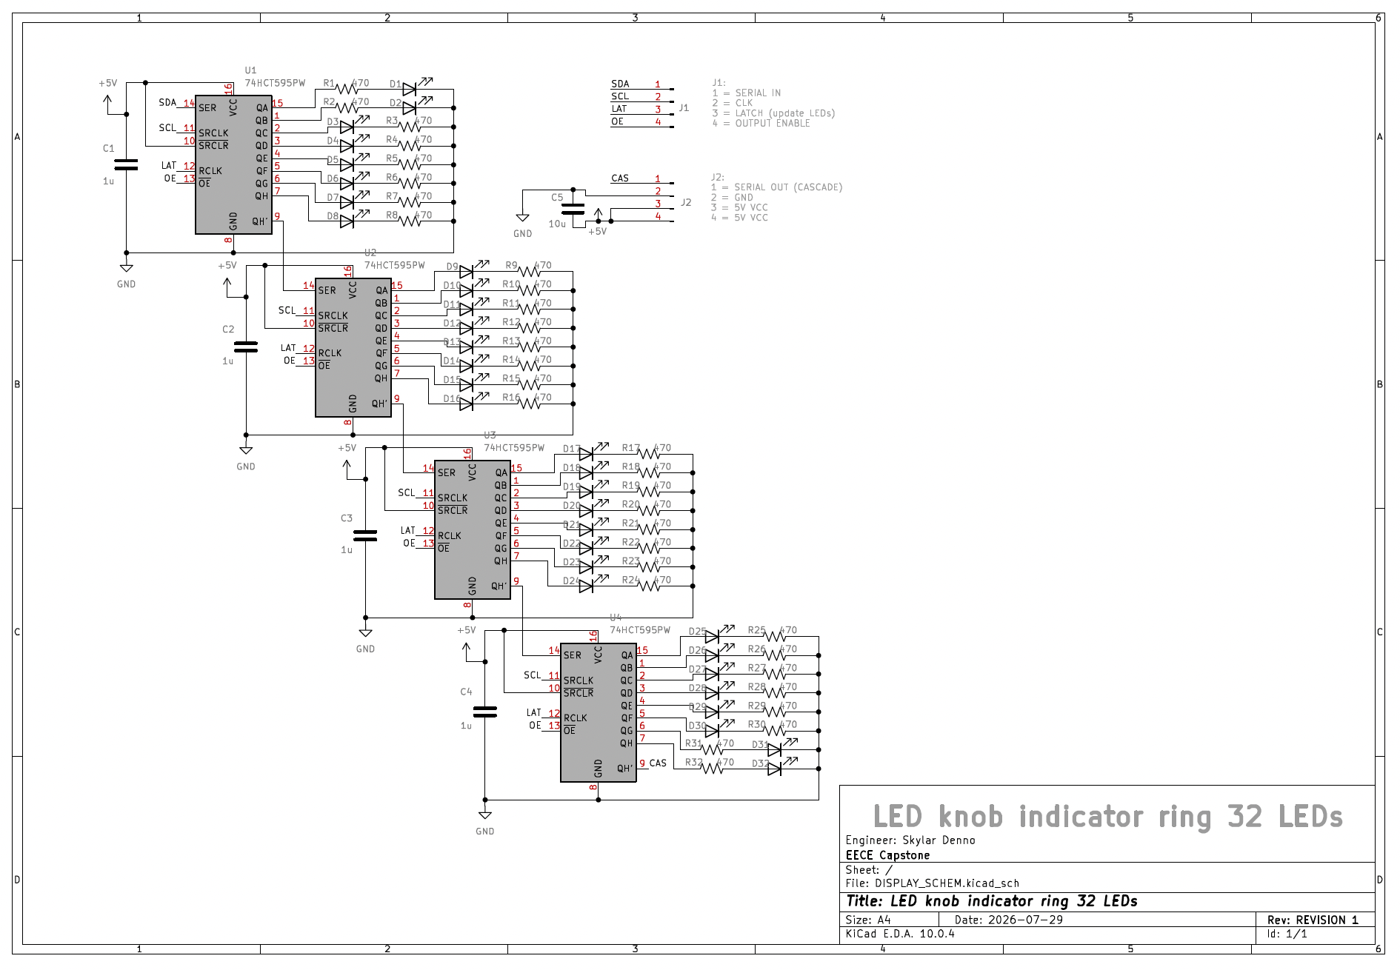
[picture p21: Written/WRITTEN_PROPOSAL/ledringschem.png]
    
    \caption{Schematic for the LED ring breakout boards, showing four 74HCT595 LED driver shift registers (32 total LEDs). Common cathode configuration.}
    \label{fig:ledring-schematic}
\end{figure}

The shift clock runs at 480\,kHz, and a full frame of updating all LEDs therefore takes 2.8\,ms. This
rate is safely far below the maximum speeds the devices can handle. This is because the
chain crosses the whole control surface and passes every channel strip. A slow
clock with slow edges radiates far less into the analog path than a fast one.
The outputs hold their state between frames, so a slow clock costs no
brightness. It costs only 2.8\,ms of delay before a movement appears, which is not noticeable to the human eye.
 
A dedicated 5\,V rail feeds the LEDs. At 1.5\,mA per LED, a fully lit surface
draws about 2.0\,A, so the rail carries the load and the 3.3\,V logic supply does
not. A PWM signal on the output enable line sets the brightness of the whole
chain. That signal runs above 20\,kHz. A slower PWM would place a large
switching current inside the audio band, next to the analog circuits.

\subsection{Control Voltage DACs}
\label{ssec:cv-dacs}

Each console channel needs many control voltages at once. These are the VCA control
ports and the equalizer corner frequencies. An STM32G474~\cite{stm32g474} supplies these levels
through four independent I\textsuperscript{2}C buses. Each bus carries one
console channel, so one processor serves four channels.

Each bus holds eight devices. Three MCP23017 expanders provide the switch and
lamp lines described above. Five MCP4728 converters~\cite{mcp4728} provide the control
voltages. The MCP4728 holds four 12-bit outputs, so each bus produces 20
control voltages. One processor therefore produces 80 control voltages in
total.

Every MCP4728 leaves the factory with the same default address, so the five
devices on a bus need distinct addresses. The address bits live in on-chip
EEPROM. A programming step at the end of manufacture writes them once. This
step needs a precise transition of the LDAC pin against the I\textsuperscript{2}C
clock~\cite{mcp4728}, so the test fixture performs it at a reduced clock rate. The LDAC pin
serves a second purpose during normal use. The processor writes all five
devices and then pulses LDAC, and all 20 outputs of a channel move together.

\subsubsection*{Bus Bandwidth}
\label{sssec:bus-bandwidth}

The bus runs in Fast mode at 400\,kHz~\cite{i2cspec}. One bit period is therefore
2.5\,$\mu$s, and one byte takes 22.5\,$\mu$s because each byte carries an
acknowledge bit. Two transactions repeat every frame. The Fast Write command of
the MCP4728 loads all four channels in nine bytes. A two-register read of the
MCP23017 returns both ports in five bytes. Table~\ref{tab:i2c-budget} gives the
budget.

\begin{table}[t]
\centering
\caption{Bus load for one channel at a 400\,Hz frame rate. Each figure includes
an allowance for the start, stop, and bus free periods.}
\label{tab:i2c-budget}
\begin{tabular}{l r r r}
\toprule
\textbf{Transaction} & \textbf{Bytes} & \textbf{Time} & \textbf{Total} \\
\midrule
MCP4728 fast write, 5 devices & 9 & 210\,$\mu$s & 1050\,$\mu$s \\
MCP23017 port read, 3 devices & 5 & 123\,$\mu$s & 369\,$\mu$s \\
\midrule
Traffic per frame & & & 1419\,$\mu$s \\
Frame period at 400\,Hz & & & 2500\,$\mu$s \\
Bus load & & & 57\,\% \\
\bottomrule
\end{tabular}
\end{table}

The bus therefore carries the full update in 1.42\,ms of a 2.5\,ms frame. The
remaining 1.08\,ms absorbs the lamp writes, the retries, and the occasional
configuration write. A saturated bus would sustain about 700 frames per second,
so the 400\,Hz rate keeps a margin of nearly two to one. The bus stays at
400\,kHz even though the MCP4728 accepts 3.4\,MHz, because the MCP23017 shares
the same wires and stops at 1.7\,MHz. The measured rate already meets the need,
and a slower clock produces slower edges and less radiated noise.

A frame rate of 400\,Hz sets a Nyquist limit of 200\,Hz. No control voltage can
carry a component above that frequency. This limit costs nothing, because no
parameter in the channel needs to move that fast.

\subsubsection*{Reference, Span, and Output Stage}
\label{sssec:cv-output}

Each MCP4728 takes its reference from VDDA. This is a dedicated 3.3\,V linear
supply that feeds the converters and nothing else. A ferrite bead and local
decoupling isolate every device on the rail. The converter output is therefore
ratiometric to VDDA, and this suits the design. The analog-to-digital converters share the
same rail, so a measured fader position and the control voltage derived from it
scale together.

The internal 2.048\,V reference of the MCP4728 offers no advantage at this
supply voltage. It gives a full scale of only 2.048\,V at unity gain, and the
gain of two would ask for 4.096\,V from a 3.3\,V rail. A reference of VDDA
therefore gives the widest span available. A full scale of 3.3\,V across 12 bits
gives a step of 0.81\,mV at the converter output.

A TL074 stage~\cite{tl074} follows each output. The stage applies a gain and an offset, and
a reference voltage at the second input sets that offset. Two resistors per
channel therefore fix the span. The widest span reaches about $\pm 13$\,V,
because the TL074 does not swing to its rails. A design that needs a true
$\pm 15$\,V output must run the stage from $\pm 18$\,V rails.

The span is not the same for every destination, and this matters. Twelve bits
spread across the full 26\,V output range give a step of 6.3\,mV, or 0.19\,dB at
a VCA control port. That step is too coarse for a fader. Destinations that need
fine resolution therefore receive a narrow span. A VCA control port spans
$-0.66$\,V to $+3.3$\,V, which needs a stage gain of 1.2. One step at that port
moves the control voltage by 0.97\,mV, or 0.03\,dB. Bipolar destinations such as a pan
control or a filter offset use the wide span, where a coarse step does no harm.

The TL074 adds an input offset voltage of a few millivolts, and the stage gain
multiplies it. On a narrow span this offset produces a fixed gain error of a
few tenths of a decibel. 
\subsubsection*{Reconstruction and Slew}
\label{sssec:cv-filter}
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

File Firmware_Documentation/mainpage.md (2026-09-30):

# Firmware Developer Documentation

Browse the <a href="files.html">full file list</a>, or here is some of the most useful documentation:

Bucket Controller

- [CONFIG.h](@ref CONFIG.h) - Main configuration file
- [mcp23017.h](@ref mcp23017.h) - Functions to interface with MCP23017 GPIO expander
- [mcp4728.c](@ref mcp4728.c) - Functions to interface with MCP4728 quad DAC
- [i2c_driver.h](@ref i2c_driver.h) - I2C functions
- [led_driver.h](@ref led_driver.h) - Functions to control LED and knob ring displays
- [rotary_encoder.h](@ref rotary_encoder.h) - Functions to find the status and motion of the EC11 rotary encoders
- [control_voltage.h](@ref control_voltage.h) - Control voltage generation engine header
- [console_state_bucket.h](@ref console_state_bucket.h) - Header file for console parameter data saving and reporting code (for the bucket controller)
- LCD DISPLAY DRIVER (need)
- [main.c](@ref Firmware/BucketController/Core/Src/main.c) - Main C file
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

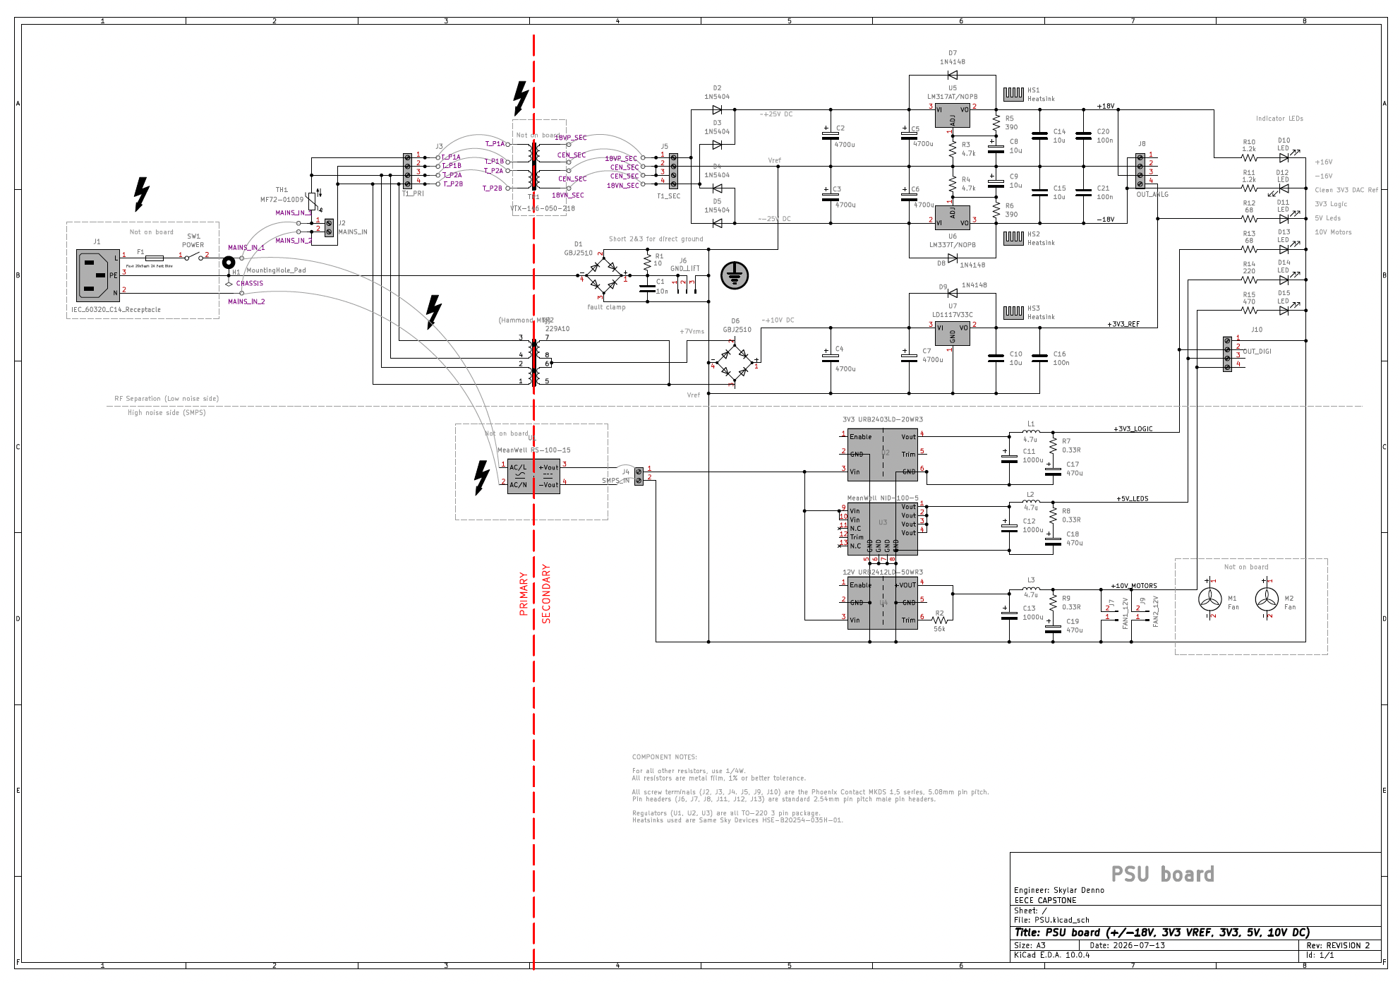
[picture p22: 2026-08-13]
Written/WRITTEN_PROPOSAL/psuschem.png

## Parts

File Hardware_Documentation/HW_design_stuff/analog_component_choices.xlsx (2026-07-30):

Purpose | Part Num | MFR | Desc | Unit cost | Estimated qty | Cost x qty | Source | Datasheet
Audio opamp | NE5532 | TI | general high speed low noise low distortion op amp for audio very popular dual per chip | $0.55 | 100 | $55.00
OTA (control params - voltace ctrl resistor) | LM13700M/NOPB | TI | operational transconductance amplifier | $0.63 | 160 | $100.80 | LCSC
Hifi audio op amp | OPA2134 | TI | extremely high speed low noise low distortion op amp for important things like | $3.97 | 8 | $31.76
VCA (digitally controlled SPI) | PGA2311 | TI | vca digitally controlled! So we don’t need CV and all that for these yay straight onto spi |  |  | $0.00
CV amplifier (0-3v3 to -14-+14) | TL074 | TI | crappy op amp but its CV sigs its basically DC (low offset is important) quad | $0.48 |  | $0.00
Line input buffer | INA2137 | TI | basically an op amp | $2.01 | 16 | $32.16
Signal switch | ADG1404 | Analog Devices | if you enable a send or an insert point, it changes where signal is sent - switch |  |  | $0.00
 |  |  |  |  |  | $0.00
 |  |  |  |  |  | $0.00
 |  |  |  |  |  | $0.00
 |  |  |  |  |  | $0.00
 |  |  |  |  |  | $0.00
 |  |  |  |  |  | $0.00
 |  |  |  |  |  | $0.00
 |  |  |  |  |  | $0.00
 |  |  |  |  |  | $0.00
 |  |  |  |  |  | $0.00
 |  |  |  |  |  | $0.00
 |  |  |  |  |  | $0.00
 |  |  |  |  |  | $0.00
 |  |  |  |  |  | $0.00
 |  |  |  |  |  | $0.00
 |  |  |  |  |  | $0.00
 |  |  |  |  |  | $0.00
 |  |  |  |  |  | $0.00
 |  |  |  |  |  | $0.00
 |  |  |  |  |  | $0.00
 |  |  |  |  |  | $0.00
 |  |  |  |  |  | $0.00
 |  |  |  |  |  | $0.00
 |  |  |  |  |  | $0.00
 |  |  |  |  |  | $0.00
 |  |  |  |  |  | $0.00
 |  |  |  |  |  | $0.00
 |  |  |  |  |  | $0.00
 |  |  |  |  |  | $0.00
 |  |  |  |  |  | $0.00
 |  |  |  |  |  | $0.00
 |  |  |  |  |  | $0.00

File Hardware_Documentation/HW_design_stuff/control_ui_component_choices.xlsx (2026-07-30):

Purpose | Part Num | MFR | Desc | Unit cost | Estimated qty | Cost x qty | Source | Datasheet
motorized fader | RSA0N11M9 | ALPS | motorized fader 100mm linear resistance taper (10v motor) with touch sens | $20.00 | 0 | $0.00 | (Skylar has enough already)
Rotary Encoder + push knob | EC11 | generic |  | $1.00 |  | $0.00 | skylar has 40 already
Button with LED | TSL06322 | tbd |  | $0.10 | 0 | $0.00 | (Skylar has many)
LED knob rings |  | Us/Custom (JLCPCB) |  | $3.37 | 44 | $148.28 | JLCPCB
Screens | 4421 | Adafruit | RGB TFT display 1.5 inch, with 22 pin (0.3mm pitch) flat flex cable (SPI protocol) | $10.95 | 8 | $87.60 | (Skylar has 8 already) | https://cdn-shop.adafruit.com/product-files/4421/4421_specs.pdf
Cable connector for screen | 05A20L22P | HanElectricity |  | $0.07 | 16 | $1.12 | JLCPCB turnkey | https://jlc-prod-smt.oss-eu-central-1.aliyuncs.com/smtDataManualFile/8603351085302235136-C22435644.pdf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
knob caps | Sifam DR110 006 + C110 OR Rogan P-K281S-X | tbd | the plastic thing u touch that goes over the shaft of the EC11 |  | 44 | $0.00
fader caps | I have |  | the cap that goes on top of the little fin in the fader that you slide |  | 0 | $0.00 | (Skylar has enough)
touch sensor | TTP223-BA6 | generic | capacitive touch sensor for faders | $0.11 | 16 | $1.76 | JLCPCB turnkey | https://files.seeedstudio.com/wiki/Grove-Touch_Sensor/res/TTP223.pdf
motor driver | DRV8833 | TI | pwm H bridge motor driver dual | $1.37 | 8 | $10.96 | JLCPCB turnkey
LED knob rings | 74HCT595 | TI | 8 out shift register drive LEDsknob ones already included but additional leds (button leds) | $0.20 | 32 | $6.40 | JLCPCB turnkey
VU meter | LM3916 | TI | displays the audio level on a few leds (look up LED VU meter) | $1.00 | 16 | $16.00
VU meter leds |  |  |  |  |  | $0.00
 |  |  |  |  |  | $0.00
 |  |  |  |  |  | $0.00
 |  |  |  |  |  | $0.00
 |  |  |  |  |  | $0.00
 |  |  |  |  |  | $0.00
 |  |  |  |  |  | $0.00
 |  |  |  |  |  | $0.00
 |  |  |  |  |  | $0.00
 |  |  |  |  |  | $0.00
 |  |  |  |  |  | $0.00
 |  |  |  |  |  | $0.00
 |  |  |  |  |  | $0.00
 |  |  |  |  |  | $0.00
 |  |  |  |  |  | $0.00
 |  |  |  |  |  | $0.00
 |  |  |  |  |  | $0.00
 |  |  |  |  |  | $0.00
 |  |  |  |  |  | $0.00
 |  |  |  |  |  | $0.00
 |  |  |  |  |  | $0.00
 |  |  |  |  |  | $0.00
 |  |  |  |  |  | $0.00
 |  |  |  |  |  | $0.00
 |  |  |  |  |  | $0.00
 |  |  |  |  |  | $0.00
 |  |  |  |  |  | $0.00

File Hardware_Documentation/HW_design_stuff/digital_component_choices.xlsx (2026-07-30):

Purpose | Part Num | MFR | Desc | Unit cost | Estimated qty | Cost x qty | Source | Datasheet
Controller | STM32G474(XXX6) | STMicroelectronics | Controls everything - 1 per 4 channels and 1 for master section | $11.00 | 5 | $55.00 | JLCPCB turnkey part stock | https://www.st.com/resource/en/datasheet/stm32g474cb.pdf
I2C GPIO Expander | MCP23017 | Microchip Tech | allows controller to read lots of rotary encoder/button positions with few GPIO pins | $1.71 | 40 | $68.40 | JLCPCB turnkey part stock | https://jlc-prod-smt.oss-eu-central-1.aliyuncs.com/smtDataManualFile/8590170333329731584-C558584.pdf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
CV DAC | MCP4728 | Microchip Tech | generate the control voltages 0-3v3 (12bit = 2^12 possible voltages) quad | $2.04 | 85 | $173.40 | JLCPCB turnkey part stock | https://www.ti.com/cn/lit/gpn/sn74lvc245a
Logic level shifter | SN74LVC245 | TI | controller runs 3v3 logic, but some devies need 5 volt logic | $0.31 | 16 | $4.96 | JLCPCB turnkey part stock | https://ww1.microchip.com/downloads/aemDocuments/documents/OTH/ProductDocuments/DataSheets/22187E.pdf
 |  |  |  |  |  | $0.00
 |  |  |  |  |  | $0.00
 |  |  |  |  |  | $0.00
 |  |  |  |  |  | $0.00
 |  |  |  |  |  | $0.00
 |  |  |  |  |  | $0.00
 |  |  |  |  |  | $0.00
 |  |  |  |  |  | $0.00
 |  |  |  |  |  | $0.00
 |  |  |  |  |  | $0.00
 |  |  |  |  |  | $0.00
 |  |  |  |  |  | $0.00
 |  |  |  |  |  | $0.00
 |  |  |  |  |  | $0.00
 |  |  |  |  |  | $0.00
 |  |  |  |  |  | $0.00
 |  |  |  |  |  | $0.00
 |  |  |  |  |  | $0.00
 |  |  |  |  |  | $0.00
 |  |  |  |  |  | $0.00
 |  |  |  |  |  | $0.00
 |  |  |  |  |  | $0.00
 |  |  |  |  |  | $0.00
 |  |  |  |  |  | $0.00
 |  |  |  |  |  | $0.00
 |  |  |  |  |  | $0.00
 |  |  |  |  |  | $0.00
 |  |  |  |  |  | $0.00
 |  |  |  |  |  | $0.00
 |  |  |  |  |  | $0.00
 |  |  |  |  |  | $0.00
 |  |  |  |  |  | $0.00
 |  |  |  |  |  | $0.00
 |  |  |  |  |  | $0.00
 |  |  |  |  |  | $0.00

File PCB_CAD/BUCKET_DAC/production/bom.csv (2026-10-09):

Designator | Footprint | Quantity | Value | LCSC Part #
C1, C103, C11, C16, C21, C26, C27, C28, C29, C46, C51, C52, C53, C54, C6, C71, C76, C77, C78, C79, C96 | 0402 | 21 | 100n | C1525
C10, C100, C12, C13, C14, C15, C17, C18, C19, C2, C20, C22, C23, C24, C25, C3, C30, C31, C32, C33, C34, C35, C36, C37, C38, C39, C4, C40, C41, C42, C43, C44, C45, C47, C48, C49, C5, C50, C55, C56, C57, C58, C59, C60, C61, C62, C63, C64, C65, C66, C67, C68, C69, C7, C70, C72, C73, C74, C75, C8, C80, C81, C82, C83, C84, C85, C86, C87, C88, C89, C9, C90, C91, C92, C93, C94, C95, C97, C98, C99 | 0402 | 80 | 10n | C1524
C101 | CP_Elec_5x5.4 | 1 | 22u | C23289
C102 | 0603 | 1 | 1u | C1592
FB1 | Ferrite_1206_3216Metric | 1 | Ferrite_Bead | C16902
J1 | PinHeader_2x10_P1.27mm_Vertical | 1 | Channel_0_CV_Out1
J10 | PinHeader_1x04_P2.54mm_Vertical | 1 | I2C2
J11 | PinHeader_1x04_P2.54mm_Vertical | 1 | I2C3
J12 | PinHeader_1x04_P2.54mm_Vertical | 1 | I2C4
J13 | PinHeader_1x04_P2.54mm_Vertical | 1 | POWER_IN
J14 | PinHeader_1x08_P2.54mm_Vertical | 1 | LDAC
J2 | PinHeader_2x10_P1.27mm_Vertical | 1 | Channel_0_CV_Out2
J3 | PinHeader_2x10_P1.27mm_Vertical | 1 | Channel_1_CV_Out1
J4 | PinHeader_2x10_P1.27mm_Vertical | 1 | Channel_1_CV_Out2
J5 | PinHeader_2x10_P1.27mm_Vertical | 1 | Channel_2_CV_Out1
J6 | PinHeader_2x10_P1.27mm_Vertical | 1 | Channel_2_CV_Out2
J7 | PinHeader_2x10_P1.27mm_Vertical | 1 | Channel_3_CV_Out1
J8 | PinHeader_2x10_P1.27mm_Vertical | 1 | Channel_3_CV_Out2
J9 | PinHeader_1x04_P2.54mm_Vertical | 1 | I2C1
R1, R10, R11, R12, R13, R14, R15, R16, R17, R18, R19, R2, R20, R21, R22, R23, R24, R25, R26, R27, R28, R29, R3, R30, R31, R32, R33, R34, R35, R36, R37, R38, R39, R4, R40, R41, R42, R43, R44, R45, R46, R47, R48, R49, R5, R50, R51, R52, R53, R54, R55, R56, R57, R58, R59, R6, R60, R61, R62, R63, R64, R65, R66, R67, R68, R69, R7, R70, R71, R72, R73, R74, R75, R76, R77, R78, R79, R8, R80, R9 | 0402 | 80 | 470 | C25117
R81, R82, R83, R84, R85 | R_Axial_DIN0207_L6.3mm_D2.5mm_P2.54mm_Vertical | 5 | 4.7k | dnp
U1, U10, U11, U12, U13, U14, U15, U16, U17, U18, U19, U2, U20, U3, U4, U5, U6, U7, U8, U9 | MSOP-10_3x3mm_P0.5mm | 20 | MCP4728 | C108207

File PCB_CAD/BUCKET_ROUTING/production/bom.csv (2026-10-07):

Designator | Footprint | Quantity | Value | LCSC Part #
J1, J11, J16, J6 | PinHeader_1x03_P2.54mm_Vertical | 4 | POWER | DNP
J10, J15, J20, J5 | PinHeader_1x08_P2.54mm_Vertical | 4 | MIX_BUS | DNP
J12, J17, J2, J7 | PinHeader_1x05_P2.54mm_Vertical | 4 | CV | DNP
J13, J18, J3, J8 | PinHeader_1x03_P2.54mm_Vertical | 4 | AUD_IN | DNP
J14, J19, J4, J9 | PinHeader_1x03_P2.54mm_Vertical | 4 | INSERT | DNP

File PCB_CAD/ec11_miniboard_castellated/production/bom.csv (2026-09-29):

Designator | Footprint | Quantity | Value | LCSC Part #
J1, J2, J3, J4 | castellated_single | 4 | Conn_01x01
SW1 | EC11J0924411 | 1 | EC11_Rotary_Encoder

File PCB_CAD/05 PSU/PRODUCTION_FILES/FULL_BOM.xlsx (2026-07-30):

Reference | Footprint | Quantity | Value | Description | MFG | PART | PRICE PER | TOTAL
C1, C11, C12, C2, C3, C4 | CP_Radial_D18.0mm_P7.50mm | 6 | 4700u | filter | POPULATED AT FAB, SEE JLCbom.csv |  | $77.6 PER ASSEMBLY COUNTING PCB FAB AND TURNKEY ASSEMBLY + Shipping/customs
C10, C14, C9 | 1206 | 3 | 100n | filter (hf bypass)
C13, C7, C8 | C_Rect_L24.0mm_W12.6mm_P22.50mm_MKT | 3 | 10u | filter
C15 | 1206 | 1 | 10n | ground lift
C16, C18, C20, C22 | CP_Radial_D12.5mm_P5.00mm | 4 | 1000u | pi filter
C17, C19, C21, C23 | CP_Radial_D10.0mm_P5.00mm | 4 | 470u | pi filter
C5, C6 | CP_Elec_6.3x5.4 | 2 | 10u | hf bypass reg adj pin
D1, D2, D3, D4 | D_DO-201AD_P15.24mm_Horizontal | 4 | 1N5404 | bridge rectifier
D5, D6 | Diode_Bridge_32.0x5.6x17.0mm_P10.0mm_P7.5mm | 2 | GBJ2510 | bridge rectifier
D7, D8, D9 | D_SOD-123 | 3 | 1N4148 | prevent post regulator caps from d/c thru it - power off
L1, L2, L3, L4 | L_Vishay_IHLP-5050 | 4 | 4.7u | pi filter
R1, R2, R3 | R_Axial_DIN0414_L11.9mm_D4.5mm_P20.32mm_Horizontal | 3 | 220 | 2W res discharge caps
R10, R9 | 1206 | 2 | 1.2k | indicator led current limit 16v
R11, R12 | 1206 | 2 | 68 | indicator led current limit 3v3
R13 | 1206 | 1 | 220 | indicator led current limit 5v
R14 | 1206 | 1 | 470 | indicator led current limit 10v
R15 | 1206 | 1 | 56k | 12v buck module trim pin (calc from datasht)
R16, R17, R18, R19 | R_Axial_DIN0207_L6.3mm_D2.5mm_P10.16mm_Horizontal | 4 | 0.33R | to dampen pi filter resonance in case L ESR too low
R4 | 0805 | 1 | 10 | ground lift
R5, R6 | 1206 | 2 | 4.7k | regulator voltage set
R7, R8 | 1206 | 2 | 390 | regulator voltage set
U1 | TO-220-3_Vertical | 1 | LM317AT/NOPB | pos rail regulator
U2 | TO-220-3_Vertical | 1 | LM337T/NOPB | neg rail regulator
U3 | TO-220-3_Vertical | 1 | LD1117V33C | low dropout regulator for 3v3 reference
J10 | TerminalBlock_Phoenix_MKDS-1,5-2-5.08_1x02_P5.08mm_Horizontal | 1 | SMPS_IN | terminal |  |  | 0.45 | 0.45
J11 | PinHeader_1x02_P2.54mm_Vertical | 1 | D/C_CAP3 | to d/c big cap with screwdriver no sparky sparky | generic |  | 0 | 0
J12 | PinHeader_1x02_P2.54mm_Vertical | 1 | D/C_CAP2 | to d/c big cap with screwdriver no sparky sparky | generic |  | 0 | 0
J13 | PinHeader_1x02_P2.54mm_Vertical | 1 | D/C_CAP1 | to d/c big cap with screwdriver no sparky sparky | generic |  | 0 | 0
J2 | TerminalBlock_Phoenix_MKDS-1,5-4-5.08_1x04_P5.08mm_Horizontal | 1 | OUT_ANLG | terminal |  |  | 2.22 | 2.22
J3 | TerminalBlock_Phoenix_MKDS-1,5-2-5.08_1x02_P5.08mm_Horizontal | 1 | MAINS_IN | terminal |  |  | 0.45 | 0.45
J4 | TerminalBlock_Phoenix_MKDS-1,5-4-5.08_1x04_P5.08mm_Horizontal | 1 | T1_PRI | terminal |  |  | 2.22 | 2.22
J5 | TerminalBlock_Phoenix_MKDS-1,5-4-5.08_1x04_P5.08mm_Horizontal | 1 | T1_SEC | terminal |  |  | 2.22 | 2.22
J6 | PinHeader_1x03_P2.54mm_Vertical | 1 | GND_LIFT | use 2 pin shorting jumper to select gnd lift or no | generic |  | 0 | 0
J7 | PinHeader_1x02_P2.54mm_Vertical | 1 | FAN1_12V | cooling fan | generic |  | 0 | 0
J8 | PinHeader_1x02_P2.54mm_Vertical | 1 | FAN2_12V | cooling fan | generic |  | 0 | 0
J9 | TerminalBlock_Phoenix_MKDS-1,5-4-5.08_1x04_P5.08mm_Horizontal | 1 | OUT_DIGI | terminal |  |  | 2.22 | 2.22
TR1 | VTX-146-050-218 | 1 |  | 50va dual primary dual secondary 18v 18v toroidal | Vigortronix | VTX-146-050-218 | 29.81 | 29.81
TR2 | 229A10 | 1 | 229A10 | pcb toroidal mains transformer for 3v3 ref | Hammond Mfg | 229A10 | 14.77 | 14.77
TH1 | 7.5mm pitch | 1 |  | negative temp coeff. Thermistor (inrush current prot) | Cantherm | MF72-010D9 | 0.51 | 0.51
U4 | in chassis | 1 |  | smps AC to DC full noisy side supply input (105w 15v) | MeanWell | RS-100-15 | 16.19 | 16.19
U5 | see datasheet | 1 |  | dc-dc buck for 3v3 rail (20w cts) | Mornsun/generic | URB2403LD-20WR3 | 6.5 | 6.5
U6 | see datasheet | 1 |  | dc-dc buck for 5v rail (100w short time 5V) | MeanWell | NID-100-5 | 10.38 | 10.38
U7 | see datasheet | 1 |  | dc-dc buck for 10v rail (50w cts probably overkill) | Mornsun/generic | URB2412LD-50WR3 | 13.85 | 13.85
D10, D11, D12, D13, D14, D15 | LED_Rectangular_W3.9mm_H1.8mm | 6 |  | indicator LED for voltage present on each rail | Kingbright | WP113GDT |  | 0
HS1, HS2, HS3 | see datasheet | 3 |  | regulator heatsink for to220, solder, bolt on | Same Sky Devices | HSE-B20254-035H-01 |  | 0
J1+SW1 | in chassis | 1 |  | IEC 320 C14 inlet with fuse holder and switch | Antrader | AC250V | 3.33 | 3.33
F1 | in chassis | 1 |  | 2A fast blow fuse 20mm x 5mm | generic |  | 0.2 | 0.2
M1, M2 | in chassis | 2 |  | 40mm dia, 10mm 12v DC cooling fan brushless, 5k RPM | generic |  | 1.8 | 3.6
Output | in chassis | 2 |  | female XLR4 jack | Neutrik | NC4FD-L-1 | 10 | 20
Chassis |  | 1 |  | 1u rack mount chassis | Redco Audio | CH1 Chassis | 50 | 50
Panel Chassis custom CNC |  | 1 |  | 1mm 5052 aluminium | SendCutSend |  | 30 | 30
Transformer holder | in chassis | 1 |  | holds tr1 is made of pcb | from jlc |  | 1.6 | 1.6
 |  |  |  |  |  |  | TOTAL | 288.12

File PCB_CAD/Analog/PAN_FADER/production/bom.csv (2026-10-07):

Designator | Footprint | Quantity | Value | LCSC Part #
C1, C12, C13, C16, C18, C19, C2, C20, C21, C22, C3, C4, C5, C6, C7, C8 | 0603 | 16 | 100n | C1591
C100, C101, C3L1, C3R1 | 0805 | 4 | 2.2n | C107103
C11, C17, C4L1, C4R1, C6L1, C6R1, C7L1, C7R1 | CP_Elec_6.3x5.4_Nichicon | 8 | 10u | C340735
C1L1, C1R1, C2L1, C2R1 | C_Rect_L7.2mm_W2.5mm_P5.00mm | 4 | 22n | DNP
C23, C24 | 1206 | 2 | 10u | C9807
C5L1, C5R1 | 0603 | 2 | 22p | C105620
J1 | PinHeader_1x02_P2.54mm_Vertical | 1 | COMP_CV | DNP
J2 | PinHeader_1x05_P2.54mm_Vertical | 1 | CV_FROM_DAC | DNP
J3 | PinHeader_1x03_P2.54mm_Vertical | 1 | POWER | DNP
J4 | PinHeader_1x08_P2.54mm_Vertical | 1 | AUD_OUT | DNP
J5 | PinHeader_1x03_P2.54mm_Vertical | 1 | TO_INSERT_MATRIX | DNP
J6 | PinHeader_1x03_P2.54mm_Vertical | 1 | AUD_IN | DNP
R1, R14L1, R14R1, R15L1, R15R1, R2, R4, R5 | 0603 | 8 | 10k | C95204
R100, R101, R6L1, R6R1 | 0603 | 4 | 100 | C22775
R102, R103, R1L1, R1R1 | 0402 | 4 | 120k | C517522
R104, R105, R10L1, R10R1, R11L1, R11R1 | 0402 | 6 | 2.2k | C326602
R12L1, R12R1, R13L1, R13R1 | 0402 | 4 | 4.7k | C281778
R2L1, R2R1, R3L1, R3R1 | 0603 | 4 | 24k | C319717
R3 | 0402 | 1 | 56.2k | C705626
R4L1, R4R1 | 0603 | 2 | 38.3k | C861362
R5L1, R5R1 | 0805 | 2 | 698k | C865618
R7L1, R7R1 | 0603 | 2 | 5.1k | C122969
R8L1, R8R1, R9L1, R9R1 | 0603 | 4 | 20k | C154077
TH1L1, TH1R1 | R_Axial_DIN0207_L6.3mm_D2.5mm_P2.54mm_Vertical | 2 | ** | DNP
U1, U5 | SIP-8_19x3mm_P2.54mm | 2 | THAT2180A | DNP
U2 | SOIC-14_3.9x8.65mm_Pitch1.27mm | 1 | OPA1679 | C2878631
U3, U7 | Texas_S-PDSO-G8_3x3mm_P0.65mm | 2 | OPA1637 | C2860968
U6 | SOIC-8_3.9x4.9mm_P1.27mm | 1 | OPA2197xD
U8 | SOT-23-3 | 1 | ADR5041 | C659596
U9 | TSSOP-16_4.4x5mm_P0.65mm | 1 | ADG1436 | C408899
VR1, VR2 | Potentiometer_Bourns_3314J_Vertical | 2 | 20k | C55069

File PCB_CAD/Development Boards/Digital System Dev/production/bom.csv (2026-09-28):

Designator | Footprint | Quantity | Value | LCSC Part #
C1, C2 | 0603 | 2 | 20p | C1648
C10, C11, C12, C13, C14, C15, C3, C30, C31, C32, C35, C36, C37, C38, C5, C7, C8, C9 | 0603 | 18 | 100n | C1590
C4, C6 | 0603 | 2 | 1u | C1592
C47, C48, C49, C50, C60, C61 | 1206 | 6 | 10u | C1849
C62, C63, C64 | CP_Elec_6.3x5.8 | 3 | 10u | C48970664
D1, D2, D3 | 0603 | 3 | LED | C12065
FB1 | Ferrite_0603_1608Metric | 1 | FerriteBead | C1002
J1 | FTSH-107-01-L-DV-K-TR | 1 | STLINK | C5307809
J10 | PinSocket_1x05_P2.54mm_Vertical | 1 | 10V | DNP
J17 | TE_2-1734839-2_1x22-1MP_P0.5mm_Horizontal | 1 | DISP0 | C22435644
J18 | TE_2-1734839-2_1x22-1MP_P0.5mm_Horizontal | 1 | DISP1 | C22435644
J19 | TE_2-1734839-2_1x22-1MP_P0.5mm_Horizontal | 1 | DISP2 | C22435644
J2 | PinHeader_3x18_P2.54mm_Vertical_GND | 1 | PINS_LEFT | DNP
J20 | TE_2-1734839-2_1x22-1MP_P0.5mm_Horizontal | 1 | DISP3 | C22435644
J3 | PinSocket_1x05_P2.54mm_Vertical | 1 | 3V3 | DNP
J4 | PinSocket_1x05_P2.54mm_Vertical | 1 | 5V | DNP
J5 | PinSocket_1x05_P2.54mm_Vertical | 1 | GND | DNP
J6 | PinHeader_3x18_P2.54mm_Vertical_GND | 1 | PINS_RIGHT | DNP
J7 | PinHeader_2x06_P2.54mm_Vertical | 1 | DISP | DNP
J9 | BarrelJack_Horizontal | 1 | DC_IN | DNP
Q1 | SOT-23 | 1 | AO3400A | C20917
R1 | 1206 | 1 | 390 | C4491
R10, R11, R12, R13, R14, R7, R8, R9 | 0603 | 8 | 1.5k | C22843
R16, R23 | 0603 | 2 | 680 | C23228
R17, R22, R24, R26 | 0603 | 4 | 3.3k | C22978
R18, R19, R20, R21 | 1206 | 4 | 47 | C17969
R25 | 1206 | 1 | 68 | C294793
SW1 | SW_Push_1P1T_NO_CK_KMR2 | 1 | RESET | C72443
U1 | LQFP-100_14x14mm_P0.5mm | 1 | STM32G474VETx | C2970837
U2 | DFR05xx_DC-DC | 1 | DFR0570 | DNP
U3 | DFR05xx_DC-DC | 1 | DFR0571 | DNP
X1 | Crystal_SMD_HC49-SD | 1 | HSE_24 | C2253

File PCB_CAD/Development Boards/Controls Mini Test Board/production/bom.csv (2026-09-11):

Designator | Footprint | Quantity | Value | LCSC Part #
C101, C102, C103 | 0603 | 3 | 1u | C1592
C104, C105, C106, C107, C108, C109 | 0603 | 6 | 10n | C57112
C110, C117, C123 | 0603 | 3 | 100n | C1590
C50, C51 | 1206 | 2 | 10u | C1849
D101, D102, D103 | D_SOD-323 | 3 | 1N4148 | C2128
J101, J102, J103, J104 | PinSocket_1x04_P2.54mm_Vertical | 4 | Conn_01x04_Socket
J31 | PinHeader_1x14_P2.54mm_Vertical | 1 | CONN
R101, R102, R103 | 0603 | 3 | 47k | C25819
R104, R105, R106 | 0603 | 3 | 15k | C22809
R107, R108, R109 | 0603 | 3 | 330 | C23138
R110, R111, R112, R113, R114, R115 | 0603 | 6 | 10k | C25804
R116, R117, R118, R119, R120, R121 | 0603 | 6 | 1k | C21190
SW101 | CFPB-1CC-4W6 | 1 | B2A
SW102 | CFPB-1CC-4W6 | 1 | B2B
SW103 | CFPB-1CC-4W6 | 1 | B2C
SW104 | EC11J0924411 | 1 | K1A
SW105 | EC11J0924411 | 1 | K1B
U101 | SOIC-16_3.9x9.9mm_P1.27mm | 1 | 74HCT595 | C282339
U102 | SSOP-28_5.3x10.2mm_P0.65mm | 1 | MCP23017x-x-SS | C506653

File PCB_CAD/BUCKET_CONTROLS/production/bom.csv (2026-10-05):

Designator | Footprint | Quantity | Value | LCSC Part #
C1, C10, C101, C102, C103, C104, C105, C106, C107, C108, C109, C11, C110, C111, C112, C113, C114, C115, C116, C117, C118, C119, C12, C120, C121, C122, C123, C124, C125, C126, C127, C128, C129, C13, C130, C14, C15, C16, C17, C18, C19, C2, C20, C201, C202, C203, C204, C205, C206, C207, C208, C209, C21, C210, C211, C212, C213, C214, C215, C216, C217, C218, C219, C22, C220, C221, C222, C223, C224, C225, C226, C227, C228, C229, C23, C230, C24, C25, C26, C27, C28, C29, C3, C30, C301, C302, C303, C304, C305, C306, C307, C308, C309, C310, C311, C312, C313, C314, C315, C316, C317, C318, C319, C320, C321, C322, C323, C324, C325, C326, C327, C328, C329, C330, C4, C5, C6, C7, C8, C9 | 0402 | 120 | 10n | C1524
C131, C132, C133, C134, C135, C136, C137, C138, C139, C140, C231, C232, C233, C234, C235, C236, C237, C238, C239, C240, C31, C32, C33, C331, C332, C333, C334, C335, C336, C337, C338, C339, C34, C340, C35, C36, C37, C38, C39, C40 | 0603 | 40 | 1u | C15849
C43, C45, C51, C52, C91, C92, C93, C94 | 0603 | 8 | 10u | C19702
C44, C46, C48, C50, C55, C56, C57, C58, C59, C60, C61, C62, C63, C64, C65, C66, C67, C68, C69, C70, C71, C72, C73, C74, C75, C76, C77, C78, C79, C80, C81, C82, C83, C84, C85, C86, C87, C88, C89, C90 | 0402 | 40 | 100n | C1525
C53, C54 | 1206 | 2 | 10u | C1849
D1, D101, D105, D106, D107, D11, D111, D112, D113, D114, D115, D116, D12, D13, D14, D15, D16, D201, D205, D206, D207, D211, D212, D213, D214, D215, D216, D301, D305, D306, D307, D311, D312, D313, D314, D315, D316, D5, D6, D7 | D_SOD-323 | 40 | 1N4148 | C2128
D10, D102, D103, D104, D108, D109, D110, D2, D202, D203, D204, D208, D209, D210, D3, D302, D303, D304, D308, D309, D310, D4, D8, D9 | LED_D3.0mm_FlatTop | 24 | LED | dnp
J1, J101, J103, J105, J107, J109, J11, J111, J113, J115, J117, J119, J13, J15, J17, J19, J201, J203, J205, J207, J209, J211, J213, J215, J217, J219, J3, J301, J303, J305, J307, J309, J311, J313, J315, J317, J319, J5, J7, J9 | PinSocket_1x04_P2.54mm_Vertical | 40 | Pow | dnp
J10, J102, J104, J106, J108, J110, J112, J114, J116, J118, J12, J120, J14, J16, J18, J2, J20, J202, J204, J206, J208, J210, J212, J214, J216, J218, J220, J302, J304, J306, J308, J310, J312, J314, J316, J318, J320, J4, J6, J8 | PinSocket_1x04_P2.54mm_Vertical | 40 | Data | dnp
J21 | TE_2-1734839-2_1x22-1MP_P0.5mm_Horizontal | 1 | DISP0 | C22435644
J22 | TE_2-1734839-2_1x22-1MP_P0.5mm_Horizontal | 1 | DISP1 | C22435644
J23 | TE_2-1734839-2_1x22-1MP_P0.5mm_Horizontal | 1 | DISP2 | C22435644
J24 | TE_2-1734839-2_1x22-1MP_P0.5mm_Horizontal | 1 | DISP3 | C22435644
J25 | TE_2-1734839-2_1x22-1MP_P0.5mm_Horizontal | 1 | DISP0A | C22435644
J26 | TE_2-1734839-2_1x22-1MP_P0.5mm_Horizontal | 1 | DISP1A | C22435644
J27 | TE_2-1734839-2_1x22-1MP_P0.5mm_Horizontal | 1 | DISP2A | C22435644
J28 | TE_2-1734839-2_1x22-1MP_P0.5mm_Horizontal | 1 | DISP3A | C22435644
J29, J36 | PinHeader_1x04_P2.54mm_Vertical | 2 | I2C1_CONN
J30, J38 | PinHeader_1x04_P2.54mm_Vertical | 2 | I2C2_CONN
J31, J37 | PinHeader_1x04_P2.54mm_Vertical | 2 | I2C3_CONN
J32, J39 | PinHeader_1x04_P2.54mm_Vertical | 2 | I2C4_CONN
J33 | PinHeader_1x04_P2.54mm_Vertical | 1 | LED_CONN1
J34 | PinHeader_1x04_P2.54mm_Vertical | 1 | LED_CONN2
J35 | PinHeader_1x04_P2.54mm_Vertical | 1 | POWER_CONN
J40, J41, J42, J43 | PinHeader_1x06_P2.54mm_Vertical_SMD_Pin1Left | 4 | FADER_CARD1
R1, R100, R101, R102, R103, R104, R105, R106, R113, R114, R115, R116, R117, R118, R125, R126, R127, R128, R129, R13, R130, R137, R138, R139, R14, R140, R141, R142, R149, R15, R150, R151, R152, R153, R154, R16, R17, R18, R2, R200, R201, R202, R203, R204, R205, R206, R213, R214, R215, R216, R217, R218, R225, R226, R227, R228, R229, R230, R237, R238, R239, R240, R241, R242, R249, R25, R250, R251, R252, R253, R254, R26, R27, R28, R29, R3, R30, R300, R301, R302, R303, R304, R305, R306, R313, R314, R315, R316, R317, R318, R325, R326, R327, R328, R329, R330, R337, R338, R339, R340, R341, R342, R349, R350, R351, R352, R353, R354, R37, R38, R39, R4, R40, R400, R401, R402, R403, R404, R405, R406, R407, R408, R409, R41, R410, R411, R412, R413, R414, R415, R416, R42, R49, R5, R50, R51, R52, R53, R54, R6 | 0603 | 140 | 10k | C25804
R10, R107, R108, R109, R11, R110, R111, R112, R119, R12, R120, R121, R122, R123, R124, R131, R132, R133, R134, R135, R136, R143, R144, R145, R146, R147, R148, R155, R156, R157, R158, R159, R160, R19, R20, R207, R208, R209, R21, R210, R211, R212, R219, R22, R220, R221, R222, R223, R224, R23, R231, R232, R233, R234, R235, R236, R24, R243, R244, R245, R246, R247, R248, R255, R256, R257, R258, R259, R260, R307, R308, R309, R31, R310, R311, R312, R319, R32, R320, R321, R322, R323, R324, R33, R331, R332, R333, R334, R335, R336, R34, R343, R344, R345, R346, R347, R348, R35, R355, R356, R357, R358, R359, R36, R360, R43, R44, R45, R46, R47, R48, R55, R56, R57, R58, R59, R60, R7, R8, R9 | 0603 | 120 | 1k | C21190
R161, R167, R168, R169, R176, R177, R178, R185, R186, R187, R261, R267, R268, R269, R276, R277, R278, R285, R286, R287, R361, R367, R368, R369, R376, R377, R378, R385, R386, R387, R61, R67, R68, R69, R76, R77, R78, R85, R86, R87 | 0603 | 40 | 47k | C25819
R162, R170, R171, R172, R179, R180, R181, R188, R189, R190, R262, R270, R271, R272, R279, R280, R281, R288, R289, R290, R362, R370, R371, R372, R379, R380, R381, R388, R389, R390, R62, R70, R71, R72, R79, R80, R81, R88, R89, R90 | 0603 | 40 | 15k | C22809
R163, R164, R165, R173, R174, R175, R263, R264, R265, R273, R274, R275, R363, R364, R365, R373, R374, R375, R63, R64, R65, R73, R74, R75 | 0603 | 24 | 6.8k | C25241
R166, R182, R183, R184, R191, R192, R193, R266, R282, R283, R284, R291, R292, R293, R366, R382, R383, R384, R391, R392, R393, R66, R82, R83, R84, R91, R92, R93 | 0603 | 28 | 470 | C25241
SW1 | EC11_miniboard_castellated | 1 | C0_K0 | dnp
SW10 | EC11_miniboard_castellated | 1 | C0_K9 | dnp
SW101 | EC11_miniboard_castellated | 1 | C1_K0 | dnp
SW102 | EC11_miniboard_castellated | 1 | C1_K1 | dnp
SW103 | EC11_miniboard_castellated | 1 | C1_K2 | dnp
SW104 | EC11_miniboard_castellated | 1 | C1_K3 | dnp
SW105 | EC11_miniboard_castellated | 1 | C1_K4 | dnp
SW106 | EC11_miniboard_castellated | 1 | C1_K5 | dnp
SW107 | EC11_miniboard_castellated | 1 | C1_K6 | dnp
SW108 | EC11_miniboard_castellated | 1 | C1_K7 | dnp
SW109 | EC11_miniboard_castellated | 1 | C1_K8 | dnp
SW11 | CFPB-1CC-4W6_LOWPROF | 1 | C0_B0 | dnp
SW110 | EC11_miniboard_castellated | 1 | C1_K9 | dnp
SW111 | CFPB-1CC-4W6_LOWPROF | 1 | C1_B0 | dnp
SW112 | TL2201EEZB | 1 | C1_B1 | dnp
SW113 | TL2201EEZB | 1 | C1_B2 | dnp
SW114 | TL2201EEZB | 1 | C1_B3 | dnp
SW115 | CFPB-1CC-4W6_LOWPROF | 1 | C1_B4 | dnp
SW116 | CFPB-1CC-4W6_LOWPROF | 1 | C1_B5 | dnp
SW117 | CFPB-1CC-4W6_LOWPROF | 1 | C1_B6 | dnp
SW118 | CFPB-1CC-4W6_LOWPROF | 1 | C1_B7 | dnp
SW119 | CFPB-1CC-4W6_LOWPROF | 1 | C1_B8 | dnp
SW12 | TL2201EEZB | 1 | C0_B1 | dnp
SW120 | CFPB-1CC-4W6_LOWPROF | 1 | C1_B9 | dnp
SW13 | TL2201EEZB | 1 | C0_B2 | dnp
SW14 | TL2201EEZB | 1 | C0_B3 | dnp
SW15 | CFPB-1CC-4W6_LOWPROF | 1 | C0_B4 | dnp
SW16 | CFPB-1CC-4W6_LOWPROF | 1 | C0_B5 | dnp
SW17 | CFPB-1CC-4W6_LOWPROF | 1 | C0_B6 | dnp
SW18 | CFPB-1CC-4W6_LOWPROF | 1 | C0_B7 | dnp
SW19 | CFPB-1CC-4W6_LOWPROF | 1 | C0_B8 | dnp
SW2 | EC11_miniboard_castellated | 1 | C0_K1 | dnp
SW20 | CFPB-1CC-4W6_LOWPROF | 1 | C0_B9 | dnp
SW201 | EC11_miniboard_castellated | 1 | C2_K0 | dnp
SW202 | EC11_miniboard_castellated | 1 | C2_K1 | dnp
SW203 | EC11_miniboard_castellated | 1 | C2_K2 | dnp
SW204 | EC11_miniboard_castellated | 1 | C2_K3 | dnp
SW205 | EC11_miniboard_castellated | 1 | C2_K4 | dnp
SW206 | EC11_miniboard_castellated | 1 | C2_K5 | dnp
SW207 | EC11_miniboard_castellated | 1 | C2_K6 | dnp
SW208 | EC11_miniboard_castellated | 1 | C2_K7 | dnp
SW209 | EC11_miniboard_castellated | 1 | C2_K8 | dnp
SW210 | EC11_miniboard_castellated | 1 | C2_K9 | dnp
SW211 | CFPB-1CC-4W6_LOWPROF | 1 | C2_B0 | dnp
SW212 | TL2201EEZB | 1 | C2_B1 | dnp
SW213 | TL2201EEZB | 1 | C2_B2 | dnp
SW214 | TL2201EEZB | 1 | C2_B3 | dnp
SW215 | CFPB-1CC-4W6_LOWPROF | 1 | C2_B4 | dnp
SW216 | CFPB-1CC-4W6_LOWPROF | 1 | C2_B5 | dnp
SW217 | CFPB-1CC-4W6_LOWPROF | 1 | C2_B6 | dnp
SW218 | CFPB-1CC-4W6_LOWPROF | 1 | C2_B7 | dnp
SW219 | CFPB-1CC-4W6_LOWPROF | 1 | C2_B8 | dnp
SW220 | CFPB-1CC-4W6_LOWPROF | 1 | C2_B9 | dnp
SW3 | EC11_miniboard_castellated | 1 | C0_K2 | dnp
SW301 | EC11_miniboard_castellated | 1 | C3_K0 | dnp
SW302 | EC11_miniboard_castellated | 1 | C3_K1 | dnp
SW303 | EC11_miniboard_castellated | 1 | C3_K2 | dnp
SW304 | EC11_miniboard_castellated | 1 | C3_K3 | dnp
SW305 | EC11_miniboard_castellated | 1 | C3_K4 | dnp
SW306 | EC11_miniboard_castellated | 1 | C3_K5 | dnp
SW307 | EC11_miniboard_castellated | 1 | C3_K6 | dnp
SW308 | EC11_miniboard_castellated | 1 | C3_K7 | dnp
SW309 | EC11_miniboard_castellated | 1 | C3_K8 | dnp
SW310 | EC11_miniboard_castellated | 1 | C3_K9 | dnp
SW311 | CFPB-1CC-4W6_LOWPROF | 1 | C3_B0 | dnp
SW312 | TL2201EEZB | 1 | C3_B1 | dnp
SW313 | TL2201EEZB | 1 | C3_B2 | dnp
SW314 | TL2201EEZB | 1 | C3_B3 | dnp
SW315 | CFPB-1CC-4W6_LOWPROF | 1 | C3_B4 | dnp
SW316 | CFPB-1CC-4W6_LOWPROF | 1 | C3_B5 | dnp
SW317 | CFPB-1CC-4W6_LOWPROF | 1 | C3_B6 | dnp
SW318 | CFPB-1CC-4W6_LOWPROF | 1 | C3_B7 | dnp
SW319 | CFPB-1CC-4W6_LOWPROF | 1 | C3_B8 | dnp
SW320 | CFPB-1CC-4W6_LOWPROF | 1 | C3_B9 | dnp
SW4 | EC11_miniboard_castellated | 1 | C0_K3 | dnp
SW5 | EC11_miniboard_castellated | 1 | C0_K4 | dnp
SW6 | EC11_miniboard_castellated | 1 | C0_K5 | dnp
SW7 | EC11_miniboard_castellated | 1 | C0_K6 | dnp
SW8 | EC11_miniboard_castellated | 1 | C0_K7 | dnp
SW9 | EC11_miniboard_castellated | 1 | C0_K8 | dnp
U1, U2, U3, U4, U5, U6, U7, U8 | SOIC-16_3.9x9.9mm_P1.27mm | 8 | 74HCT595 | C282339
U10 | QFN-28-1EP_6x6mm_P0.65mm_EP4.25x4.25mm | 1 | MCP23017_I2C1_0x21 | C629439
U11 | QFN-28-1EP_6x6mm_P0.65mm_EP4.25x4.25mm | 1 | MCP23017_I2C1_0x22 | C629439
U12 | QFN-28-1EP_6x6mm_P0.65mm_EP4.25x4.25mm | 1 | MCP23017_I2C2_0x20 | C629439
U13 | QFN-28-1EP_6x6mm_P0.65mm_EP4.25x4.25mm | 1 | MCP23017_I2C2_0x21 | C629439
U14 | QFN-28-1EP_6x6mm_P0.65mm_EP4.25x4.25mm | 1 | MCP23017_I2C2_0x22 | C629439
U15 | QFN-28-1EP_6x6mm_P0.65mm_EP4.25x4.25mm | 1 | MCP23017_I2C3_0x20 | C629439
U16 | QFN-28-1EP_6x6mm_P0.65mm_EP4.25x4.25mm | 1 | MCP23017_I2C4_0x20 | C629439
U17 | QFN-28-1EP_6x6mm_P0.65mm_EP4.25x4.25mm | 1 | MCP23017_I2C3_0x21 | C629439
U18 | QFN-28-1EP_6x6mm_P0.65mm_EP4.25x4.25mm | 1 | MCP23017_I2C4_0x21 | C629439
U19 | QFN-28-1EP_6x6mm_P0.65mm_EP4.25x4.25mm | 1 | MCP23017_I2C3_0x22 | C629439
U20 | QFN-28-1EP_6x6mm_P0.65mm_EP4.25x4.25mm | 1 | MCP23017_I2C4_0x22 | C629439
U9 | QFN-28-1EP_6x6mm_P0.65mm_EP4.25x4.25mm | 1 | MCP23017_I2C1_0x20 | C629439

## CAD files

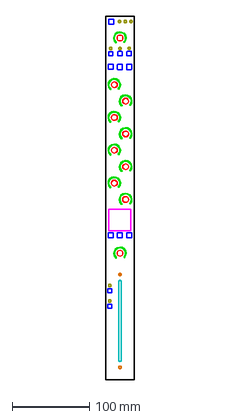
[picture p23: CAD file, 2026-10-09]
PCB_CAD/channel_strip_faceplate.dxf
36.3 x 470.0 mm

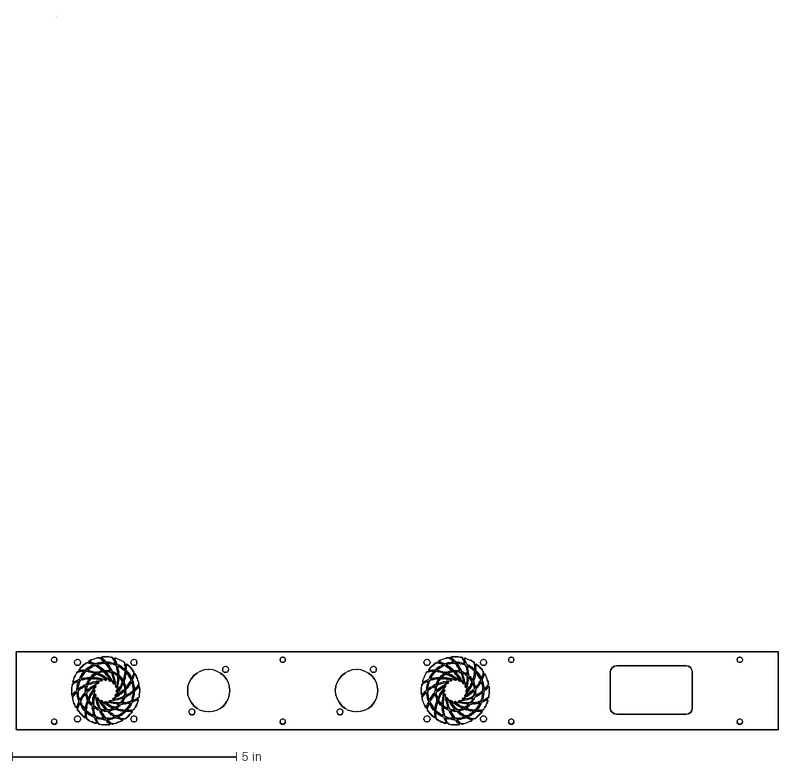
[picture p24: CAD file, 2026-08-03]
PCB_CAD/05 PSU/PRODUCTION_FILES/sheet-metal-fab-chassis-panel-1mm_5052_aluminium_2D_CNC/panel_19in_nohole.dxf
17.0 x 15.9 in

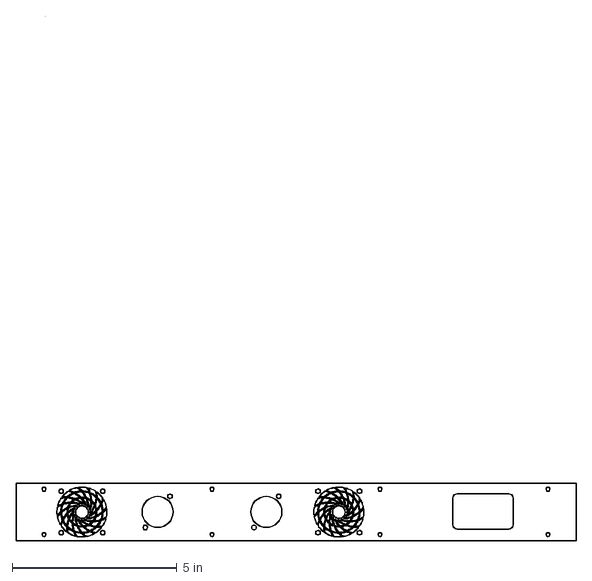
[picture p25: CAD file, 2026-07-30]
PCB_CAD/05 PSU/PRODUCTION_FILES/sheet-metal-fab-chassis-panel-1mm_5052_aluminium_2D_CNC/panel_19in.dxf
17.0 x 15.9 in

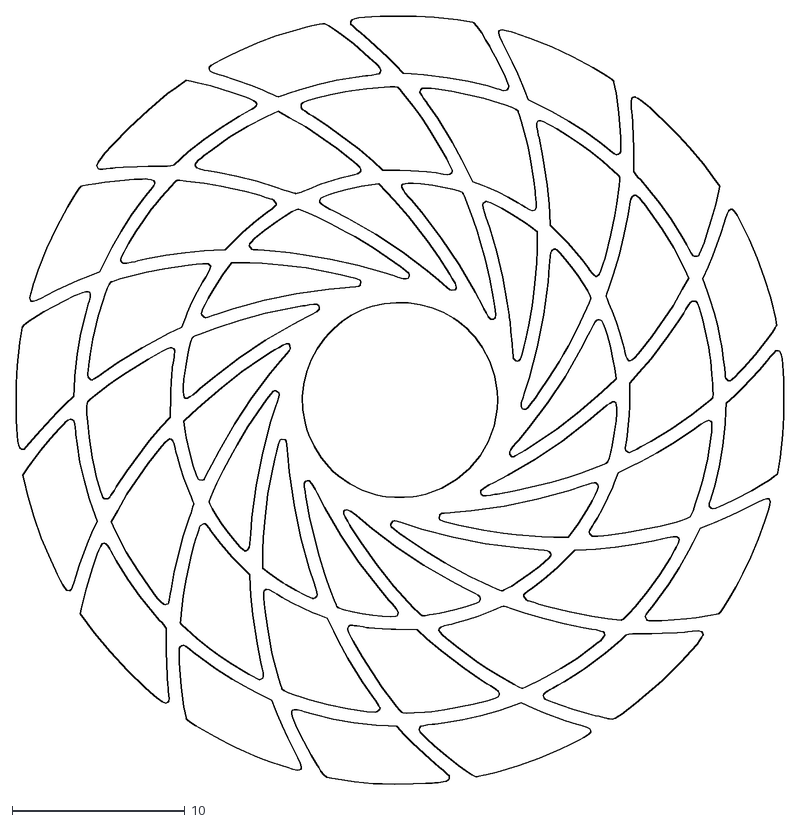
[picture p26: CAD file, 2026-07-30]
PCB_CAD/05 PSU/PRODUCTION_FILES/sheet-metal-fab-chassis-panel-1mm_5052_aluminium_2D_CNC/fanguard.dxf
44.5 x 44.5

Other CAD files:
PCB_CAD/05 PSU/PRODUCTION_FILES/sheet-metal-fab-chassis-panel-1mm_5052_aluminium_2D_CNC/smps_bracket.dxf
PCB_CAD/PSU/PRODUCTION_FILES/sheet-metal-fab-chassis-panel-1mm_5052_aluminium_2D_CNC/smps_bracket.dxf

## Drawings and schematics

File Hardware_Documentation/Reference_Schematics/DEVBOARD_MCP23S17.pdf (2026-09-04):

# EXPAND Click schematic v100

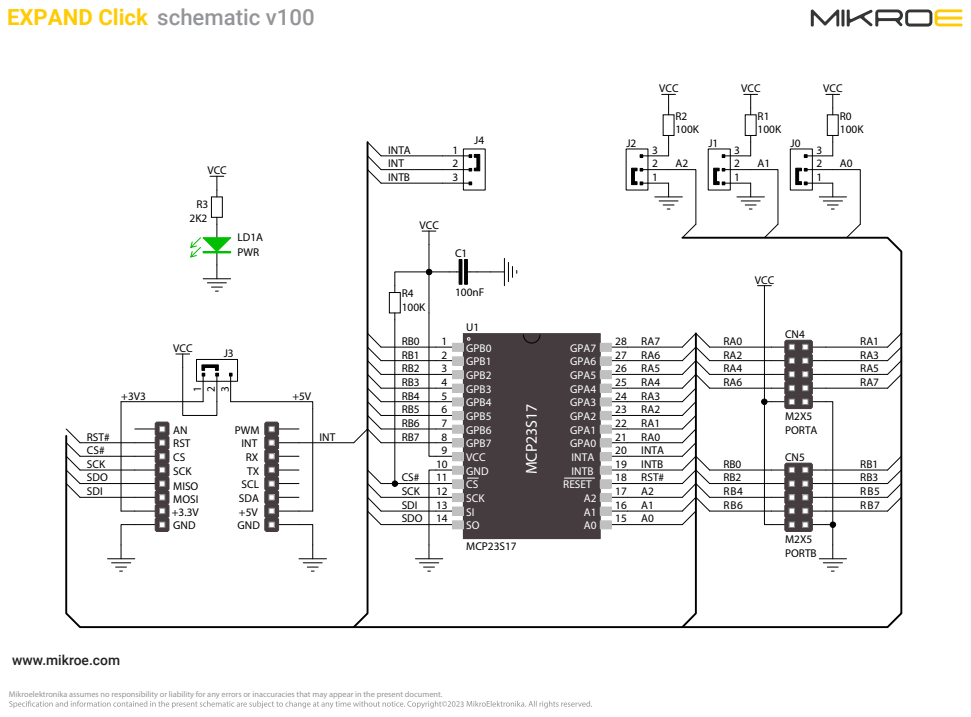
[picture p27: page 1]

Mikroelektronika assumes no responsibility or liability for any errors or inaccuracies that may appear in the present document.

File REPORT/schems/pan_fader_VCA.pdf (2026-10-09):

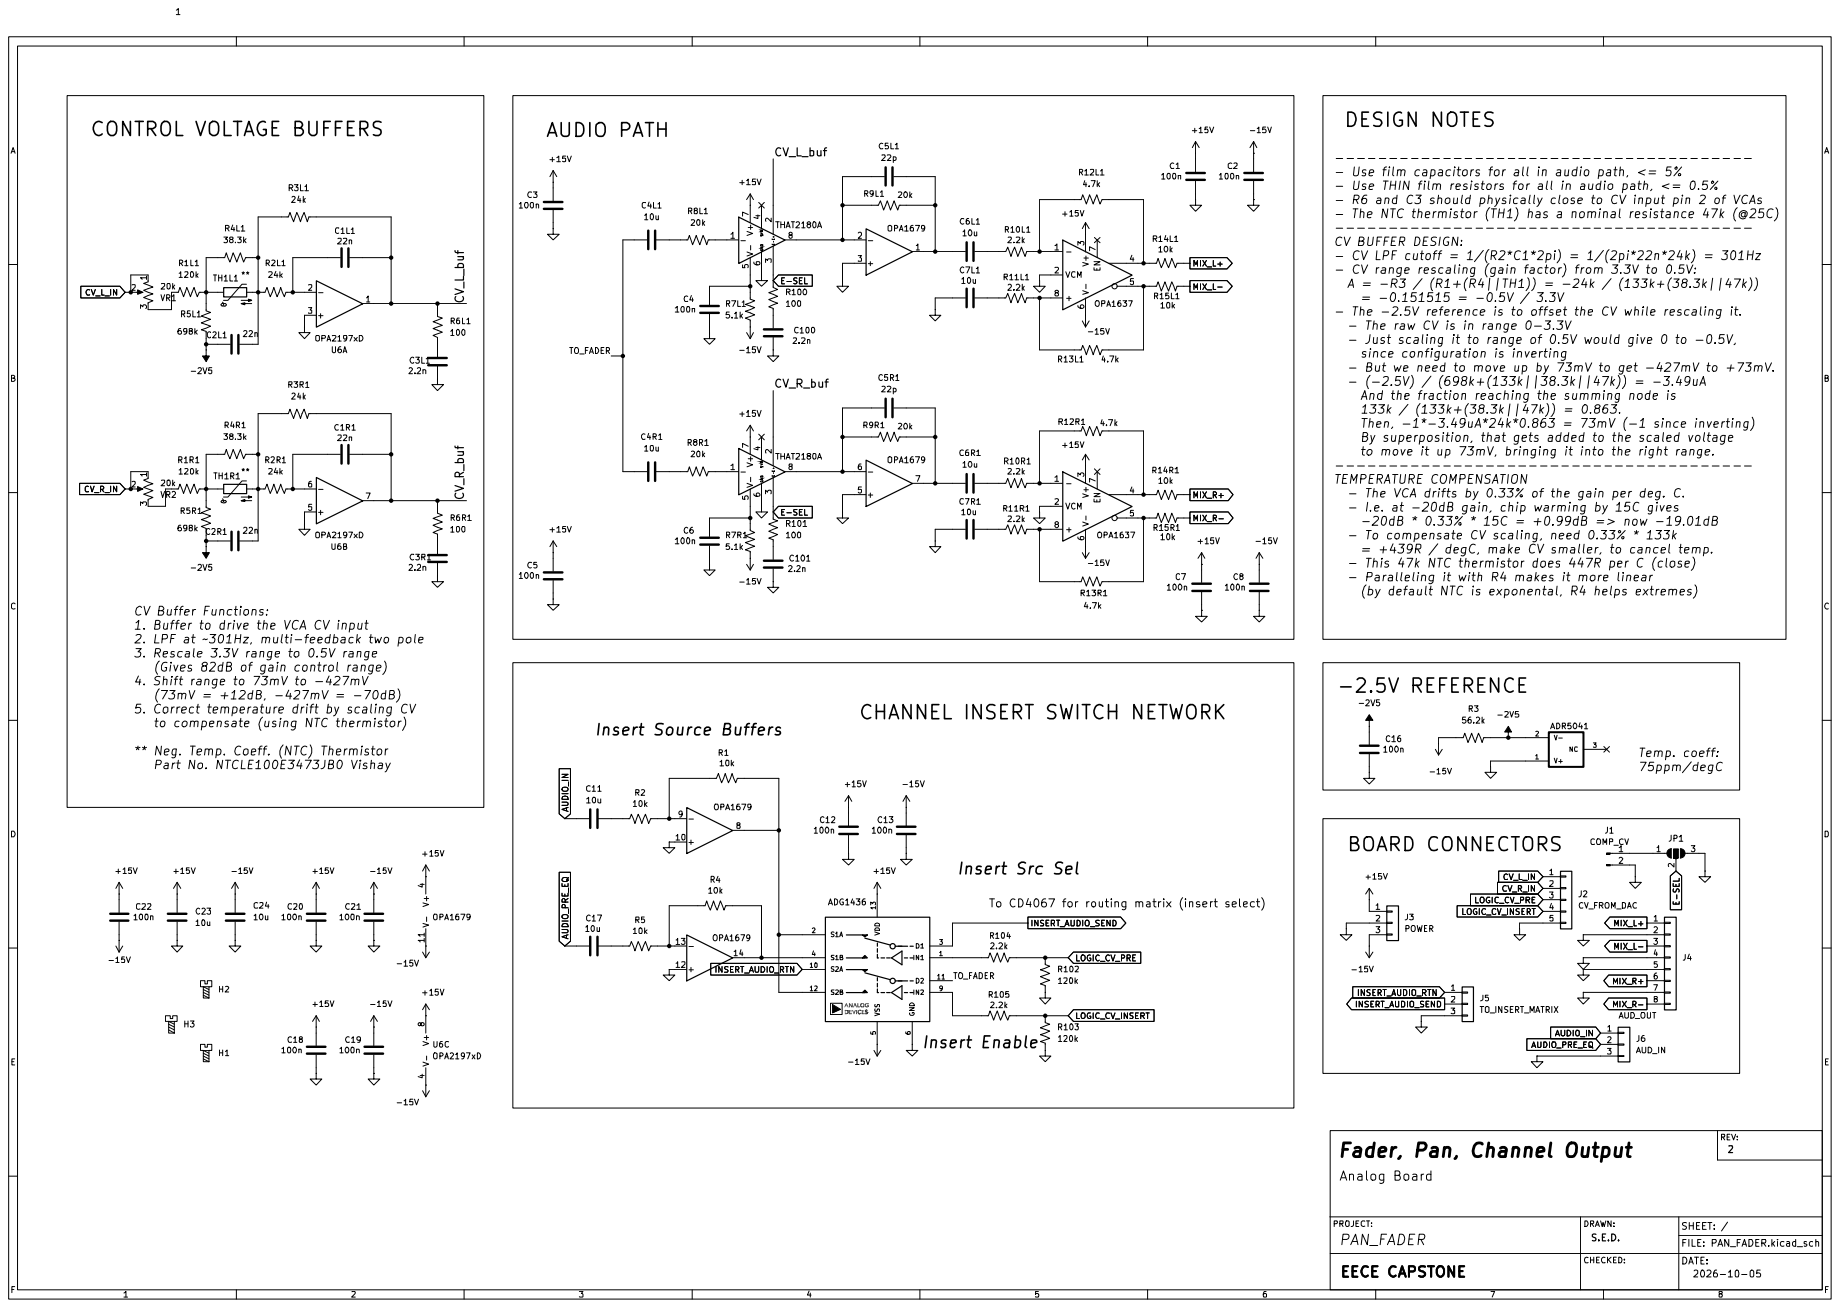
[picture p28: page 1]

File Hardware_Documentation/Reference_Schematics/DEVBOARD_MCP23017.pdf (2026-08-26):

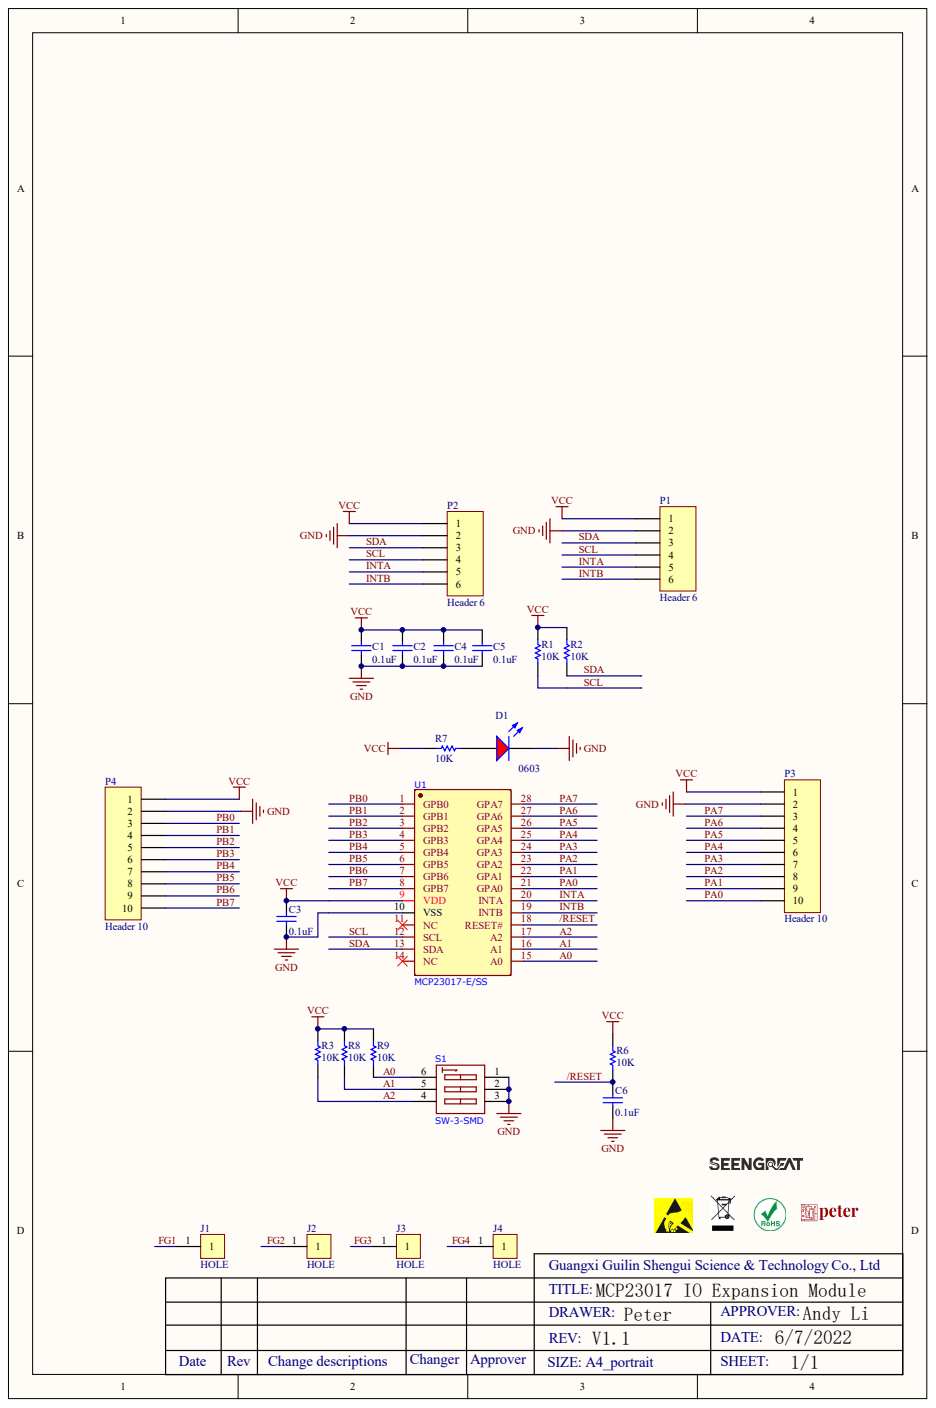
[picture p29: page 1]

PB6 | VDD 9

A1 5 | 2
A2 4 | 3

Guangxi Guilin Shengui Science & Technology Co., Ltd

TITLE: MCP23017 IO Expansion Module
Peter DRAWER: | APPROVER: Andy Li
V1.1 REV: | 6/7/2022 DATE:

Date | Rev | Change descriptions | Changer | Approver | SIZE: A4_portrait | SHEET: 1/1

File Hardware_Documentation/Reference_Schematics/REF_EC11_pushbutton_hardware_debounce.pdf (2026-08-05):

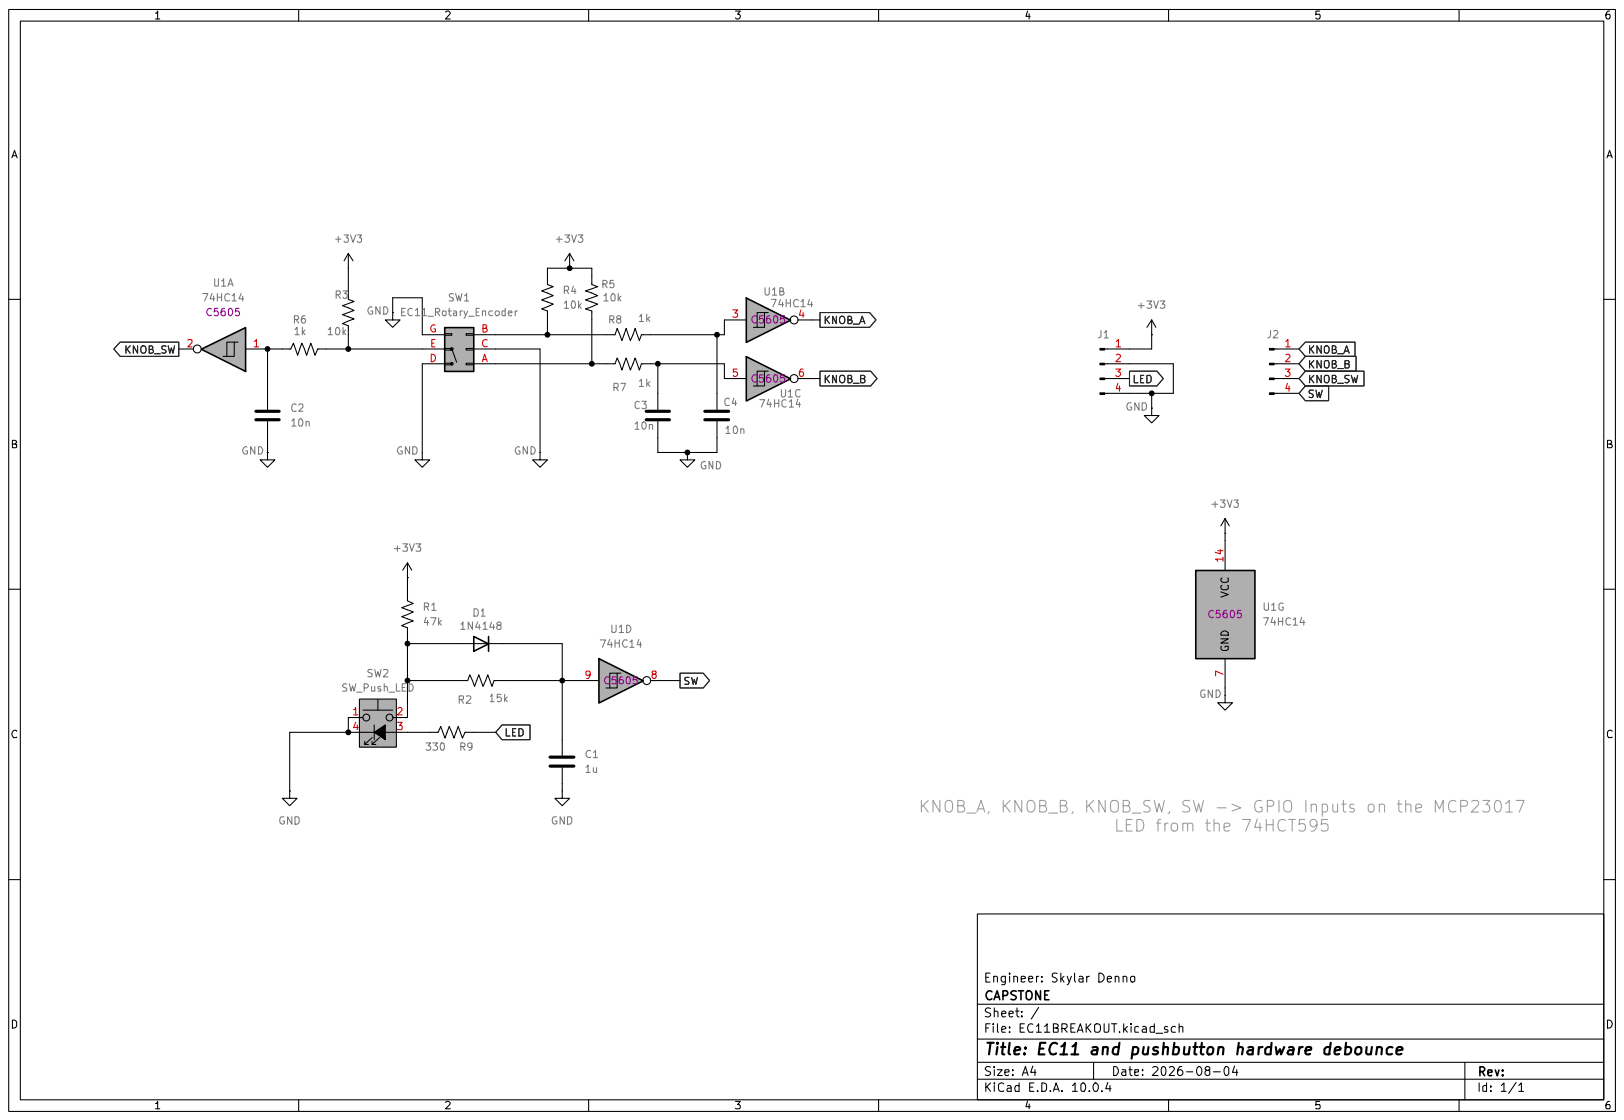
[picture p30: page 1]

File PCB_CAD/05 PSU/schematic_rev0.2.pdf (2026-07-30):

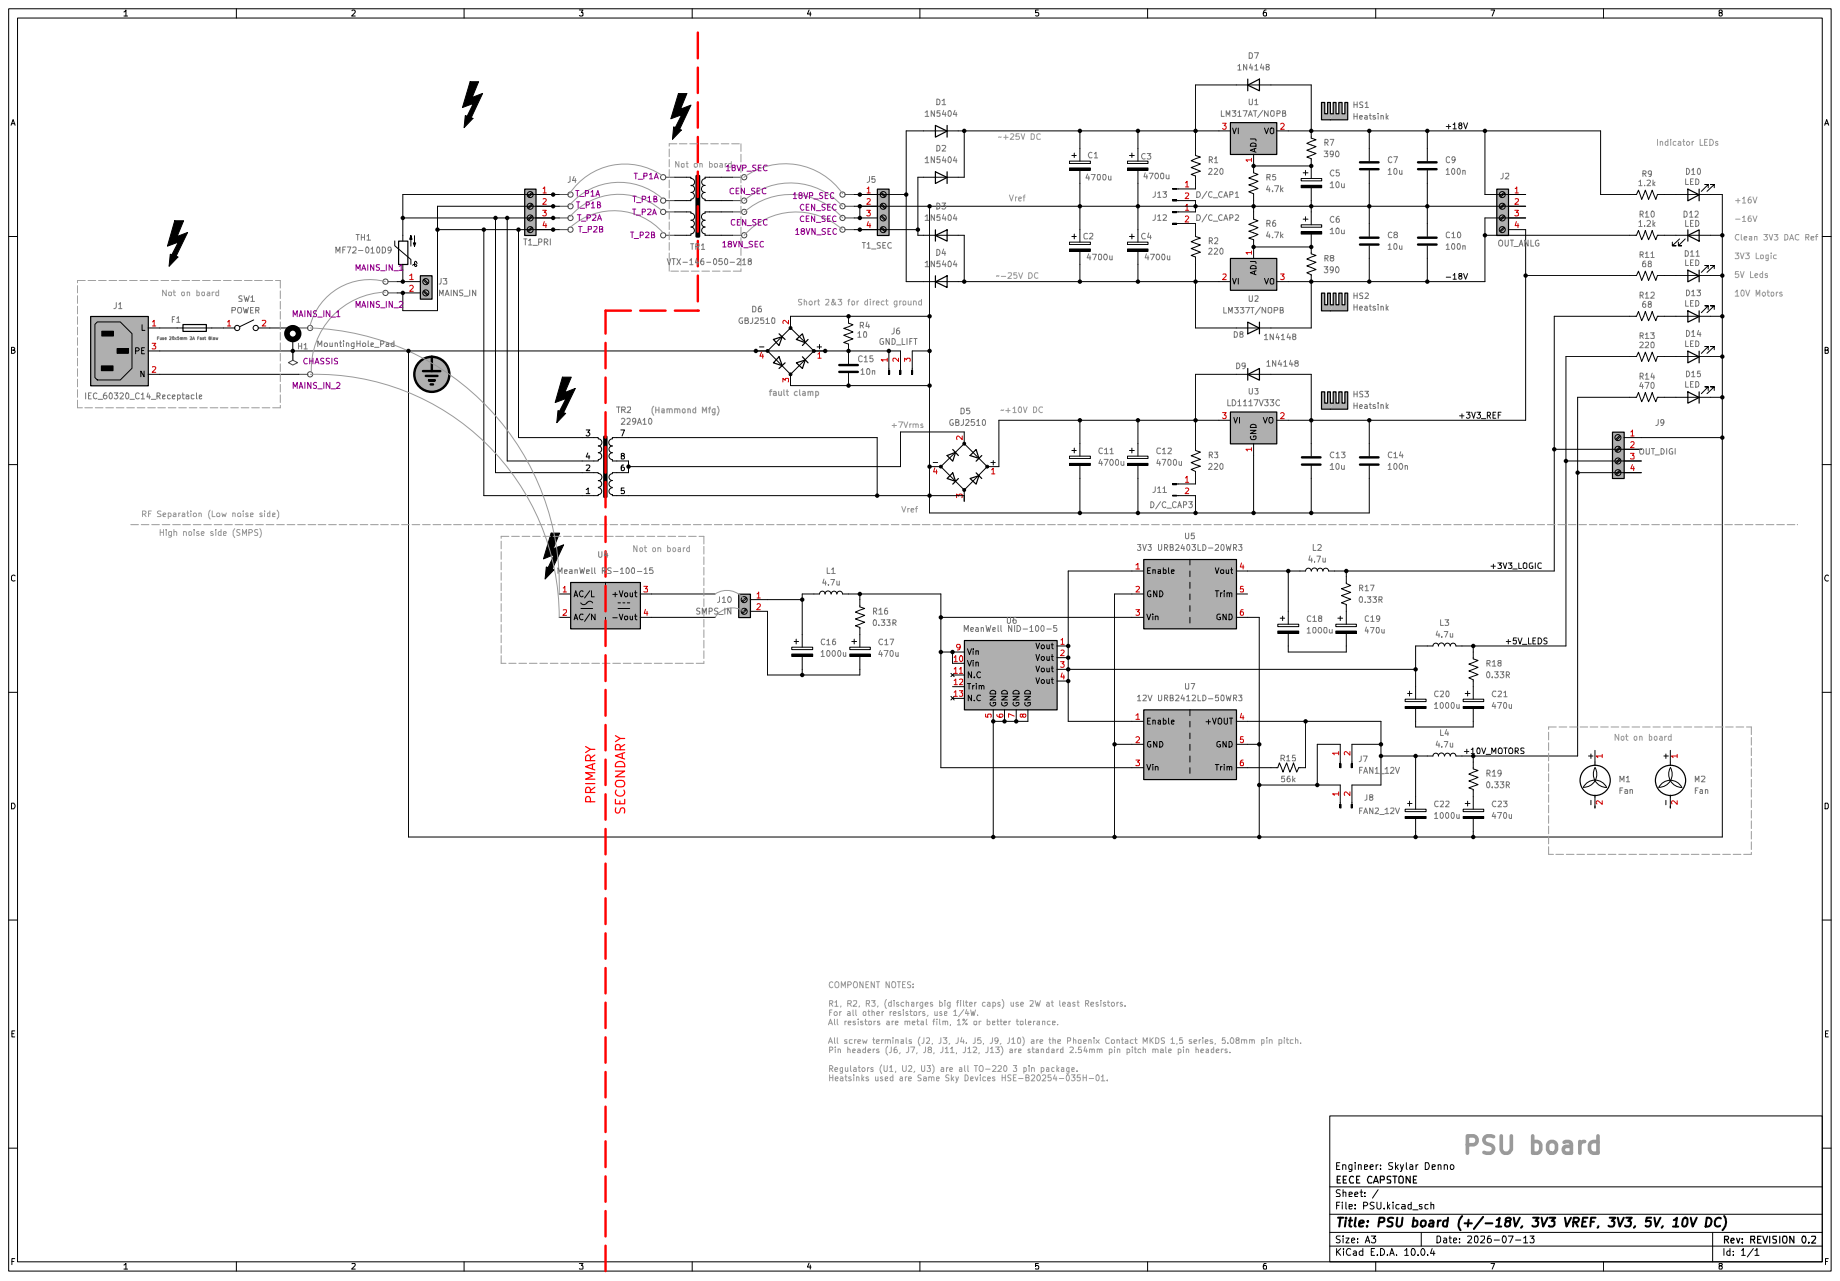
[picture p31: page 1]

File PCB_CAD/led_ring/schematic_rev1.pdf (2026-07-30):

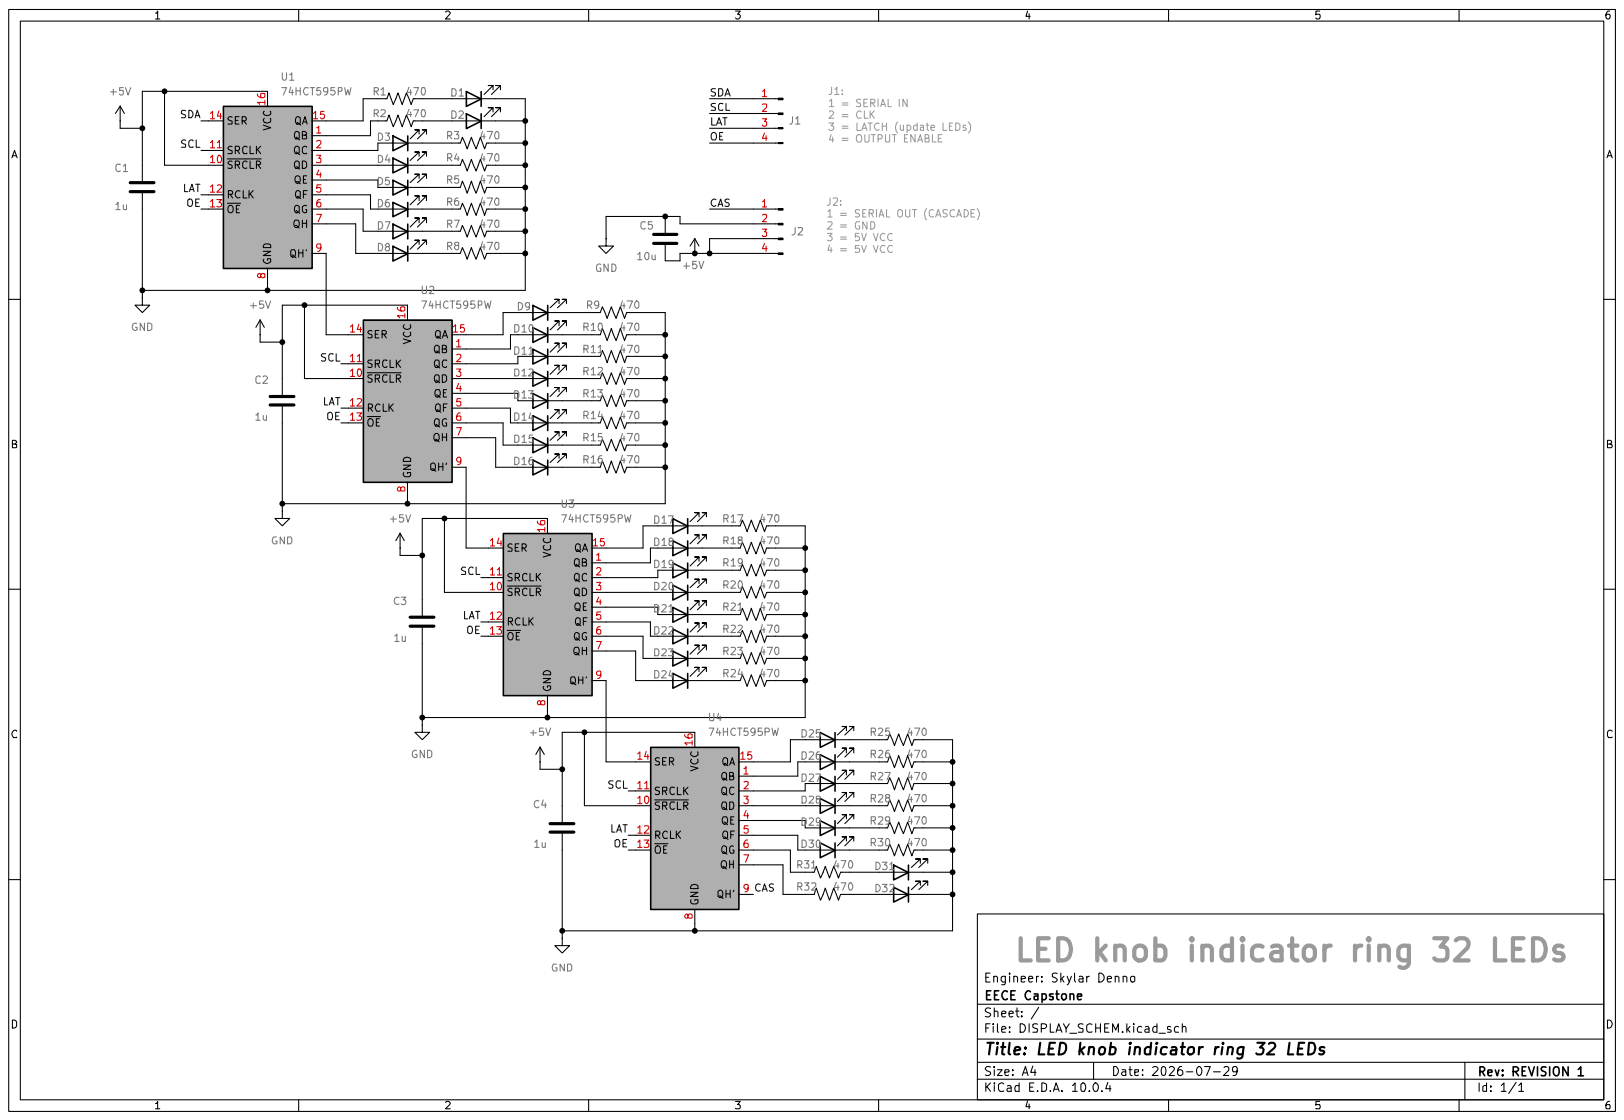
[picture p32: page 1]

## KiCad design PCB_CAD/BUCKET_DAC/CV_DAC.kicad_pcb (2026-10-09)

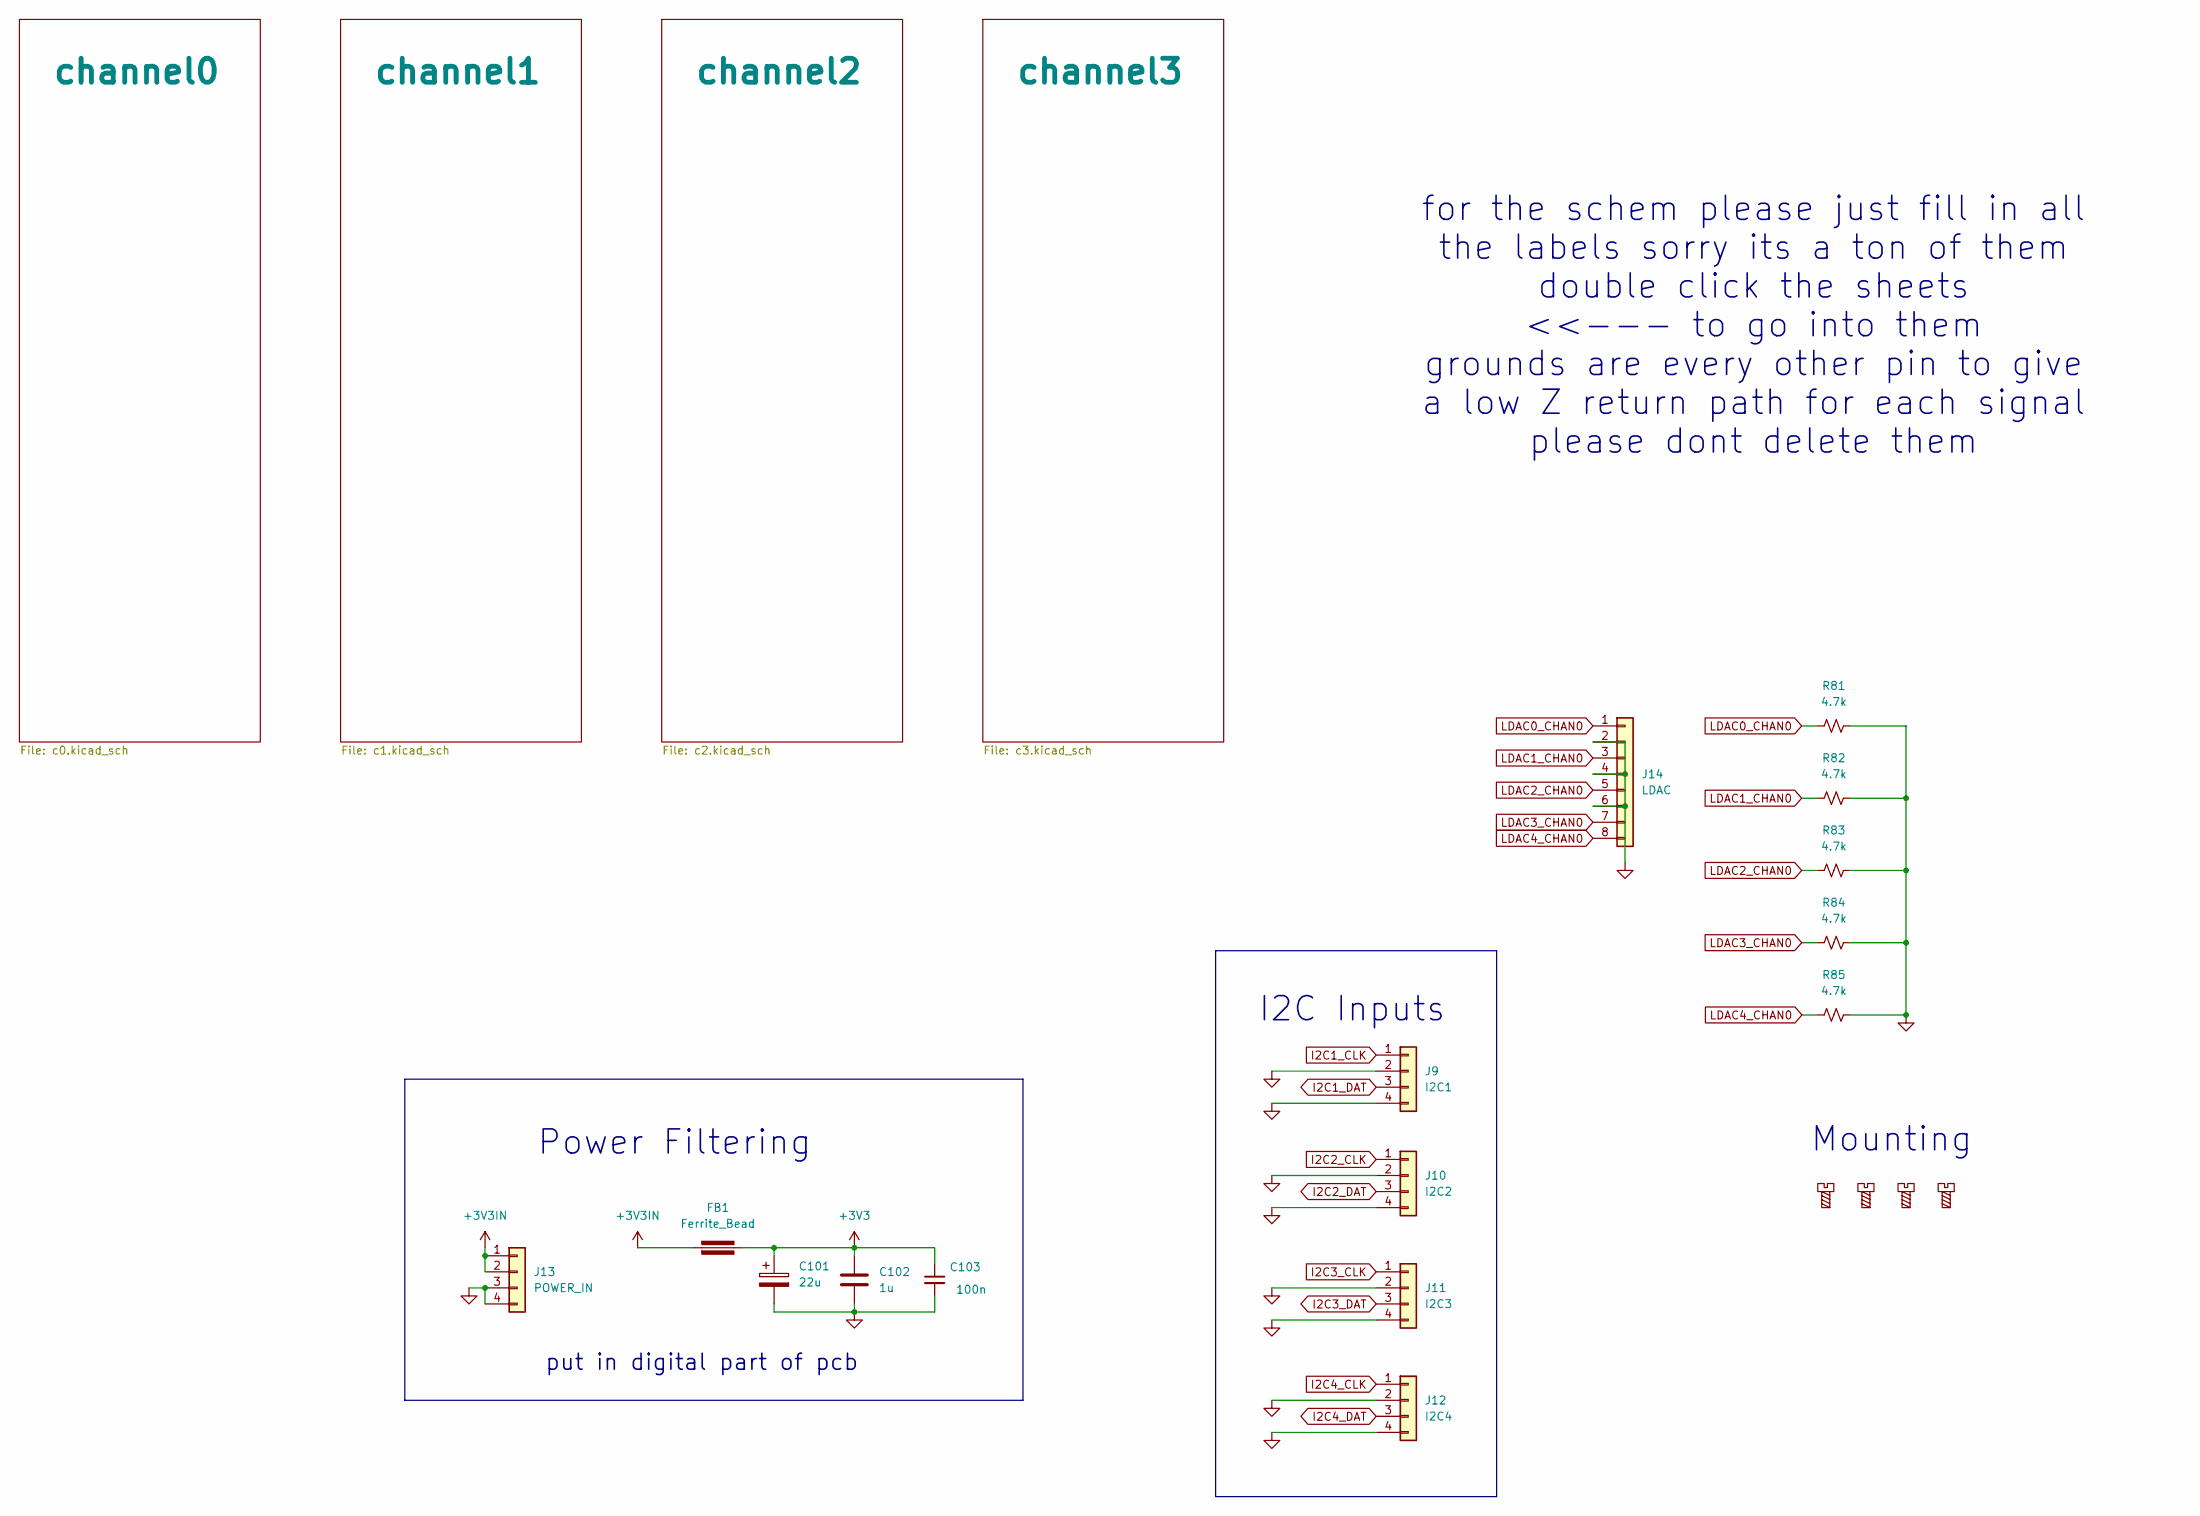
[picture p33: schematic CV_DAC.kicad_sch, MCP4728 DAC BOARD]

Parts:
C101: 22u; CP_Elec_5x5.4; LCSC C23289
C102: 1u; C_0603_1608Metric; LCSC C1592
C103: 100n; C_0402_1005Metric; LCSC C1525
FB1: Ferrite_Bead; Ferrite_1206_3216Metric; LCSC C16902
H1, H2, H3, H4: MountingScrew; MountingHole_3.2mm_M3
J9: I2C1; PinHeader_1x04_P2.54mm_Vertical
J10: I2C2; PinHeader_1x04_P2.54mm_Vertical
J11: I2C3; PinHeader_1x04_P2.54mm_Vertical
J12: I2C4; PinHeader_1x04_P2.54mm_Vertical
J13: POWER_IN; PinHeader_1x04_P2.54mm_Vertical
J14: LDAC; PinHeader_1x08_P2.54mm_Vertical
R81, R82, R83, R84, R85: 4.7k; R_Axial_DIN0207_L6.3mm_D2.5mm_P2.54mm_Vertical; LCSC dnp

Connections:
+3V3: C101.1, C102.1, C103.1, FB1.2; also elsewhere on the board
+3V3IN: FB1.1, J13.1, J13.2
GND: C101.2, C102.2, C103.2, J9.2, J9.4, J10.2, J10.4, J11.2, J11.4, J12.2, J12.4, J13.3, J13.4, J14.2, J14.4, J14.6, R81.2, R82.2, R83.2, R84.2, R85.2; also elsewhere on the board
I2C1_CLK: J9.1; also elsewhere on the board
I2C1_DAT: J9.3; also elsewhere on the board
I2C2_CLK: J10.1; also elsewhere on the board
I2C2_DAT: J10.3; also elsewhere on the board
I2C3_CLK: J11.1; also elsewhere on the board
I2C3_DAT: J11.3; also elsewhere on the board
I2C4_CLK: J12.1; also elsewhere on the board
I2C4_DAT: J12.3; also elsewhere on the board
LDAC0_CHAN0: J14.1, R81.1; also elsewhere on the board
LDAC1_CHAN0: J14.3, R82.1; also elsewhere on the board
LDAC2_CHAN0: J14.5, R83.1; also elsewhere on the board
LDAC3_CHAN0: J14.7, R84.1; also elsewhere on the board
LDAC4_CHAN0: J14.8, R85.1; also elsewhere on the board

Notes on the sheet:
Power Filtering
I2C Inputs
for the schem please just fill in all the labels sorry its a ton of them double click the sheets <<--- to go into them grounds are every other pin to give a low Z return path for each signal please dont delete them
Mounting
put in digital part of pcb

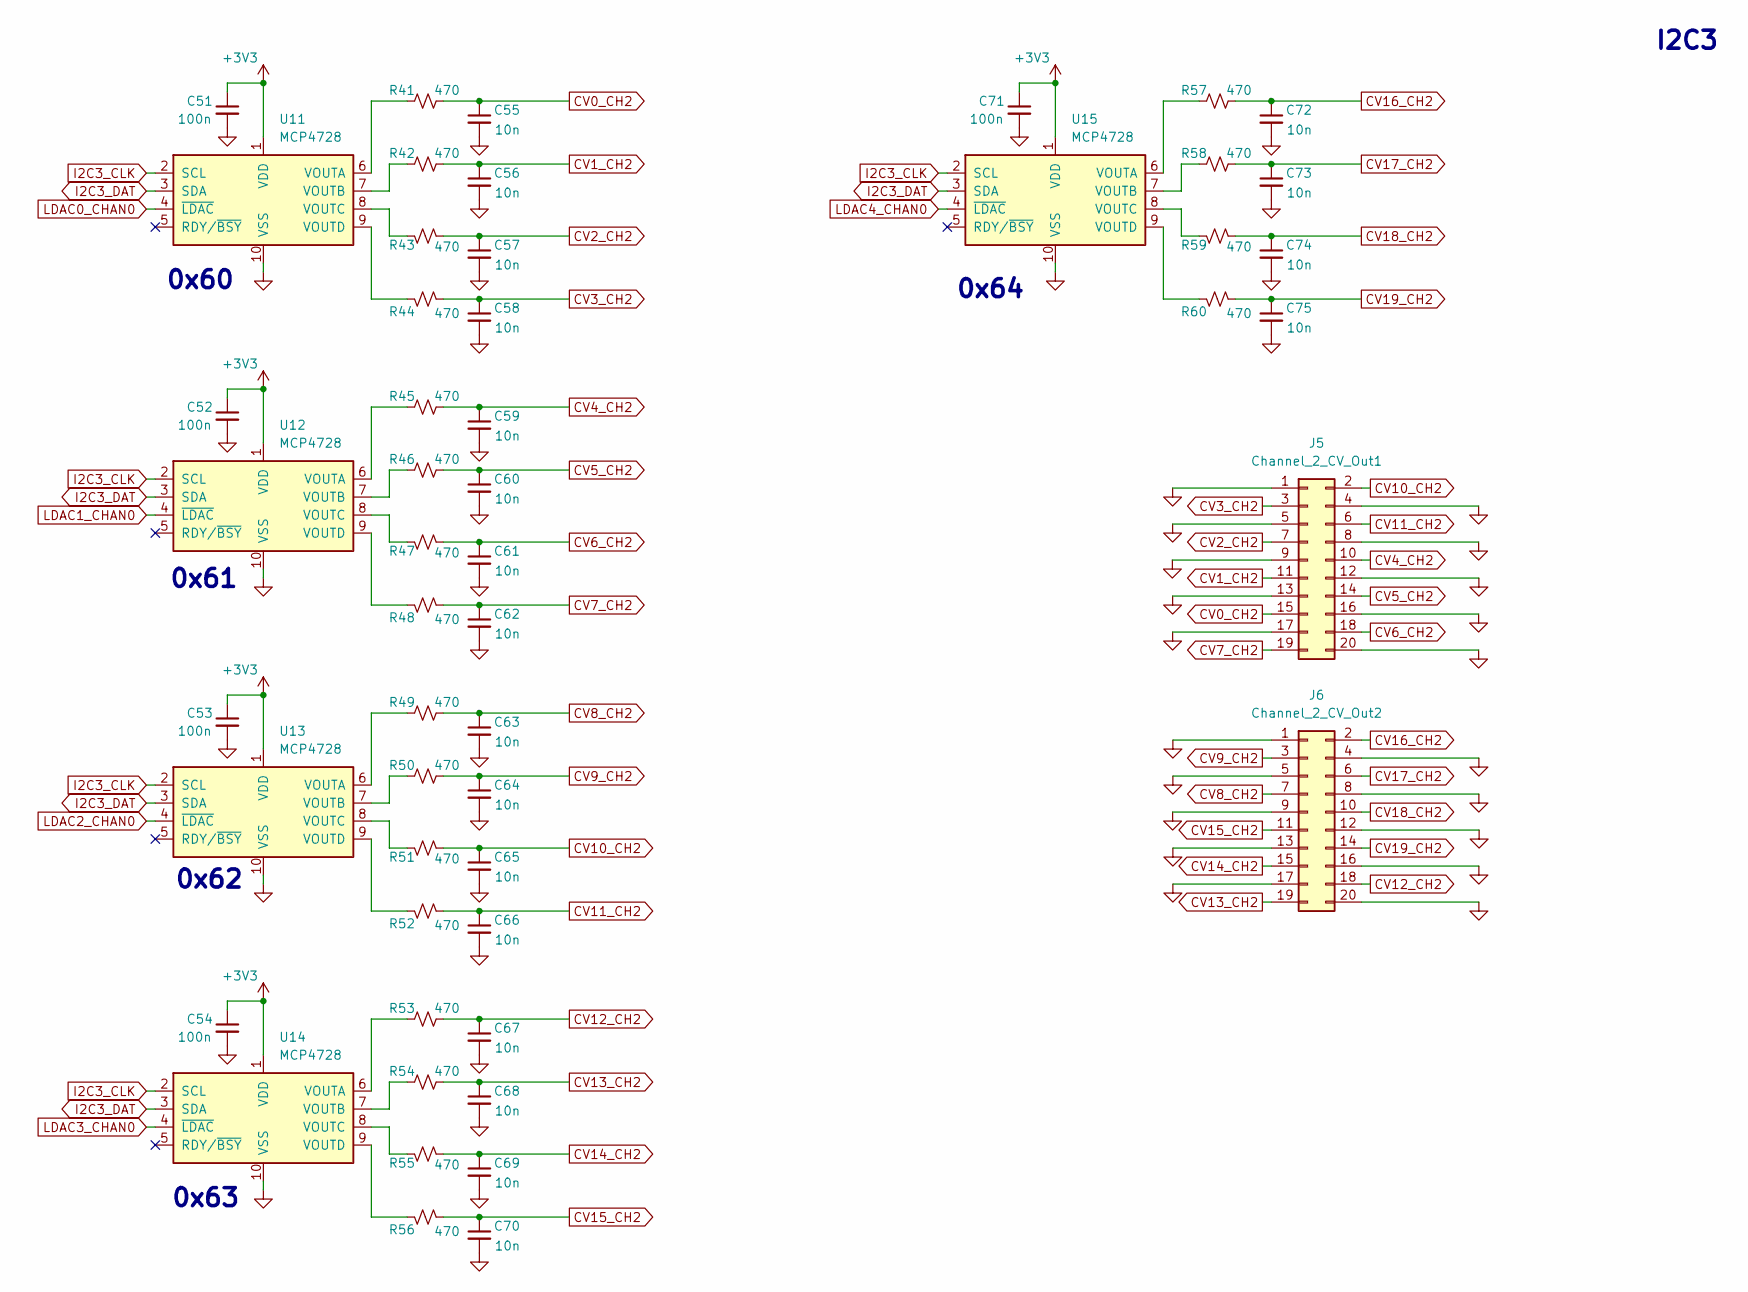
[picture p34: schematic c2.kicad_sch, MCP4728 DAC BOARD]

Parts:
C51, C52, C53, C54, C71: 100n; C_0402_1005Metric; LCSC C1525
C55, C56, C57, C58, C59, C60, C61, C62, C63, C64, C65, C66, C67, C68, C69, C70, C72, C73, C74, C75: 10n; C_0402_1005Metric; LCSC C1524
J5: Channel_2_CV_Out1; PinHeader_2x10_P1.27mm_Vertical
J6: Channel_2_CV_Out2; PinHeader_2x10_P1.27mm_Vertical
R41, R42, R43, R44, R45, R46, R47, R48, R49, R50, R51, R52, R53, R54, R55, R56, R57, R58, R59, R60: 470; R_0402_1005Metric; LCSC C25117
U11, U12, U13, U14, U15: MCP4728; MSOP-10_3x3mm_P0.5mm; LCSC C108207

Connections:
+3V3: C51.1, C52.1, C53.1, C54.1, C71.1, U11.1 (VDD), U12.1 (VDD), U13.1 (VDD), U14.1 (VDD), U15.1 (VDD); also elsewhere on the board
CV0_CH2: C55.1, J5.15, R41.2
CV1_CH2: C56.1, J5.11, R42.2
CV2_CH2: C57.1, J5.7, R43.2
CV3_CH2: C58.1, J5.3, R44.2
CV4_CH2: C59.1, J5.10, R45.2
CV5_CH2: C60.1, J5.14, R46.2
CV6_CH2: C61.1, J5.18, R47.2
CV7_CH2: C62.1, J5.19, R48.2
CV8_CH2: C63.1, J6.7, R49.2
CV9_CH2: C64.1, J6.3, R50.2
CV10_CH2: C65.1, J5.2, R51.2
CV11_CH2: C66.1, J5.6, R52.2
CV12_CH2: C67.1, J6.18, R53.2
CV13_CH2: C68.1, J6.19, R54.2
CV14_CH2: C69.1, J6.15, R55.2
CV15_CH2: C70.1, J6.11, R56.2
CV16_CH2: C72.1, J6.2, R57.2
CV17_CH2: C73.1, J6.6, R58.2
CV18_CH2: C74.1, J6.10, R59.2
CV19_CH2: C75.1, J6.14, R60.2
GND: C51.2, C52.2, C53.2, C54.2, C55.2, C56.2, C57.2, C58.2, C59.2, C60.2, C61.2, C62.2, C63.2, C64.2, C65.2, C66.2, C67.2, C68.2, C69.2, C70.2, C71.2, C72.2, C73.2, C74.2, C75.2, J5.1, J5.4, J5.5, J5.8, J5.9, J5.12, J5.13, J5.16, J5.17, J5.20, J6.1, J6.4, J6.5, J6.8, J6.9, J6.12, J6.13, J6.16, J6.17, J6.20, U11.10 (VSS), U12.10 (VSS), U13.10 (VSS), U14.10 (VSS), U15.10 (VSS); also elsewhere on the board
I2C3_CLK: U11.2 (SCL), U12.2 (SCL), U13.2 (SCL), U14.2 (SCL), U15.2 (SCL); also elsewhere on the board
I2C3_DAT: U11.3 (SDA), U12.3 (SDA), U13.3 (SDA), U14.3 (SDA), U15.3 (SDA); also elsewhere on the board
LDAC0_CHAN0: U11.4 (~LDAC); also elsewhere on the board
LDAC1_CHAN0: U12.4 (~LDAC); also elsewhere on the board
LDAC2_CHAN0: U13.4 (~LDAC); also elsewhere on the board
LDAC3_CHAN0: U14.4 (~LDAC); also elsewhere on the board
LDAC4_CHAN0: U15.4 (~LDAC); also elsewhere on the board
unnamed: R41.1, U11.6 (VOUTA)
unnamed: R42.1, U11.7 (VOUTB)
unnamed: R43.1, U11.8 (VOUTC)
unnamed: R44.1, U11.9 (VOUTD)
unnamed: R45.1, U12.6 (VOUTA)
unnamed: R46.1, U12.7 (VOUTB)
unnamed: R47.1, U12.8 (VOUTC)
unnamed: R48.1, U12.9 (VOUTD)
unnamed: R49.1, U13.6 (VOUTA)
unnamed: R50.1, U13.7 (VOUTB)
unnamed: R51.1, U13.8 (VOUTC)
unnamed: R52.1, U13.9 (VOUTD)
unnamed: R53.1, U14.6 (VOUTA)
unnamed: R54.1, U14.7 (VOUTB)
unnamed: R55.1, U14.8 (VOUTC)
unnamed: R56.1, U14.9 (VOUTD)
unnamed: R57.1, U15.6 (VOUTA)
unnamed: R58.1, U15.7 (VOUTB)
unnamed: R59.1, U15.8 (VOUTC)
unnamed: R60.1, U15.9 (VOUTD)

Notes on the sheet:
0x61
0x63
0x60
0x62
I2C3
0x64

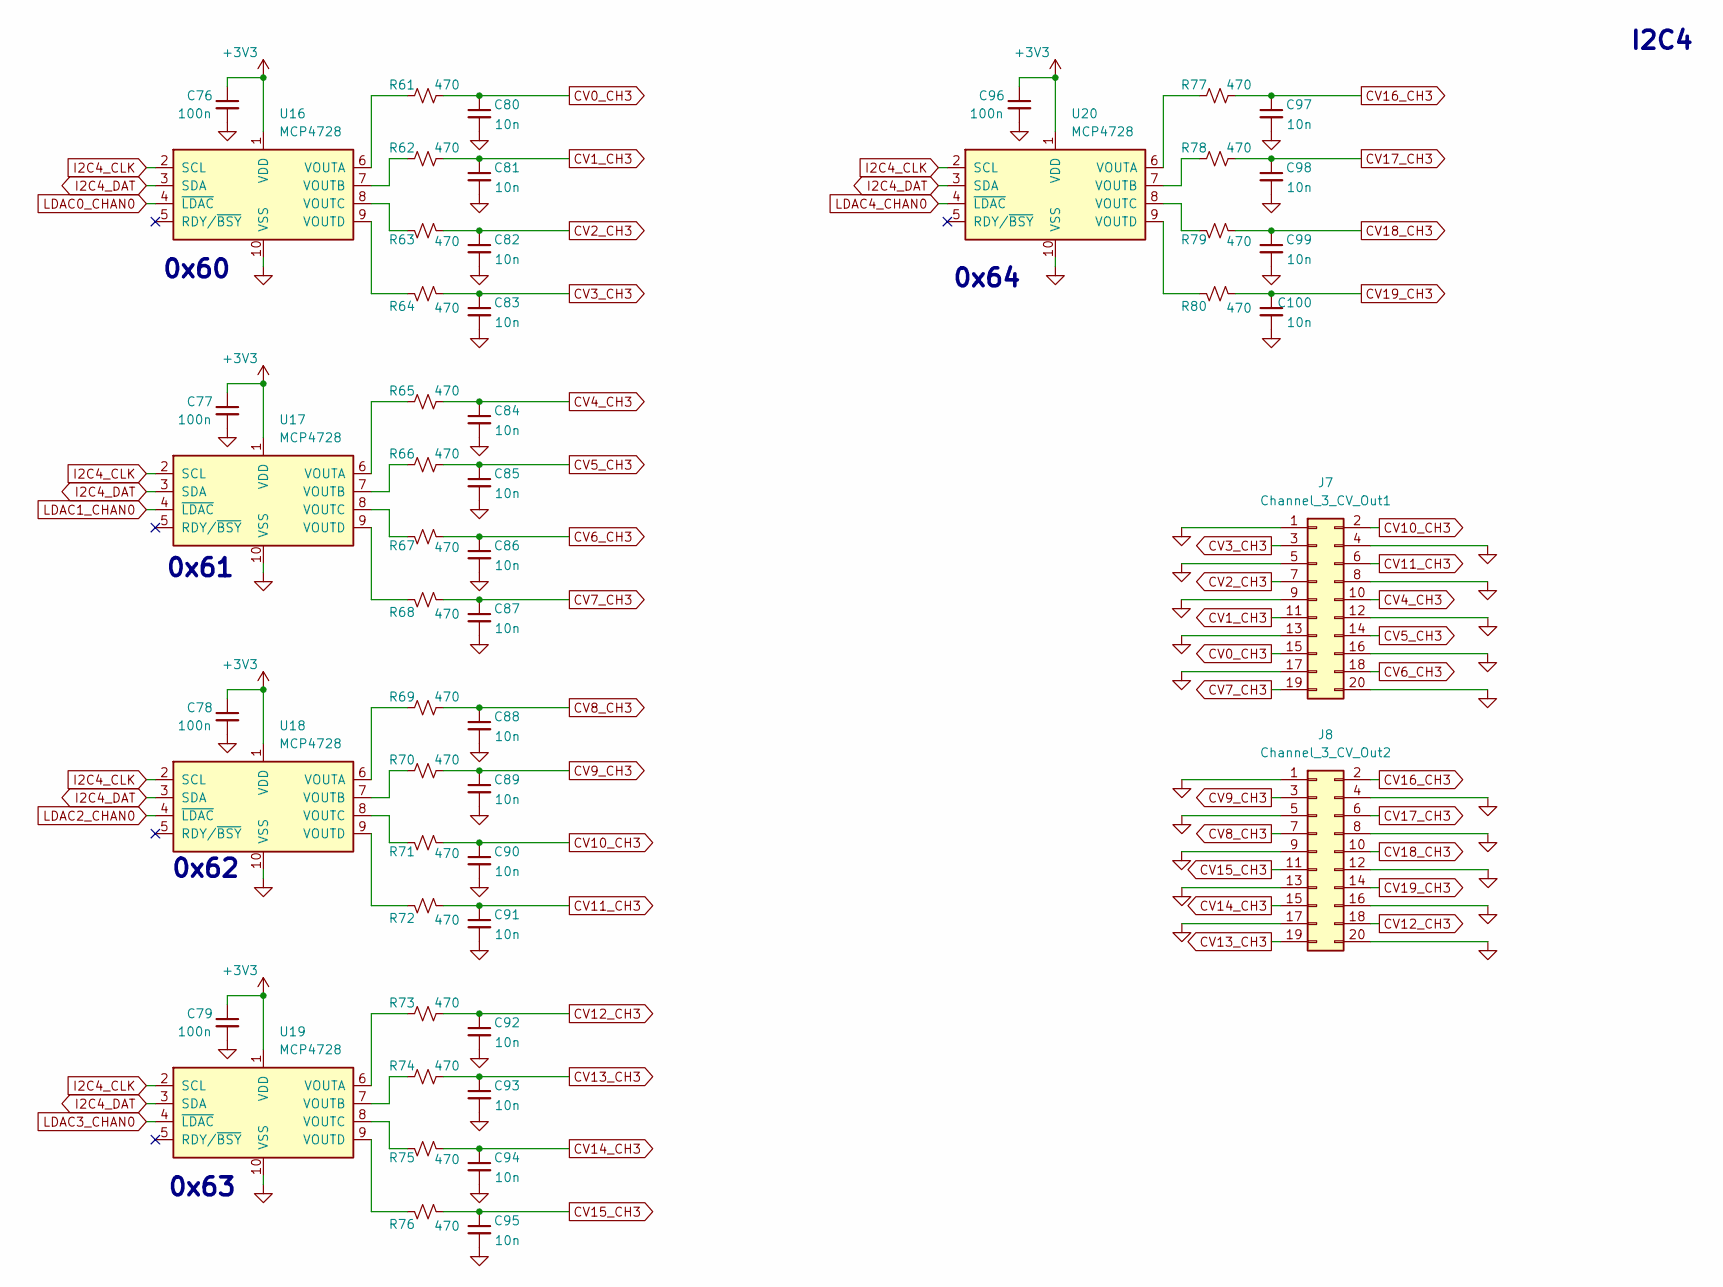
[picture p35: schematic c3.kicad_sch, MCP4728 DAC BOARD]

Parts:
C76, C77, C78, C79, C96: 100n; C_0402_1005Metric; LCSC C1525
C80, C81, C82, C83, C84, C85, C86, C87, C88, C89, C90, C91, C92, C93, C94, C95, C97, C98, C99, C100: 10n; C_0402_1005Metric; LCSC C1524
J7: Channel_3_CV_Out1; PinHeader_2x10_P1.27mm_Vertical
J8: Channel_3_CV_Out2; PinHeader_2x10_P1.27mm_Vertical
R61, R62, R63, R64, R65, R66, R67, R68, R69, R70, R71, R72, R73, R74, R75, R76, R77, R78, R79, R80: 470; R_0402_1005Metric; LCSC C25117
U16, U17, U18, U19, U20: MCP4728; MSOP-10_3x3mm_P0.5mm; LCSC C108207

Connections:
+3V3: C76.1, C77.1, C78.1, C79.1, C96.1, U16.1 (VDD), U17.1 (VDD), U18.1 (VDD), U19.1 (VDD), U20.1 (VDD); also elsewhere on the board
CV0_CH3: C80.1, J7.15, R61.2
CV1_CH3: C81.1, J7.11, R62.2
CV2_CH3: C82.1, J7.7, R63.2
CV3_CH3: C83.1, J7.3, R64.2
CV4_CH3: C84.1, J7.10, R65.2
CV5_CH3: C85.1, J7.14, R66.2
CV6_CH3: C86.1, J7.18, R67.2
CV7_CH3: C87.1, J7.19, R68.2
CV8_CH3: C88.1, J8.7, R69.2
CV9_CH3: C89.1, J8.3, R70.2
CV10_CH3: C90.1, J7.2, R71.2
CV11_CH3: C91.1, J7.6, R72.2
CV12_CH3: C92.1, J8.18, R73.2
CV13_CH3: C93.1, J8.19, R74.2
CV14_CH3: C94.1, J8.15, R75.2
CV15_CH3: C95.1, J8.11, R76.2
CV16_CH3: C97.1, J8.2, R77.2
CV17_CH3: C98.1, J8.6, R78.2
CV18_CH3: C99.1, J8.10, R79.2
CV19_CH3: C100.1, J8.14, R80.2
GND: C76.2, C77.2, C78.2, C79.2, C80.2, C81.2, C82.2, C83.2, C84.2, C85.2, C86.2, C87.2, C88.2, C89.2, C90.2, C91.2, C92.2, C93.2, C94.2, C95.2, C96.2, C97.2, C98.2, C99.2, C100.2, J7.1, J7.4, J7.5, J7.8, J7.9, J7.12, J7.13, J7.16, J7.17, J7.20, J8.1, J8.4, J8.5, J8.8, J8.9, J8.12, J8.13, J8.16, J8.17, J8.20, U16.10 (VSS), U17.10 (VSS), U18.10 (VSS), U19.10 (VSS), U20.10 (VSS); also elsewhere on the board
I2C4_CLK: U16.2 (SCL), U17.2 (SCL), U18.2 (SCL), U19.2 (SCL), U20.2 (SCL); also elsewhere on the board
I2C4_DAT: U16.3 (SDA), U17.3 (SDA), U18.3 (SDA), U19.3 (SDA), U20.3 (SDA); also elsewhere on the board
LDAC0_CHAN0: U16.4 (~LDAC); also elsewhere on the board
LDAC1_CHAN0: U17.4 (~LDAC); also elsewhere on the board
LDAC2_CHAN0: U18.4 (~LDAC); also elsewhere on the board
LDAC3_CHAN0: U19.4 (~LDAC); also elsewhere on the board
LDAC4_CHAN0: U20.4 (~LDAC); also elsewhere on the board
unnamed: R61.1, U16.6 (VOUTA)
unnamed: R62.1, U16.7 (VOUTB)
unnamed: R63.1, U16.8 (VOUTC)
unnamed: R64.1, U16.9 (VOUTD)
unnamed: R65.1, U17.6 (VOUTA)
unnamed: R66.1, U17.7 (VOUTB)
unnamed: R67.1, U17.8 (VOUTC)
unnamed: R68.1, U17.9 (VOUTD)
unnamed: R69.1, U18.6 (VOUTA)
unnamed: R70.1, U18.7 (VOUTB)
unnamed: R71.1, U18.8 (VOUTC)
unnamed: R72.1, U18.9 (VOUTD)
unnamed: R73.1, U19.6 (VOUTA)
unnamed: R74.1, U19.7 (VOUTB)
unnamed: R75.1, U19.8 (VOUTC)
unnamed: R76.1, U19.9 (VOUTD)
unnamed: R77.1, U20.6 (VOUTA)
unnamed: R78.1, U20.7 (VOUTB)
unnamed: R79.1, U20.8 (VOUTC)
unnamed: R80.1, U20.9 (VOUTD)

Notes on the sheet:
0x60
0x62
0x63
0x64
I2C4
0x61

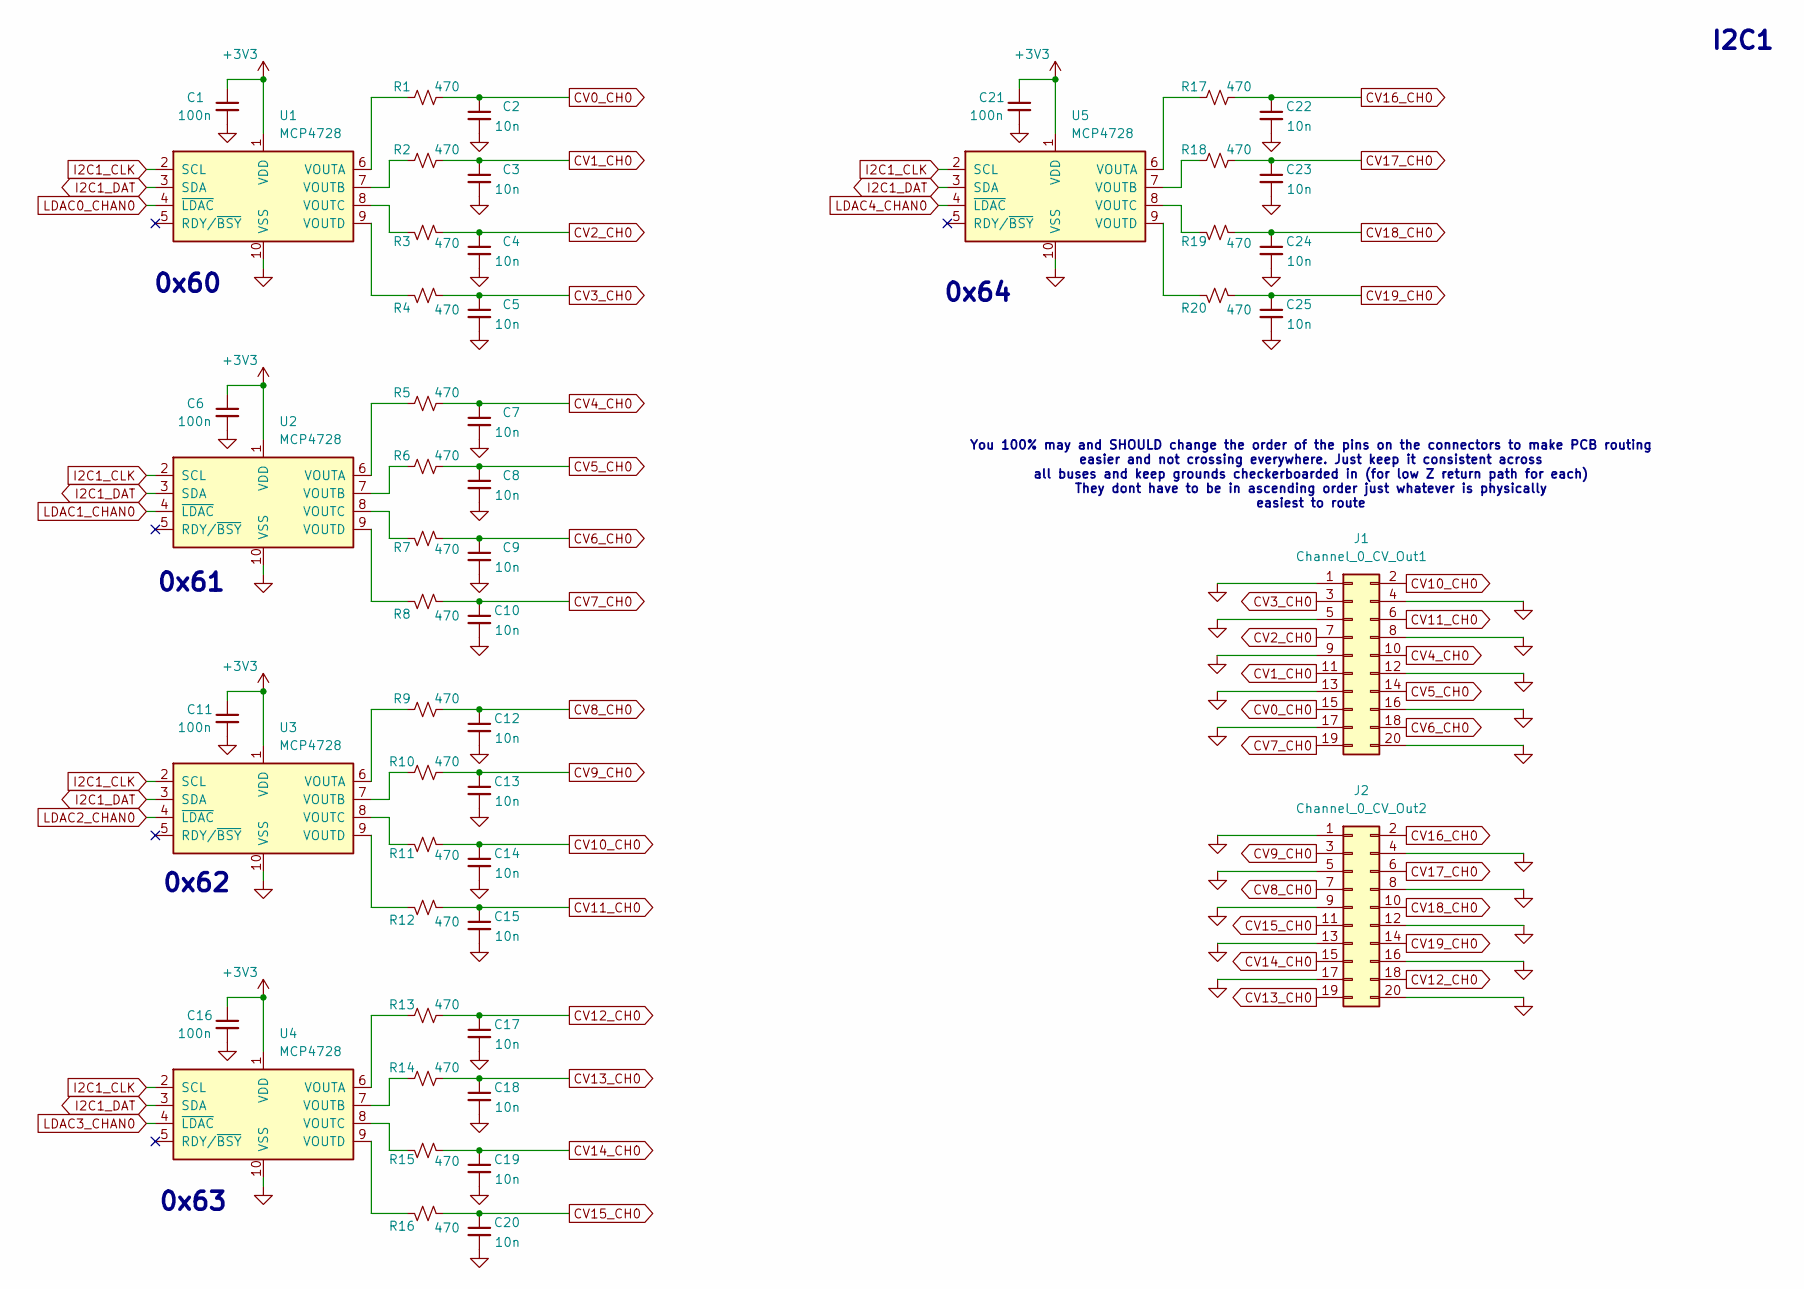
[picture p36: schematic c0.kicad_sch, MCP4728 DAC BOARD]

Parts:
C1, C6, C11, C16, C21: 100n; C_0402_1005Metric; LCSC C1525
C2, C3, C4, C5, C7, C8, C9, C10, C12, C13, C14, C15, C17, C18, C19, C20, C22, C23, C24, C25: 10n; C_0402_1005Metric; LCSC C1524
J1: Channel_0_CV_Out1; PinHeader_2x10_P1.27mm_Vertical
J2: Channel_0_CV_Out2; PinHeader_2x10_P1.27mm_Vertical
R1, R2, R3, R4, R5, R6, R7, R8, R9, R10, R11, R12, R13, R14, R15, R16, R17, R18, R19, R20: 470; R_0402_1005Metric; LCSC C25117
U1, U2, U3, U4, U5: MCP4728; MSOP-10_3x3mm_P0.5mm; LCSC C108207

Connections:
+3V3: C1.1, C6.1, C11.1, C16.1, C21.1, U1.1 (VDD), U2.1 (VDD), U3.1 (VDD), U4.1 (VDD), U5.1 (VDD); also elsewhere on the board
CV0_CH0: C2.1, J1.15, R1.2
CV1_CH0: C3.1, J1.11, R2.2
CV2_CH0: C4.1, J1.7, R3.2
CV3_CH0: C5.1, J1.3, R4.2
CV4_CH0: C7.1, J1.10, R5.2
CV5_CH0: C8.1, J1.14, R6.2
CV6_CH0: C9.1, J1.18, R7.2
CV7_CH0: C10.1, J1.19, R8.2
CV8_CH0: C12.1, J2.7, R9.2
CV9_CH0: C13.1, J2.3, R10.2
CV10_CH0: C14.1, J1.2, R11.2
CV11_CH0: C15.1, J1.6, R12.2
CV12_CH0: C17.1, J2.18, R13.2
CV13_CH0: C18.1, J2.19, R14.2
CV14_CH0: C19.1, J2.15, R15.2
CV15_CH0: C20.1, J2.11, R16.2
CV16_CH0: C22.1, J2.2, R17.2
CV17_CH0: C23.1, J2.6, R18.2
CV18_CH0: C24.1, J2.10, R19.2
CV19_CH0: C25.1, J2.14, R20.2
GND: C1.2, C2.2, C3.2, C4.2, C5.2, C6.2, C7.2, C8.2, C9.2, C10.2, C11.2, C12.2, C13.2, C14.2, C15.2, C16.2, C17.2, C18.2, C19.2, C20.2, C21.2, C22.2, C23.2, C24.2, C25.2, J1.1, J1.4, J1.5, J1.8, J1.9, J1.12, J1.13, J1.16, J1.17, J1.20, J2.1, J2.4, J2.5, J2.8, J2.9, J2.12, J2.13, J2.16, J2.17, J2.20, U1.10 (VSS), U2.10 (VSS), U3.10 (VSS), U4.10 (VSS), U5.10 (VSS); also elsewhere on the board
I2C1_CLK: U1.2 (SCL), U2.2 (SCL), U3.2 (SCL), U4.2 (SCL), U5.2 (SCL); also elsewhere on the board
I2C1_DAT: U1.3 (SDA), U2.3 (SDA), U3.3 (SDA), U4.3 (SDA), U5.3 (SDA); also elsewhere on the board
LDAC0_CHAN0: U1.4 (~LDAC); also elsewhere on the board
LDAC1_CHAN0: U2.4 (~LDAC); also elsewhere on the board
LDAC2_CHAN0: U3.4 (~LDAC); also elsewhere on the board
LDAC3_CHAN0: U4.4 (~LDAC); also elsewhere on the board
LDAC4_CHAN0: U5.4 (~LDAC); also elsewhere on the board
unnamed: R1.1, U1.6 (VOUTA)
unnamed: R2.1, U1.7 (VOUTB)
unnamed: R3.1, U1.8 (VOUTC)
unnamed: R4.1, U1.9 (VOUTD)
unnamed: R5.1, U2.6 (VOUTA)
unnamed: R6.1, U2.7 (VOUTB)
unnamed: R7.1, U2.8 (VOUTC)
unnamed: R8.1, U2.9 (VOUTD)
unnamed: R9.1, U3.6 (VOUTA)
unnamed: R10.1, U3.7 (VOUTB)
unnamed: R11.1, U3.8 (VOUTC)
unnamed: R12.1, U3.9 (VOUTD)
unnamed: R13.1, U4.6 (VOUTA)
unnamed: R14.1, U4.7 (VOUTB)
unnamed: R15.1, U4.8 (VOUTC)
unnamed: R16.1, U4.9 (VOUTD)
unnamed: R17.1, U5.6 (VOUTA)
unnamed: R18.1, U5.7 (VOUTB)
unnamed: R19.1, U5.8 (VOUTC)
unnamed: R20.1, U5.9 (VOUTD)

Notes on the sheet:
I2C1
You 100% may and SHOULD change the order of the pins on the connectors to make PCB routing easier and not crossing everywhere. Just keep it consistent across all buses and keep grounds checkerboarded in (for low Z return path for each) They dont have to be in ascending order just whatever is physic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
0x64
0x61
0x60
0x63
0x62

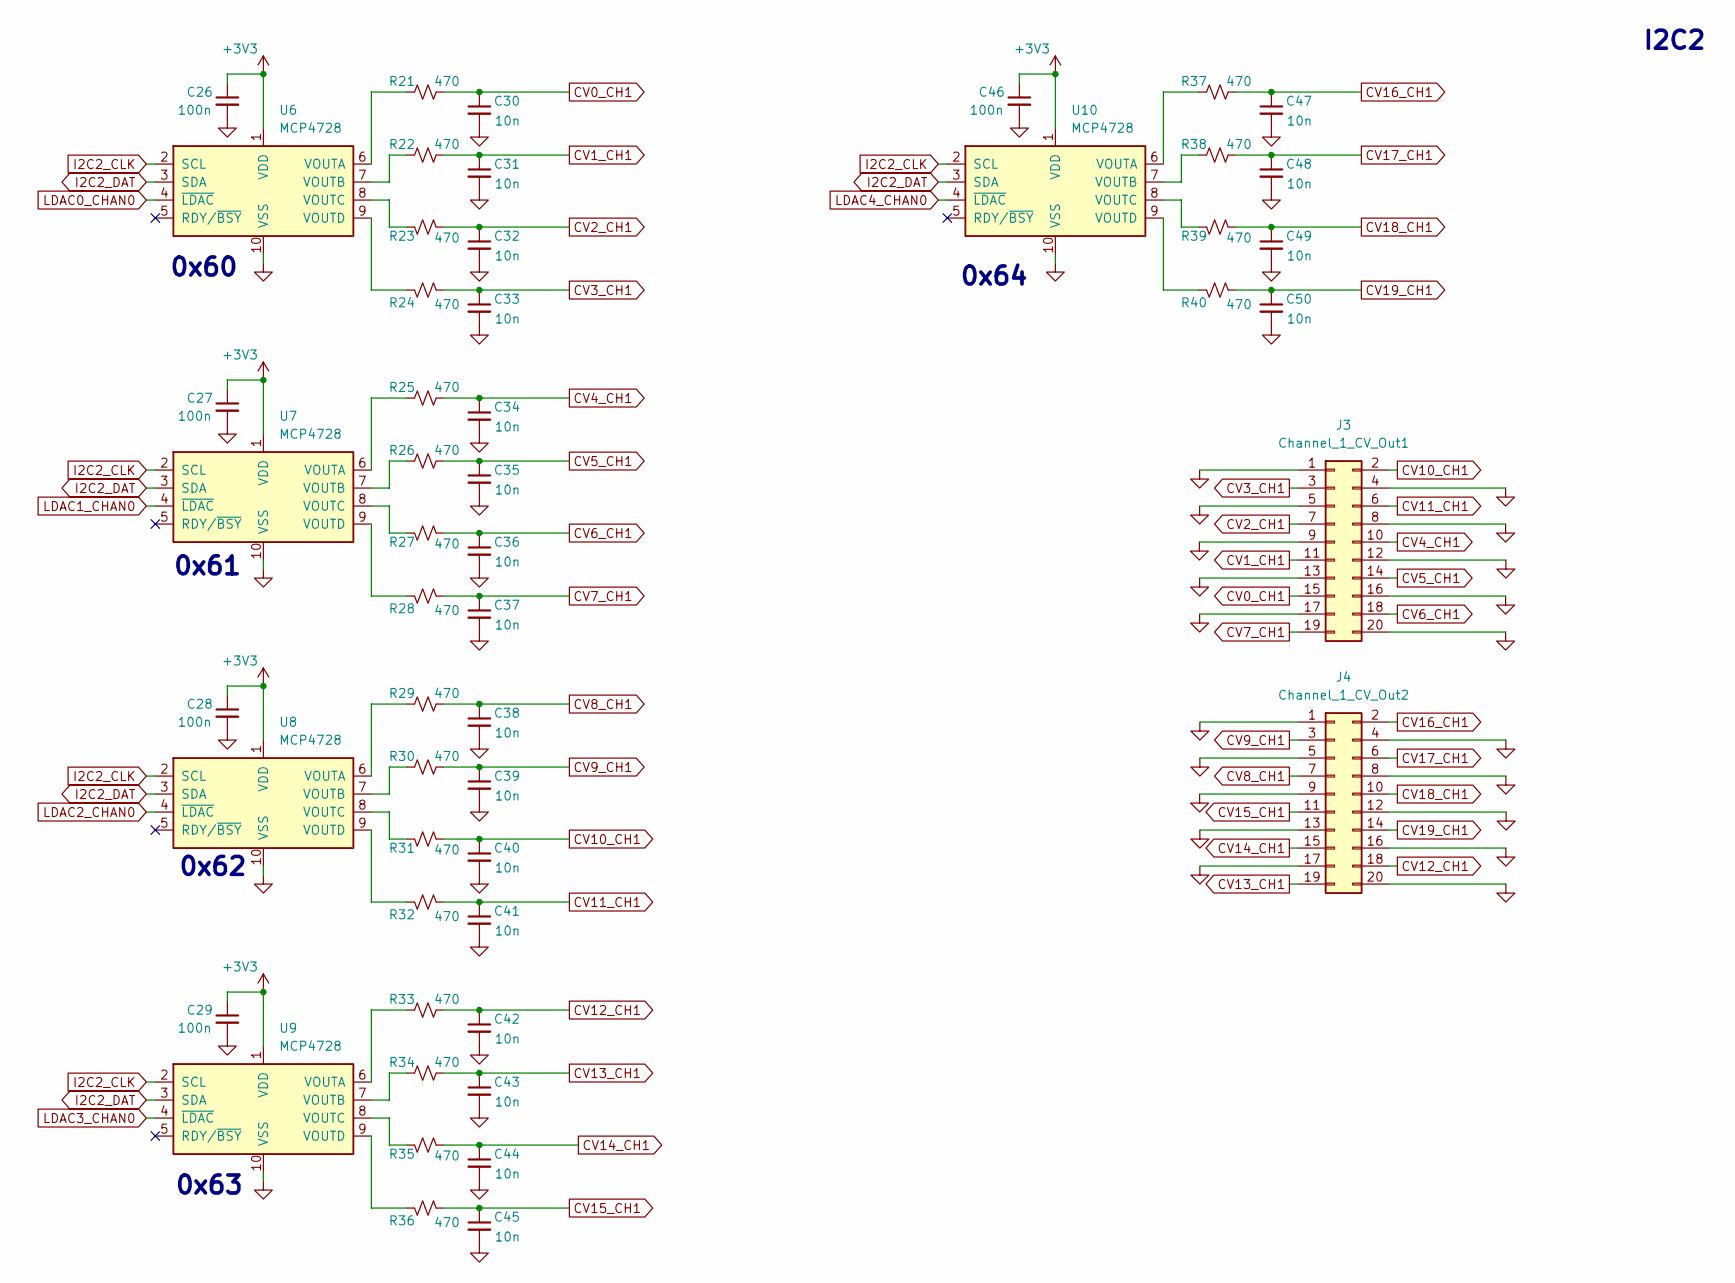
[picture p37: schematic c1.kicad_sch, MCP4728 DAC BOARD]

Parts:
C26, C27, C28, C29, C46: 100n; C_0402_1005Metric; LCSC C1525
C30, C31, C32, C33, C34, C35, C36, C37, C38, C39, C40, C41, C42, C43, C44, C45, C47, C48, C49, C50: 10n; C_0402_1005Metric; LCSC C1524
J3: Channel_1_CV_Out1; PinHeader_2x10_P1.27mm_Vertical
J4: Channel_1_CV_Out2; PinHeader_2x10_P1.27mm_Vertical
R21, R22, R23, R24, R25, R26, R27, R28, R29, R30, R31, R32, R33, R34, R35, R36, R37, R38, R39, R40: 470; R_0402_1005Metric; LCSC C25117
U6, U7, U8, U9, U10: MCP4728; MSOP-10_3x3mm_P0.5mm; LCSC C108207

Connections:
+3V3: C26.1, C27.1, C28.1, C29.1, C46.1, U6.1 (VDD), U7.1 (VDD), U8.1 (VDD), U9.1 (VDD), U10.1 (VDD); also elsewhere on the board
CV0_CH1: C30.1, J3.15, R21.2
CV1_CH1: C31.1, J3.11, R22.2
CV2_CH1: C32.1, J3.7, R23.2
CV3_CH1: C33.1, J3.3, R24.2
CV4_CH1: C34.1, J3.10, R25.2
CV5_CH1: C35.1, J3.14, R26.2
CV6_CH1: C36.1, J3.18, R27.2
CV7_CH1: C37.1, J3.19, R28.2
CV8_CH1: C38.1, J4.7, R29.2
CV9_CH1: C39.1, J4.3, R30.2
CV10_CH1: C40.1, J3.2, R31.2
CV11_CH1: C41.1, J3.6, R32.2
CV12_CH1: C42.1, J4.18, R33.2
CV13_CH1: C43.1, J4.19, R34.2
CV14_CH1: C44.1, J4.15, R35.2
CV15_CH1: C45.1, J4.11, R36.2
CV16_CH1: C47.1, J4.2, R37.2
CV17_CH1: C48.1, J4.6, R38.2
CV18_CH1: C49.1, J4.10, R39.2
CV19_CH1: C50.1, J4.14, R40.2
GND: C26.2, C27.2, C28.2, C29.2, C30.2, C31.2, C32.2, C33.2, C34.2, C35.2, C36.2, C37.2, C38.2, C39.2, C40.2, C41.2, C42.2, C43.2, C44.2, C45.2, C46.2, C47.2, C48.2, C49.2, C50.2, J3.1, J3.4, J3.5, J3.8, J3.9, J3.12, J3.13, J3.16, J3.17, J3.20, J4.1, J4.4, J4.5, J4.8, J4.9, J4.12, J4.13, J4.16, J4.17, J4.20, U6.10 (VSS), U7.10 (VSS), U8.10 (VSS), U9.10 (VSS), U10.10 (VSS); also elsewhere on the board
I2C2_CLK: U6.2 (SCL), U7.2 (SCL), U8.2 (SCL), U9.2 (SCL), U10.2 (SCL); also elsewhere on the board
I2C2_DAT: U6.3 (SDA), U7.3 (SDA), U8.3 (SDA), U9.3 (SDA), U10.3 (SDA); also elsewhere on the board
LDAC0_CHAN0: U6.4 (~LDAC); also elsewhere on the board
LDAC1_CHAN0: U7.4 (~LDAC); also elsewhere on the board
LDAC2_CHAN0: U8.4 (~LDAC); also elsewhere on the board
LDAC3_CHAN0: U9.4 (~LDAC); also elsewhere on the board
LDAC4_CHAN0: U10.4 (~LDAC); also elsewhere on the board
unnamed: R21.1, U6.6 (VOUTA)
unnamed: R22.1, U6.7 (VOUTB)
unnamed: R23.1, U6.8 (VOUTC)
unnamed: R24.1, U6.9 (VOUTD)
unnamed: R25.1, U7.6 (VOUTA)
unnamed: R26.1, U7.7 (VOUTB)
unnamed: R27.1, U7.8 (VOUTC)
unnamed: R28.1, U7.9 (VOUTD)
unnamed: R29.1, U8.6 (VOUTA)
unnamed: R30.1, U8.7 (VOUTB)
unnamed: R31.1, U8.8 (VOUTC)
unnamed: R32.1, U8.9 (VOUTD)
unnamed: R33.1, U9.6 (VOUTA)
unnamed: R34.1, U9.7 (VOUTB)
unnamed: R35.1, U9.8 (VOUTC)
unnamed: R36.1, U9.9 (VOUTD)
unnamed: R37.1, U10.6 (VOUTA)
unnamed: R38.1, U10.7 (VOUTB)
unnamed: R39.1, U10.8 (VOUTC)
unnamed: R40.1, U10.9 (VOUTD)

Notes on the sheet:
0x63
0x64
0x61
0x62
I2C2
0x60

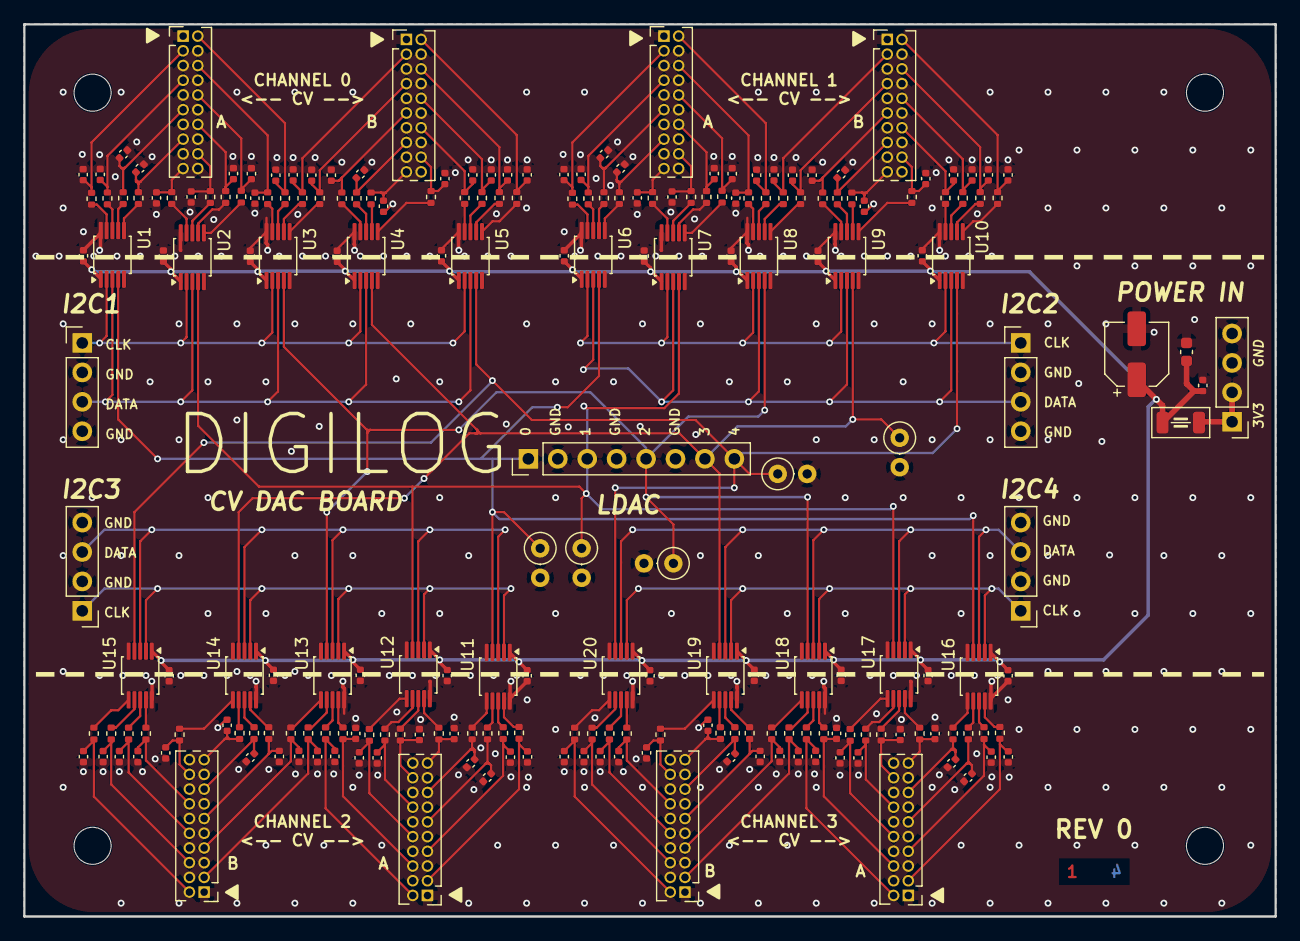
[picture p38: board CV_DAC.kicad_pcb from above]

Board: 4 copper layers, 108.0 x 77.0 mm, 227 parts (0 on the bottom side), 176 nets.

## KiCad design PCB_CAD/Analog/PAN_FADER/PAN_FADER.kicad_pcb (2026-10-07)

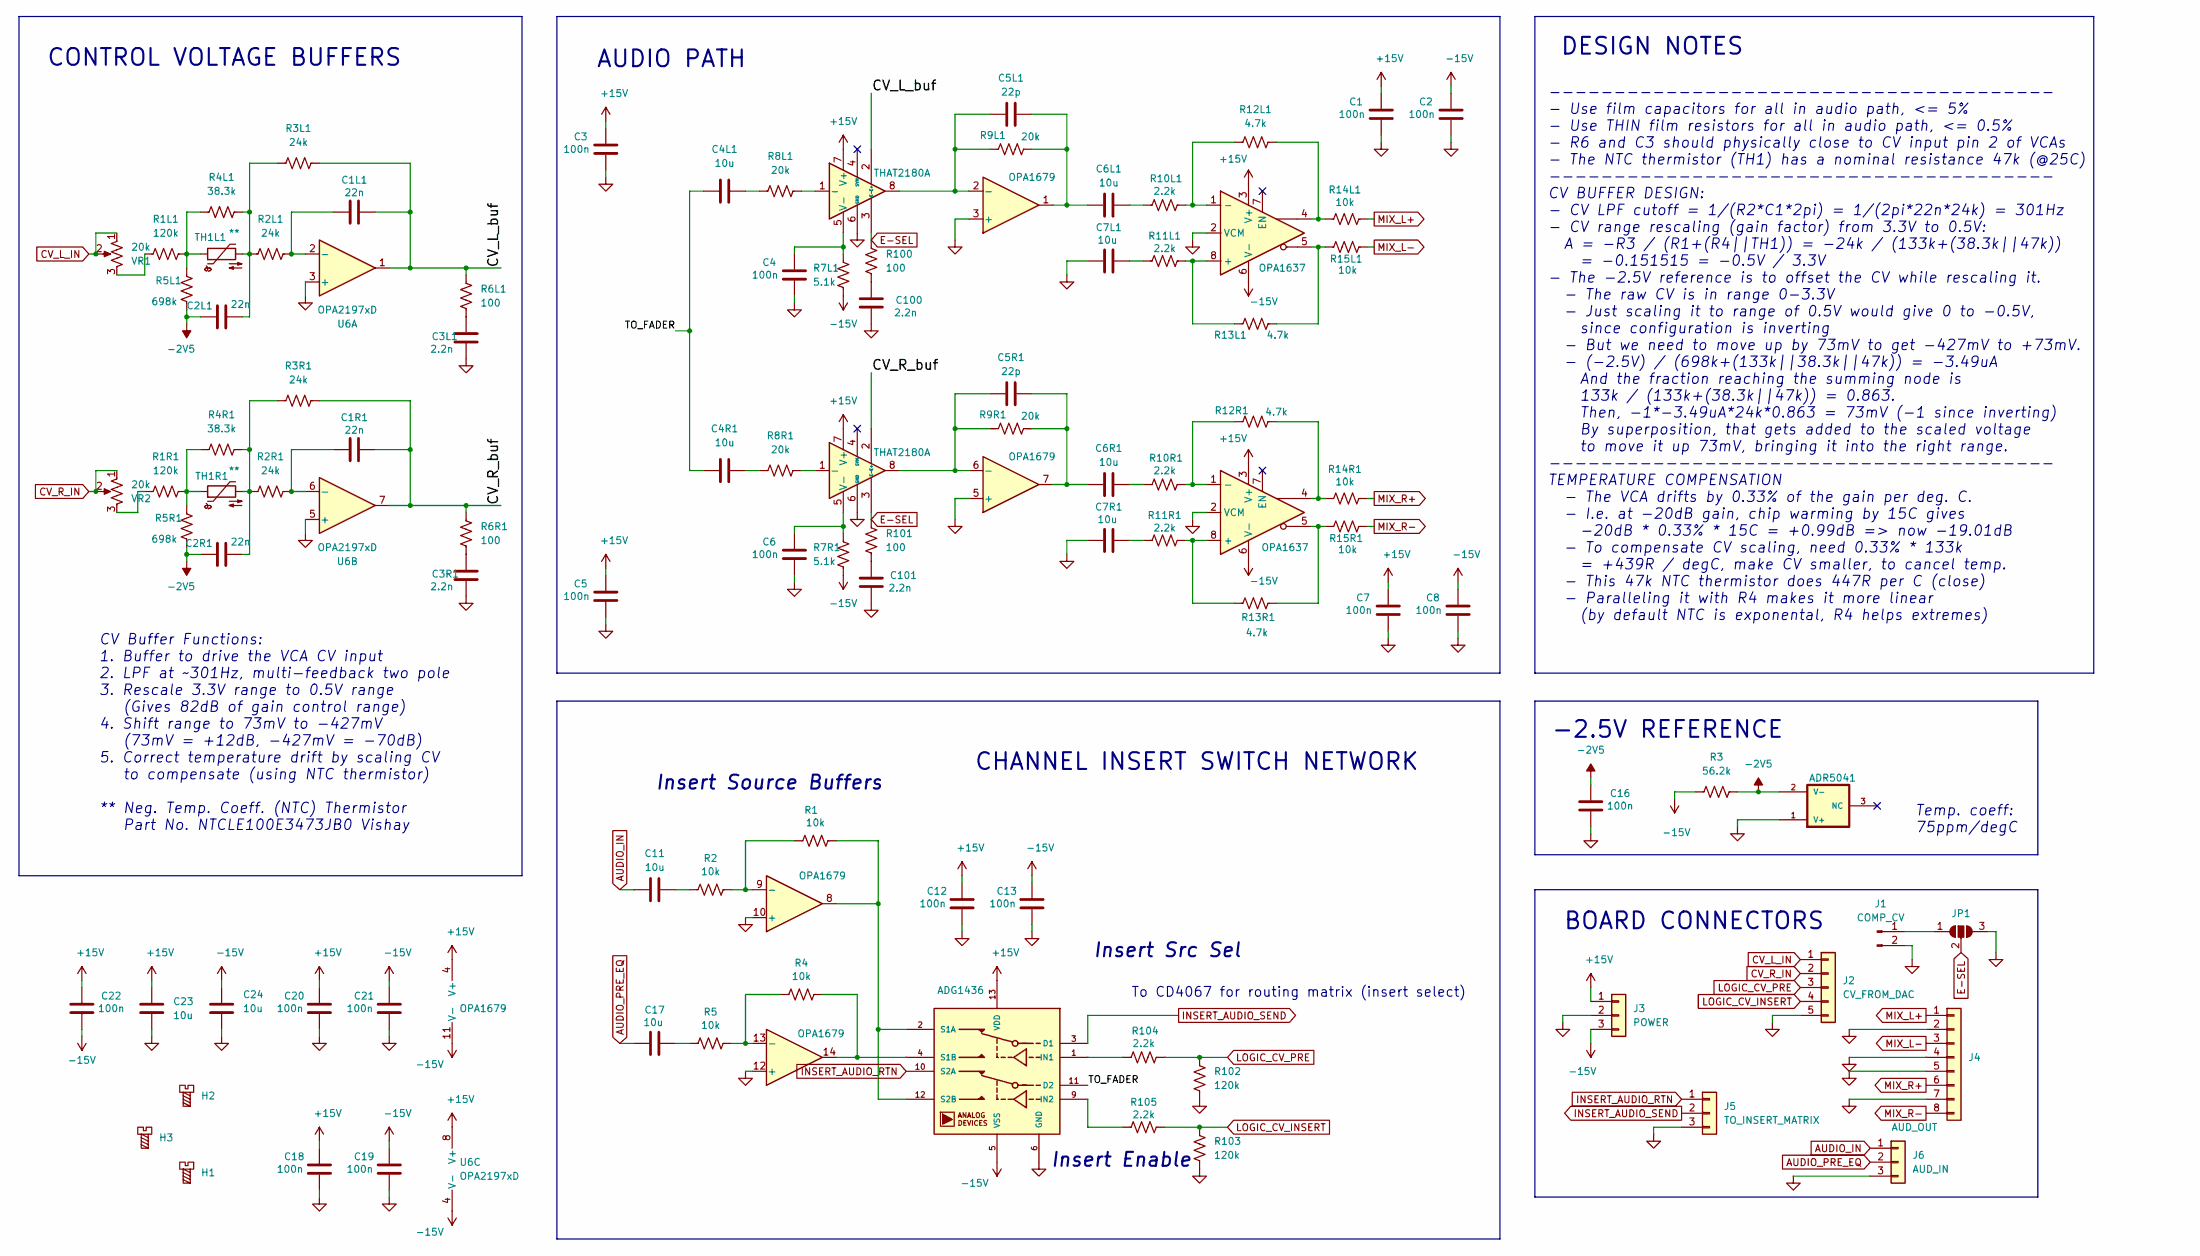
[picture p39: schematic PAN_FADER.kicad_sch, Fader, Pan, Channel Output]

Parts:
C1, C2, C3, C4, C5, C6, C7, C8, C12, C13, C16, C18, C19, C20, C21, C22: 100n; C_0603_1608Metric; LCSC C1591
C1L1, C1R1, C2L1, C2R1: 22n; C_Rect_L7.2mm_W2.5mm_P5.00mm; LCSC DNP
C3L1, C3R1, C100, C101: 2.2n; C_0805_2012Metric; LCSC C107103
C4L1, C4R1, C6L1, C6R1, C7L1, C7R1, C11, C17: 10u; CP_Elec_6.3x5.4_Nichicon; LCSC C340735
C5L1, C5R1: 22p; C_0603_1608Metric; LCSC C105620
C23, C24: 10u; C_1206_3216Metric; LCSC C9807
H1, H2, H3: MountingHole_Pad; MountingHole_2.2mm_M2
J1: COMP_CV; PinHeader_1x02_P2.54mm_Vertical; LCSC DNP
J2: CV_FROM_DAC; PinHeader_1x05_P2.54mm_Vertical; Part Number 1-0301FBV0T; LCSC DNP
J3: POWER; PinHeader_1x03_P2.54mm_Vertical; Part Number 1-0301FBV0T; LCSC DNP
J4: AUD_OUT; PinHeader_1x08_P2.54mm_Vertical; Part Number 1-0301FBV0T; LCSC DNP
J5: TO_INSERT_MATRIX; PinHeader_1x03_P2.54mm_Vertical; Part Number 1-0301FBV0T; LCSC DNP
J6: AUD_IN; PinHeader_1x03_P2.54mm_Vertical; Part Number 1-0301FBV0T; LCSC DNP
JP1: SolderJumper_3_Open; SolderJumper-3_P2.0mm_Open_TrianglePad1.0x1.5mm; LCSC DNP
R1, R2, R4, R5, R14L1, R14R1, R15L1, R15R1: 10k; R_0603_1608Metric; LCSC C95204
R1L1, R1R1, R102, R103: 120k; R_0402_1005Metric; LCSC C517522
R2L1, R2R1, R3L1, R3R1: 24k; R_0603_1608Metric; LCSC C319717
R3: 56.2k; R_0402_1005Metric; LCSC C705626
R4L1, R4R1: 38.3k; R_0603_1608Metric; LCSC C861362
R5L1, R5R1: 698k; R_0805_2012Metric; LCSC C865618
R6L1, R6R1, R100, R101: 100; R_0603_1608Metric; LCSC C22775
R7L1, R7R1: 5.1k; R_0603_1608Metric; LCSC C122969
R8L1, R8R1, R9L1, R9R1: 20k; R_0603_1608Metric; LCSC C154077
R10L1, R10R1, R11L1, R11R1, R104, R105: 2.2k; R_0402_1005Metric; LCSC C326602
R12L1, R12R1, R13L1, R13R1: 4.7k; R_0402_1005Metric; LCSC C281778
TH1L1, TH1R1: **; R_Axial_DIN0207_L6.3mm_D2.5mm_P2.54mm_Vertical; LCSC DNP
U1, U5: THAT2180A; SIP-8_19x3mm_P2.54mm; LCSC DNP
U2: OPA1679; SOIC-14_3.9x8.65mm_Pitch1.27mm; LCSC C2878631
U3, U7: OPA1637; Texas_S-PDSO-G8_3x3mm_P0.65mm; LCSC C2860968
U6: OPA2197xD; SOIC-8_3.9x4.9mm_P1.27mm; LCSC C139363
U8: ADR5041; SOT-23-3; MPN ADR5041ARTZ-R2; LCSC C659596
U9: ADG1436; TSSOP-16_4.4x5mm_P0.65mm; LCSC C408899
VR1, VR2: 20k; Potentiometer_Bourns_3314J_Vertical; LCSC C55069

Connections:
+15V: C1.2, C3.2, C5.2, C7.2, C12.2, C18.2, C20.2, C22.2, C23.1, J3.1, U1.7 (V+), U2.4 (V+), U3.3 (V+), U5.7 (V+), U6.8 (V+), U7.3 (V+), U9.13 (VDD)
-2V5: C2L1.1, C2R1.1, C16.2, R3.2, R5L1.1, R5R1.1, U8.2 (V-)
-15V: C2.2, C8.2, C13.2, C19.2, C21.2, C22.1, C24.2, J3.3, R3.1, R7L1.1, R7R1.1, U2.11 (V-), U3.6 (V-), U6.4 (V-), U7.6 (V-), U9.5 (VSS)
/CV_L_buf: C1L1.2, R3L1.2, R6L1.2, U1.2 (E+), U6.1
/CV_R_buf: C1R1.2, R3R1.2, R6R1.2, U5.2 (E+), U6.7
/TO_FADER: C4L1.1, C4R1.1, U9.11 (D2)
AUDIO_IN: C11.1, J6.1
AUDIO_PRE_EQ: C17.1, J6.2
CV_L_IN: J2.1, VR1.1, VR1.2
CV_R_IN: J2.2, VR2.1, VR2.2
E-SEL: JP1.2 (C), R100.2, R101.2, U1.3 (E-), U5.3 (E-)
GND: C1.1, C2.1, C3.1, C3L1.1, C3R1.1, C4.1, C5.1, C6.1, C7.1, C7L1.1, C7R1.1, C8.1, C12.1, C13.1, C16.1, C18.1, C19.1, C20.1, C21.1, C23.2, C24.1, C100.1, C101.1, J1.2, J2.5, J3.2, J4.2, J4.4, J4.5, J4.7, J5.3, J6.3, JP1.3 (B), R102.1, R103.1, U1.6 (GND), U2.3 (+), U2.5 (+), U2.10 (+), U2.12 (+), U3.2 (VCM), U5.6 (GND), U6.3 (+), U6.5 (+), U7.2 (VCM), U8.1 (V+), U9.6 (GND)
INSERT_AUDIO_RTN: J5.1, U9.10 (S2A)
INSERT_AUDIO_SEND: J5.2, U9.3 (D1)
LOGIC_CV_INSERT: J2.4, R103.2, R105.2
LOGIC_CV_PRE: J2.3, R102.2, R104.2
MIX_L+: J4.1, R14L1.2
MIX_L-: J4.3, R15L1.2
MIX_R+: J4.6, R14R1.2
MIX_R-: J4.8, R15R1.2
unnamed: C2L1.2, R2L1.1, R3L1.1, R4L1.2, TH1L1.2
unnamed: C2R1.2, R2R1.1, R3R1.1, R4R1.2, TH1R1.2
unnamed: C3L1.2, R6L1.1
unnamed: C3R1.2, R6R1.1
unnamed: C4L1.2, R8L1.1
unnamed: C4R1.2, R8R1.1
unnamed: C5L1.2, C6L1.1, R9L1.2, U2.1
unnamed: C5R1.2, C6R1.1, R9R1.2, U2.7
unnamed: C6L1.2, R10L1.1
unnamed: C6R1.2, R10R1.1
unnamed: C7L1.2, R11L1.1
unnamed: C7R1.2, R11R1.1
unnamed: C11.2, R2.2
unnamed: C17.2, R5.2
unnamed: C100.2, R100.1
unnamed: C101.2, R101.1
unnamed: J1.1, JP1.1 (A)
unnamed: R1L1.1, VR1.3
unnamed: R1L1.2, R4L1.1, R5L1.2, TH1L1.1
unnamed: R1R1.1, VR2.3
unnamed: R1R1.2, R4R1.1, R5R1.2, TH1R1.1
unnamed: R12L1.2, R14L1.1, U3.4
unnamed: R12R1.2, R14R1.1, U7.4
unnamed: R13L1.2, R15L1.1, U3.5
unnamed: R13R1.2, R15R1.1, U7.5
unnamed: R8L1.2, U1.1 (-)
unnamed: C4.2, R7L1.2, U1.5 (V-)
unnamed: C5L1.1, R9L1.1, U1.8, U2.2 (-)
unnamed: C5R1.1, R9R1.1, U2.6 (-), U5.8
unnamed: R1.2, R2.1, U2.9 (-)
unnamed: R4.2, R5.1, U2.13 (-)
unnamed: R11L1.2, R13L1.1, U3.8 (+)
unnamed: R10L1.2, R12L1.1, U3.1 (-)
unnamed: R8R1.2, U5.1 (-)
unnamed: C6.2, R7R1.2, U5.5 (V-)
unnamed: C1L1.1, R2L1.2, U6.2 (-)
unnamed: C1R1.1, R2R1.2, U6.6 (-)
unnamed: R11R1.2, R13R1.1, U7.8 (+)
unnamed: R10R1.2, R12R1.1, U7.1 (-)
unnamed: R104.1, U9.1 (IN1)
unnamed: R105.1, U9.9 (IN2)
unnamed: R1.1, U2.8, U9.2 (S1A), U9.12 (S2B)
unnamed: R4.1, U2.14, U9.4 (S1B)

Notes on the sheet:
CONTROL VOLTAGE BUFFERS
--------------------------------------- - Use film capacitors for all in audio path, <= 5% - Use THIN film resistors for all in audio path, <= 0.5% - R6 and C3 should physically close to CV input pin 2 of VCAs - The NTC thermistor (TH1) has a nominal resistance 47k (@25C) --------------------------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
BOARD CONNECTORS
CV Buffer Functions: 1. Buffer to drive the VCA CV input 2. LPF at ~301Hz, multi-feedback two pole 3. Rescale 3.3V range to 0.5V range (Gives 82dB of gain control range) 4. Shift range to 73mV to -427mV (73mV = +12dB, -427mV = -70dB) 5. Correct temperature drift by scaling CV to compensate (using N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
Insert Source Buffers
Insert Enable
AUDIO PATH
Insert Src Sel
-2.5V REFERENCE
CHANNEL INSERT SWITCH NETWORK
Temp. coeff: 75ppm/degC
DESIGN NOTES
To CD4067 for routing matrix (insert select)

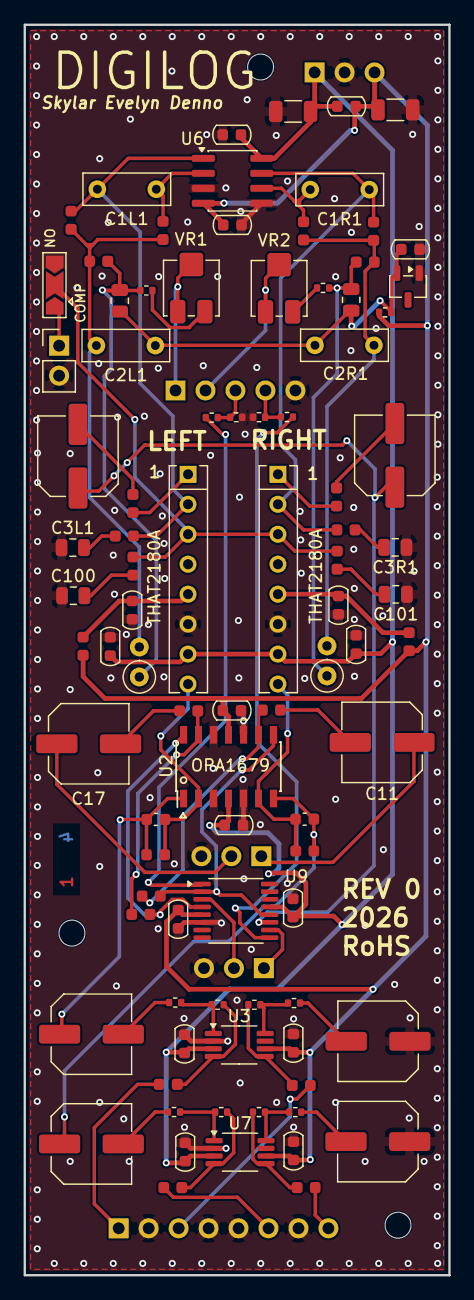
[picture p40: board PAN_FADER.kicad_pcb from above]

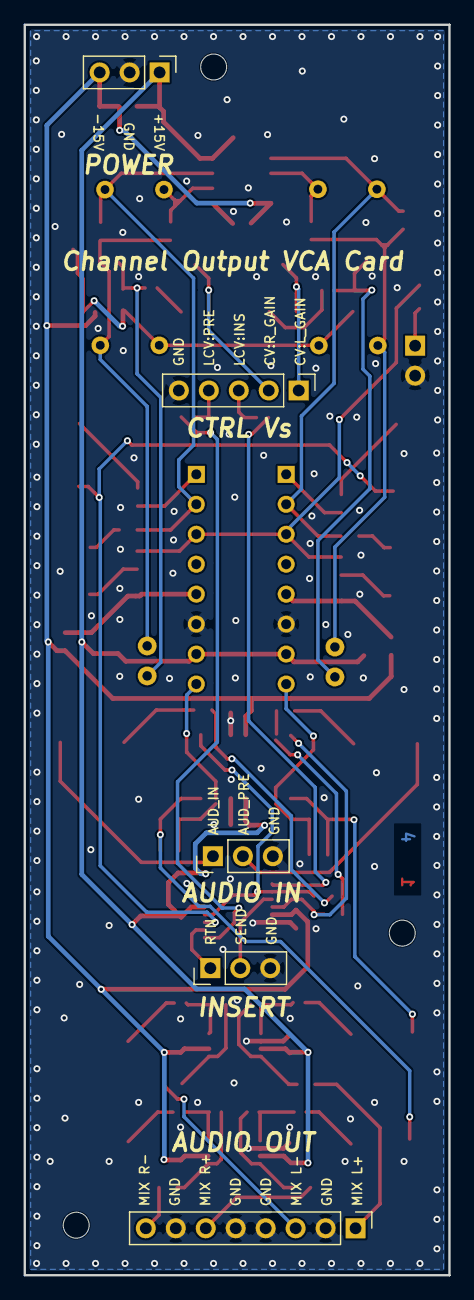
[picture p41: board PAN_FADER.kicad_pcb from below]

Board: 4 copper layers, 36.0 x 106.0 mm, 99 parts (5 on the bottom side), 63 nets.

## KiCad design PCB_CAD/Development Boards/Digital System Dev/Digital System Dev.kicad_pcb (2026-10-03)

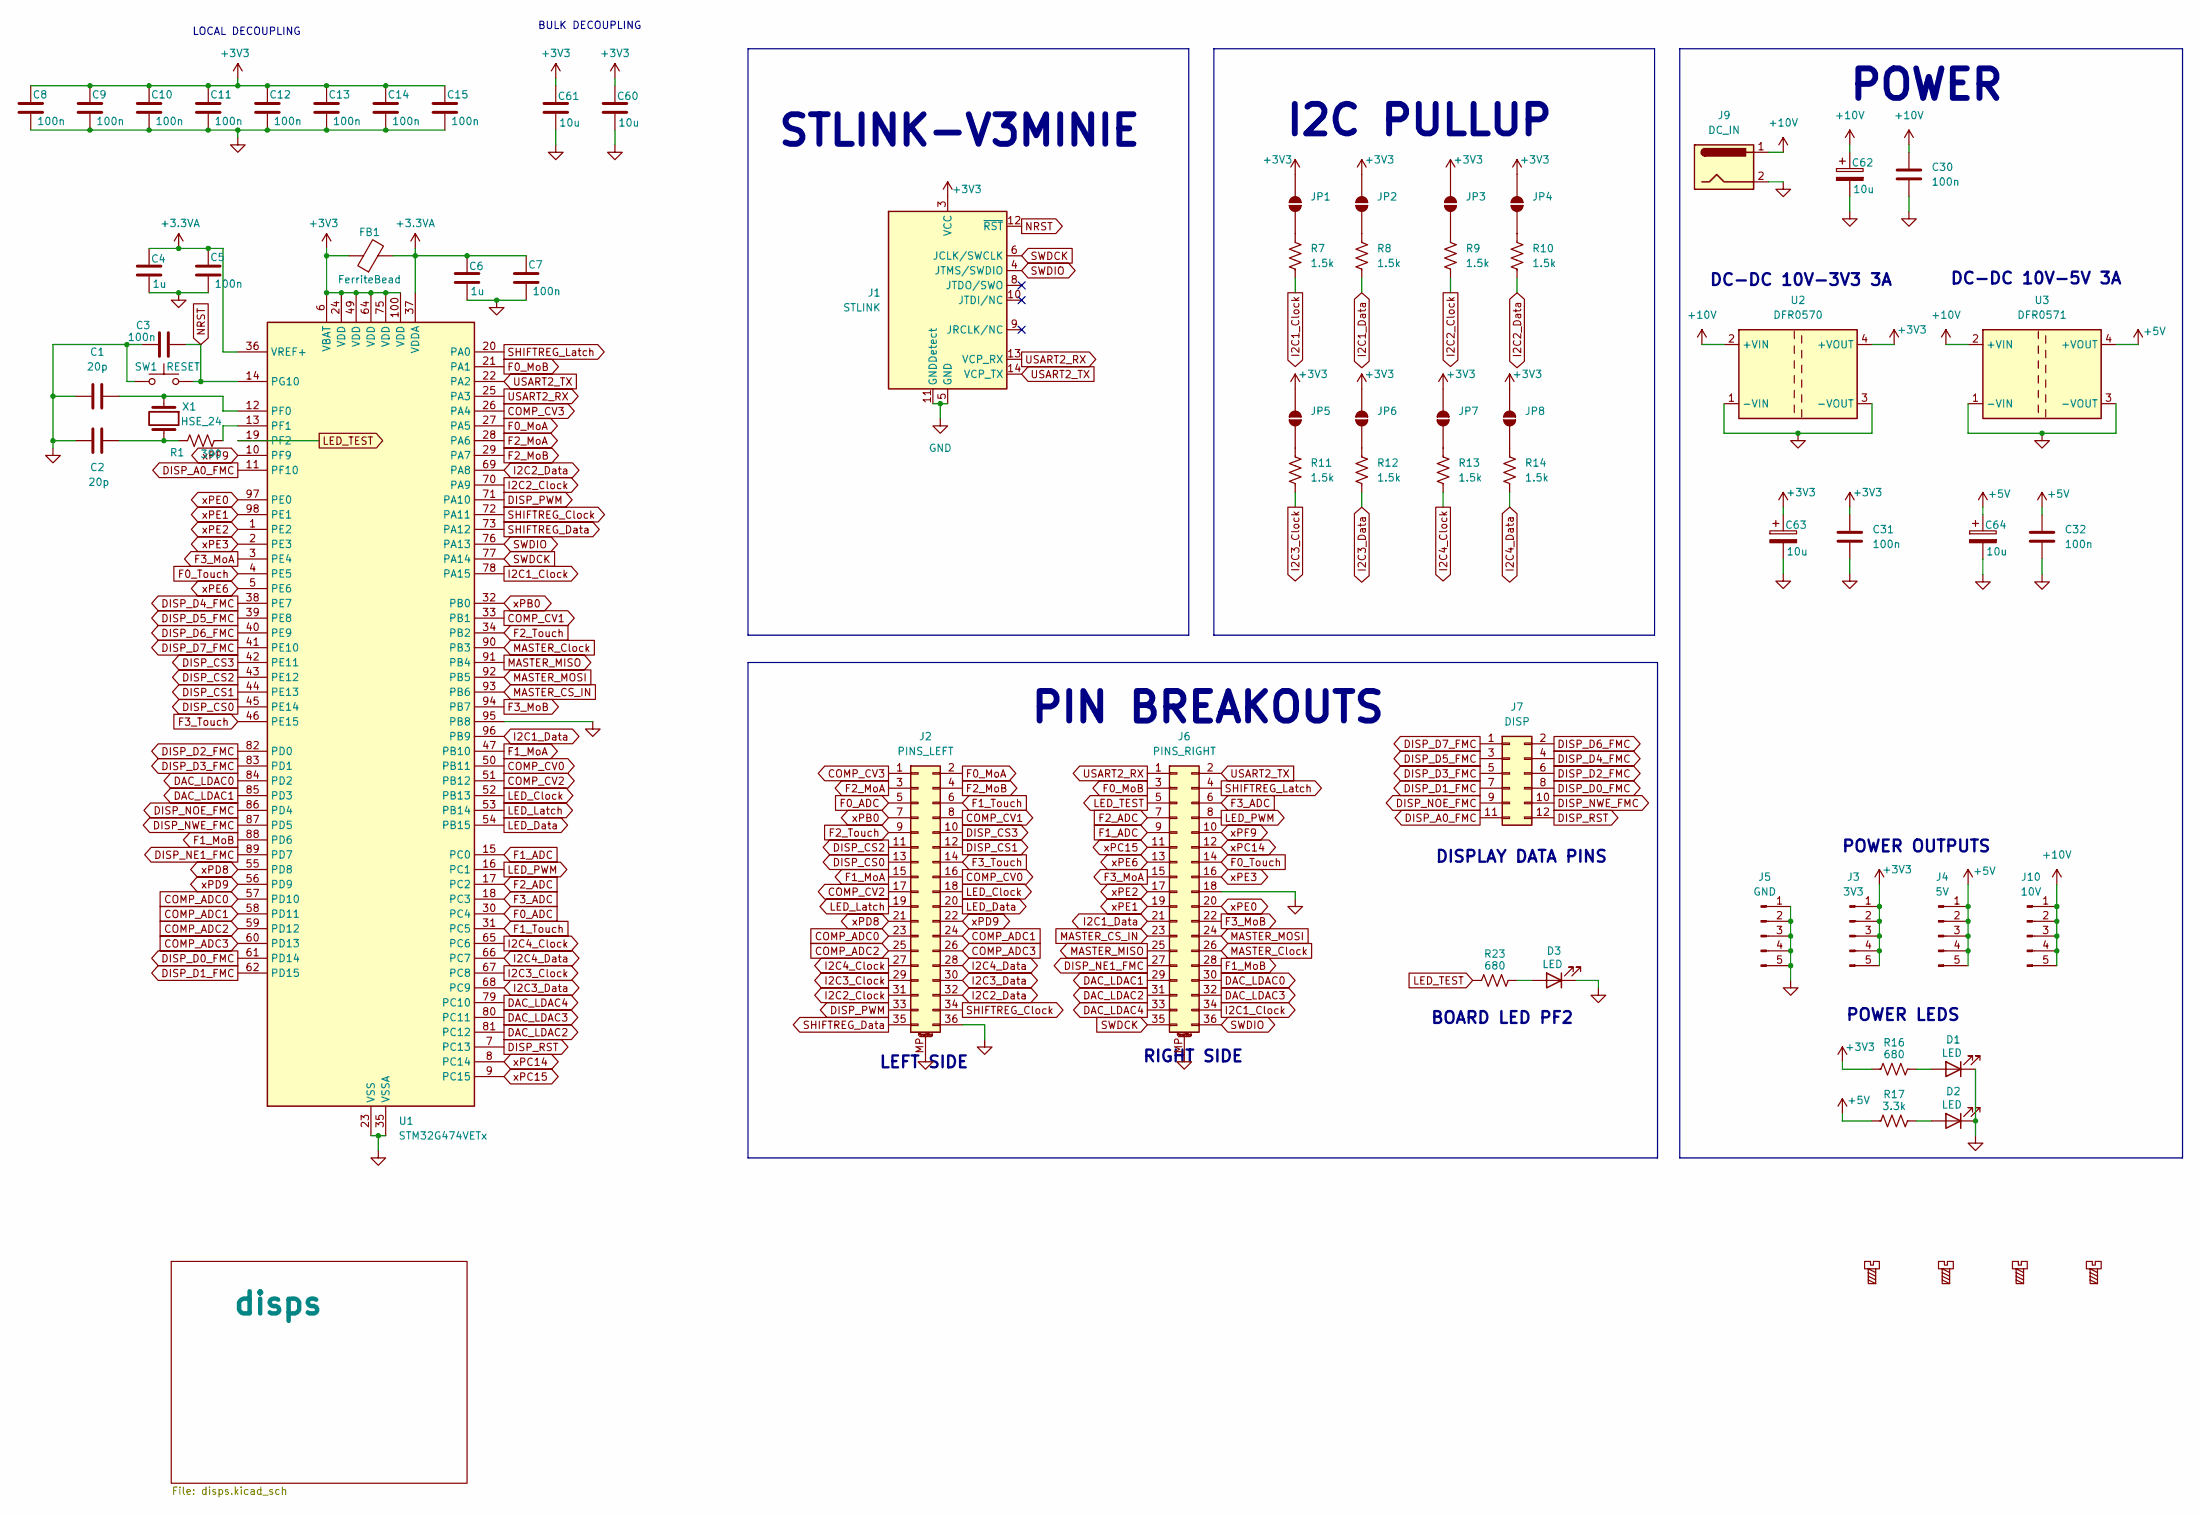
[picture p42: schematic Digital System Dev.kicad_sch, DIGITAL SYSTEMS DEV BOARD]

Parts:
C1, C2: 20p; C_0603_1608Metric; LCSC C1648
C3, C5, C7, C8, C9, C10, C11, C12, C13, C14, C15, C30, C31, C32: 100n; C_0603_1608Metric; LCSC C1590
C4, C6: 1u; C_0603_1608Metric; LCSC C1592
C60, C61: 10u; C_1206_3216Metric; LCSC C1849
C62, C63, C64: 10u; CP_Elec_6.3x5.8; LCSC C48970664
D1, D2, D3: LED; LED_0603_1608Metric; LCSC C12065
FB1: FerriteBead; Ferrite_0603_1608Metric; LCSC C1002
H1, H2, H3, H4: MountingScrew; MountingHole_3.2mm_M3; LCSC DNP
J1: STLINK; FTSH-107-01-L-DV-K-TR; LCSC C5307809
J2: PINS_LEFT; PinHeader_3x18_P2.54mm_Vertical_GND; LCSC DNP
J3: 3V3; PinSocket_1x05_P2.54mm_Vertical; LCSC DNP
J4: 5V; PinSocket_1x05_P2.54mm_Vertical; LCSC DNP
J5: GND; PinSocket_1x05_P2.54mm_Vertical; LCSC DNP
J6: PINS_RIGHT; PinHeader_3x18_P2.54mm_Vertical_GND; LCSC DNP
J7: DISP; PinHeader_2x06_P2.54mm_Vertical; LCSC DNP
J9: DC_IN; BarrelJack_Horizontal; LCSC DNP
J10: 10V; PinSocket_1x05_P2.54mm_Vertical; LCSC DNP
JP1, JP2, JP3, JP4, JP5, JP6, JP7, JP8: SolderJumper_2_Open; SolderJumper-2_P1.3mm_Open_TrianglePad1.0x1.5mm; LCSC DNP
R1: 390; R_1206_3216Metric; LCSC C4491
R7, R8, R9, R10, R11, R12, R13, R14: 1.5k; R_0603_1608Metric; LCSC C22843
R16, R23: 680; R_0603_1608Metric; LCSC C23228
R17: 3.3k; R_0603_1608Metric; LCSC C22978
SW1: RESET; SW_Push_1P1T_NO_CK_KMR2; LCSC C72443
U1: STM32G474VETx; LQFP-100_14x14mm_P0.5mm; LCSC C2970837
U2: DFR0570; DFR05xx_DC-DC; LCSC DNP
U3: DFR0571; DFR05xx_DC-DC; LCSC DNP
X1: HSE_24; Crystal_SMD_HC49-SD; LCSC C2253

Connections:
+3.3VA: C4.1, C5.1, C6.1, C7.1, FB1.2, U1.36 (VREF+), U1.37 (VDDA)
+3V3: C8.1, C9.1, C10.1, C11.1, C12.1, C13.1, C14.1, C15.1, C31.1, C60.1, C61.1, C63.1, FB1.1, J1.3 (VCC), J3.1, J3.2, J3.3, J3.4, J3.5, JP1.2 (B), JP2.2 (B), JP3.2 (B), JP4.2 (B), JP5.2 (B), JP6.2 (B), JP7.2 (B), JP8.2 (B), R16.1, U1.6 (VBAT), U1.24 (VDD), U1.49 (VDD), U1.64 (VDD), U1.75 (VDD), U1.100 (VDD), U2.4 (+VOUT); also elsewhere on the board
+5V: C32.1, C64.1, J4.1, J4.2, J4.3, J4.4, J4.5, R17.1, U3.4 (+VOUT); also elsewhere on the board
+10V: C30.1, C62.1, J9.1, J10.1, J10.2, J10.3, J10.4, J10.5, U2.2 (+VIN), U3.2 (+VIN)
COMP_ADC0: J2.23, U1.57 (PD10)
COMP_ADC1: J2.24, U1.58 (PD11)
COMP_ADC2: J2.25, U1.59 (PD12)
COMP_ADC3: J2.26, U1.60 (PD13)
COMP_CV0: J2.16, U1.50 (PB11)
COMP_CV1: J2.8, U1.33 (PB1)
COMP_CV2: J2.17, U1.51 (PB12)
COMP_CV3: J2.1, U1.26 (PA4)
DAC_LDAC0: J6.30, U1.84 (PD2)
DAC_LDAC1: J6.29, U1.85 (PD3)
DAC_LDAC2: J6.31, U1.81 (PC12)
DAC_LDAC3: J6.32, U1.80 (PC11)
DAC_LDAC4: J6.33, U1.79 (PC10)
DISP_A0_FMC: J7.11, U1.11 (PF10); also elsewhere on the board
DISP_CS0: J2.13, U1.45 (PE14); also elsewhere on the board
DISP_CS1: J2.12, U1.44 (PE13); also elsewhere on the board
DISP_CS2: J2.11, U1.43 (PE12); also elsewhere on the board
DISP_CS3: J2.10, U1.42 (PE11); also elsewhere on the board
DISP_D0_FMC: J7.8, U1.61 (PD14); also elsewhere on the board
DISP_D1_FMC: J7.7, U1.62 (PD15); also elsewhere on the board
DISP_D2_FMC: J7.6, U1.82 (PD0); also elsewhere on the board
DISP_D3_FMC: J7.5, U1.83 (PD1); also elsewhere on the board
DISP_D4_FMC: J7.4, U1.38 (PE7); also elsewhere on the board
DISP_D5_FMC: J7.3, U1.39 (PE8); also elsewhere on the board
DISP_D6_FMC: J7.2, U1.40 (PE9); also elsewhere on the board
DISP_D7_FMC: J7.1, U1.41 (PE10); also elsewhere on the board
DISP_NE1_FMC: J6.27, U1.89 (PD7)
DISP_NOE_FMC: J7.9, U1.86 (PD4); also elsewhere on the board
DISP_NWE_FMC: J7.10, U1.87 (PD5); also elsewhere on the board
DISP_PWM: J2.33, U1.71 (PA10); also elsewhere on the board
DISP_RST: J7.12, U1.7 (PC13); also elsewhere on the board
F0_ADC: J2.5, U1.30 (PC4)
F0_MoA: J2.2, U1.27 (PA5)
F0_MoB: J6.3, U1.21 (PA1)
F0_Touch: J6.14, U1.4 (PE5)
F1_ADC: J6.9, U1.15 (PC0)
F1_MoA: J2.15, U1.47 (PB10)
F1_MoB: J6.28, U1.88 (PD6)
F1_Touch: J2.6, U1.31 (PC5)
F2_ADC: J6.7, U1.17 (PC2)
F2_MoA: J2.3, U1.28 (PA6)
F2_MoB: J2.4, U1.29 (PA7)
F2_Touch: J2.9, U1.34 (PB2)
F3_ADC: J6.6, U1.18 (PC3)
F3_MoA: J6.15, U1.3 (PE4)
F3_MoB: J6.22, U1.94 (PB7)
F3_Touch: J2.14, U1.46 (PE15)
GND: C1.2, C2.1, C3.1, C4.2, C5.2, C6.2, C7.2, C8.2, C9.2, C10.2, C11.2, C12.2, C13.2, C14.2, C15.2, C30.2, C31.2, C32.2, C60.2, C61.2, C62.2, C63.2, C64.2, D1.1 (K), D2.1 (K), D3.1 (K), J1.5 (GND), J1.7 (GND), J1.11 (GNDDetect), J2.36, J2.MP (MountPin), J5.1, J5.2, J5.3, J5.4, J5.5, J6.18, J6.MP (MountPin), J9.2, SW1.1, U1.23 (VSS), U1.35 (VSSA), U1.48 (VSS), U1.63 (VSS), U1.74 (VSS), U1.95 (PB8), U1.99 (VSS), U2.1 (-VIN), U2.3 (-VOUT), U3.1 (-VIN), U3.3 (-VOUT); also elsewhere on the board
I2C1_Clock: J6.34, R7.2, U1.78 (PA15)
I2C1_Data: J6.21, R8.2, U1.96 (PB9)
I2C2_Clock: J2.31, R9.2, U1.70 (PA9)
I2C2_Data: J2.32, R10.2, U1.69 (PA8)
I2C3_Clock: J2.29, R11.2, U1.67 (PC8)
I2C3_Data: J2.30, R12.2, U1.68 (PC9)
I2C4_Clock: J2.27, R13.2, U1.65 (PC6)
I2C4_Data: J2.28, R14.2, U1.66 (PC7)
LED_Clock: J2.18, U1.52 (PB13)
LED_Data: J2.20, U1.54 (PB15)
LED_Latch: J2.19, U1.53 (PB14)
LED_PWM: J6.8, U1.16 (PC1)
LED_TEST: J6.5, R23.1, U1.19 (PF2)
MASTER_CS_IN: J6.23, U1.93 (PB6)
MASTER_Clock: J6.26, U1.90 (PB3)
MASTER_MISO: J6.25, U1.91 (PB4)
MASTER_MOSI: J6.24, U1.92 (PB5)
NRST: C3.2, J1.12 (~RST), SW1.2, U1.14 (PG10)
unnamed: C2.2, R1.1, X1.2
unnamed: D1.2 (A), R16.2
unnamed: D2.2 (A), R17.2
unnamed: D3.2 (A), R23.2
unnamed: JP1.1 (A), R7.1
unnamed: JP2.1 (A), R8.1
unnamed: JP3.1 (A), R9.1
unnamed: JP4.1 (A), R10.1
unnamed: JP5.1 (A), R11.1
unnamed: JP6.1 (A), R12.1
unnamed: JP7.1 (A), R13.1
unnamed: JP8.1 (A), R14.1
unnamed: C1.1, U1.12 (PF0), X1.1
unnamed: R1.2, U1.13 (PF1)
SHIFTREG_Clock: J2.34, U1.72 (PA11)
SHIFTREG_Data: J2.35, U1.73 (PA12)
SHIFTREG_Latch: J6.4, U1.20 (PA0)
SWDCK: J1.6 (JCLK/SWCLK), J6.35, U1.77 (PA14)
SWDIO: J1.4 (JTMS/SWDIO), J6.36, U1.76 (PA13)
USART2_RX: J1.13 (VCP_RX), J6.1, U1.25 (PA3)
USART2_TX: J1.14 (VCP_TX), J6.2, U1.22 (PA2)
xPB0: J2.7, U1.32 (PB0)
xPC14: J6.12, U1.8 (PC14)
xPC15: J6.11, U1.9 (PC15)
xPD8: J2.21, U1.55 (PD8)
xPD9: J2.22, U1.56 (PD9)
xPE0: J6.20, U1.97 (PE0)
xPE1: J6.19, U1.98 (PE1)
xPE2: J6.17, U1.1 (PE2)
xPE3: J6.16, U1.2 (PE3)
xPE6: J6.13, U1.5 (PE6)
xPF9: J6.10, U1.10 (PF9)

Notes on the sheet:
I2C PULLUP
BULK DECOUPLING
POWER LEDS
STLINK-V3MINIE
POWER OUTPUTS
DISPLAY DATA PINS
POWER
PIN BREAKOUTS
LOCAL DECOUPLING
DC-DC 10V-5V 3A
DC-DC 10V-3V3 3A
BOARD LED PF2
LEFT SIDE
RIGHT SIDE

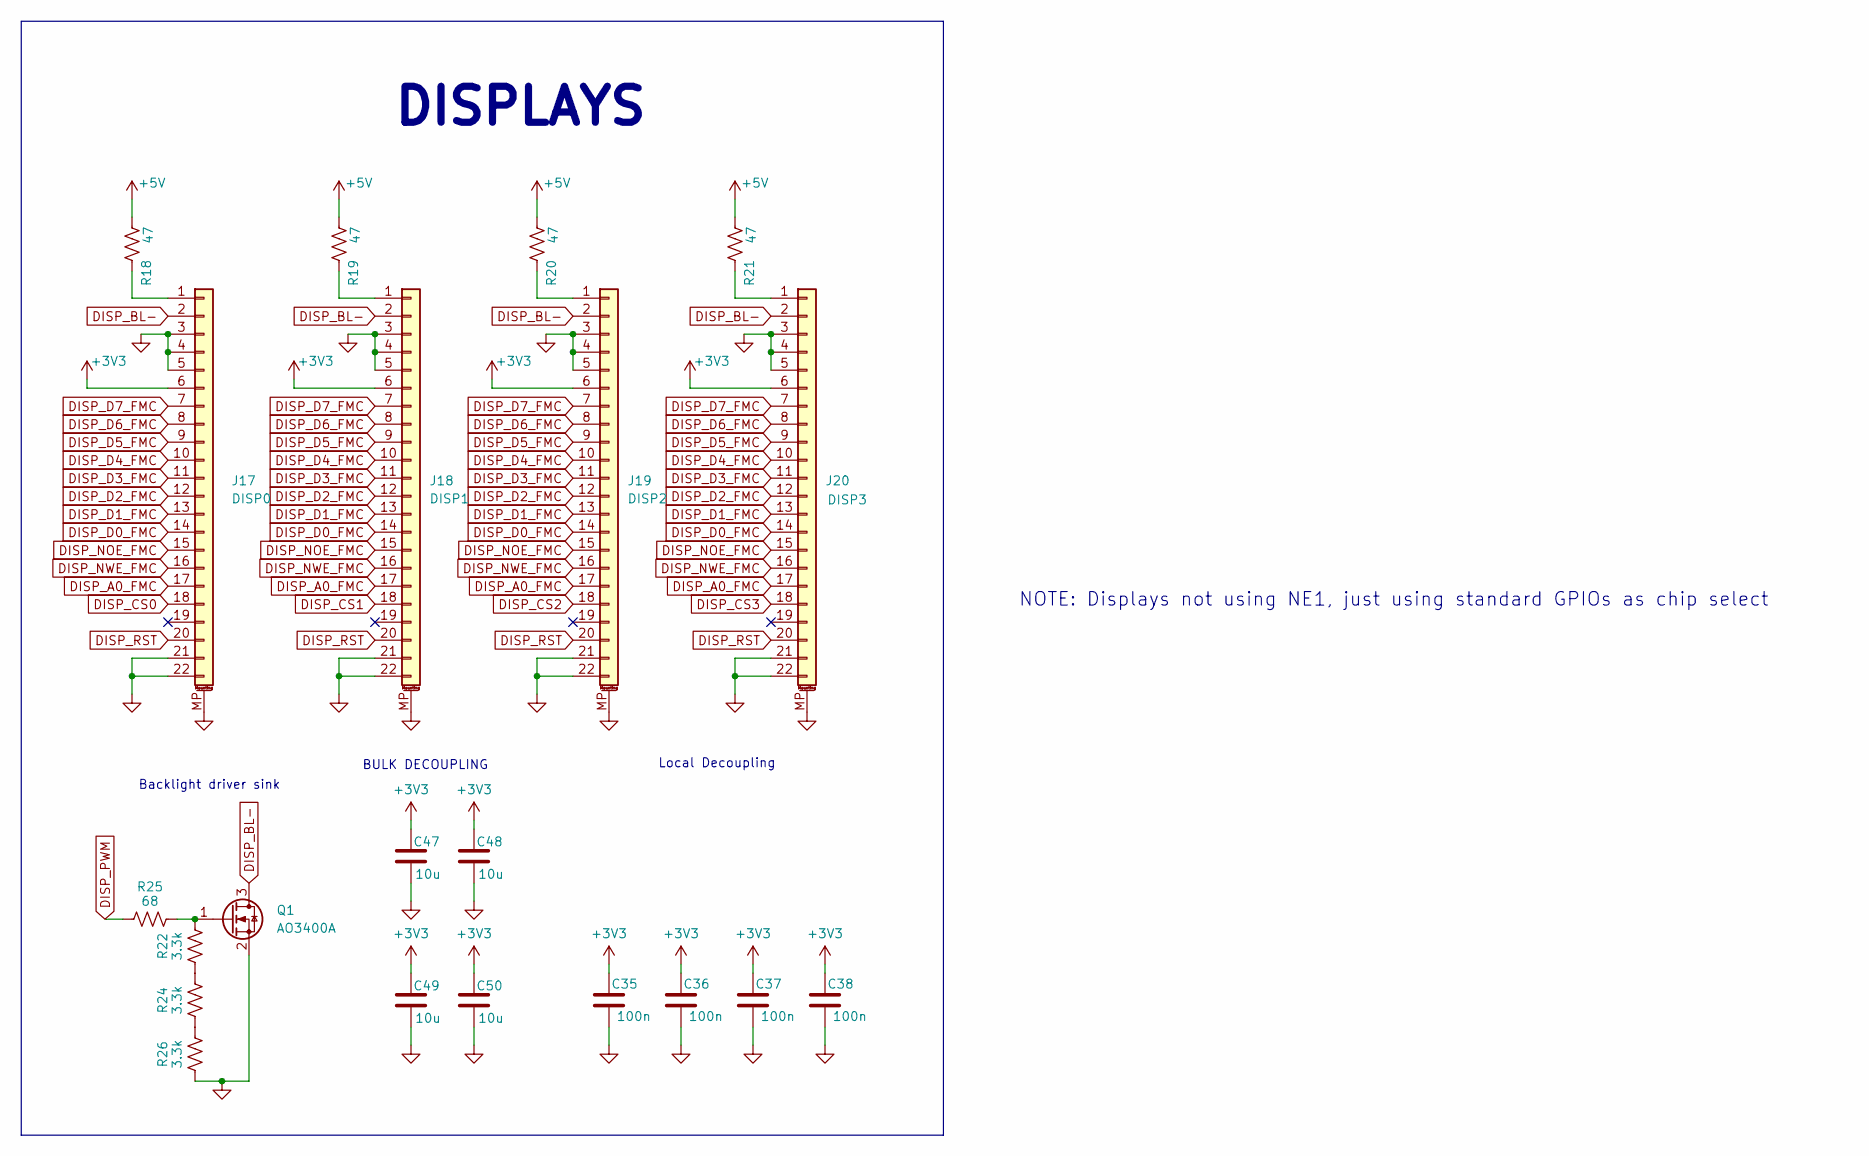
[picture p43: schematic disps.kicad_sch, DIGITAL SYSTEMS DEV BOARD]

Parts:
C35, C36, C37, C38: 100n; C_0603_1608Metric; LCSC C1590
C47, C48, C49, C50: 10u; C_1206_3216Metric; LCSC C1849
J17: DISP0; TE_2-1734839-2_1x22-1MP_P0.5mm_Horizontal; LCSC C22435644
J18: DISP1; TE_2-1734839-2_1x22-1MP_P0.5mm_Horizontal; LCSC C22435644
J19: DISP2; TE_2-1734839-2_1x22-1MP_P0.5mm_Horizontal; LCSC C22435644
J20: DISP3; TE_2-1734839-2_1x22-1MP_P0.5mm_Horizontal; LCSC C22435644
Q1: AO3400A; SOT-23; LCSC C20917
R18, R19, R20, R21: 47; R_1206_3216Metric; LCSC C17969
R22, R24, R26: 3.3k; R_0603_1608Metric; LCSC C22978
R25: 68; R_1206_3216Metric; LCSC C294793

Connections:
+3V3: C35.1, C36.1, C37.1, C38.1, C47.1, C48.1, C49.1, C50.1, J17.6, J18.6, J19.6, J20.6; also elsewhere on the board
+5V: R18.2, R19.2, R20.2, R21.2; also elsewhere on the board
DISP_A0_FMC: J17.17, J18.17, J19.17, J20.17; also elsewhere on the board
DISP_BL-: J17.2, J18.2, J19.2, J20.2, Q1.3 (D)
DISP_CS0: J17.18; also elsewhere on the board
DISP_CS1: J18.18; also elsewhere on the board
DISP_CS2: J19.18; also elsewhere on the board
DISP_CS3: J20.18; also elsewhere on the board
DISP_D0_FMC: J17.14, J18.14, J19.14, J20.14; also elsewhere on the board
DISP_D1_FMC: J17.13, J18.13, J19.13, J20.13; also elsewhere on the board
DISP_D2_FMC: J17.12, J18.12, J19.12, J20.12; also elsewhere on the board
DISP_D3_FMC: J17.11, J18.11, J19.11, J20.11; also elsewhere on the board
DISP_D4_FMC: J17.10, J18.10, J19.10, J20.10; also elsewhere on the board
DISP_D5_FMC: J17.9, J18.9, J19.9, J20.9; also elsewhere on the board
DISP_D6_FMC: J17.8, J18.8, J19.8, J20.8; also elsewhere on the board
DISP_D7_FMC: J17.7, J18.7, J19.7, J20.7; also elsewhere on the board
DISP_NOE_FMC: J17.15, J18.15, J19.15, J20.15; also elsewhere on the board
DISP_NWE_FMC: J17.16, J18.16, J19.16, J20.16; also elsewhere on the board
DISP_PWM: R25.1; also elsewhere on the board
DISP_RST: J17.20, J18.20, J19.20, J20.20; also elsewhere on the board
GND: C35.2, C36.2, C37.2, C38.2, C47.2, C48.2, C49.2, C50.2, J17.3, J17.4, J17.5, J17.21, J17.22, J17.MP (MountPin), J18.3, J18.4, J18.5, J18.21, J18.22, J18.MP (MountPin), J19.3, J19.4, J19.5, J19.21, J19.22, J19.MP (MountPin), J20.3, J20.4, J20.5, J20.21, J20.22, J20.MP (MountPin), Q1.2 (S), R26.1; also elsewhere on the board
unnamed: J17.1, R18.1
unnamed: J18.1, R19.1
unnamed: J19.1, R20.1
unnamed: J20.1, R21.1
unnamed: Q1.1 (G), R22.2, R25.2
unnamed: R22.1, R24.2
unnamed: R24.1, R26.2

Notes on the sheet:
DISPLAYS
Local Decoupling
Backlight driver sink
NOTE: Displays not using NE1, just using standard GPIOs as chip select
BULK DECOUPLING

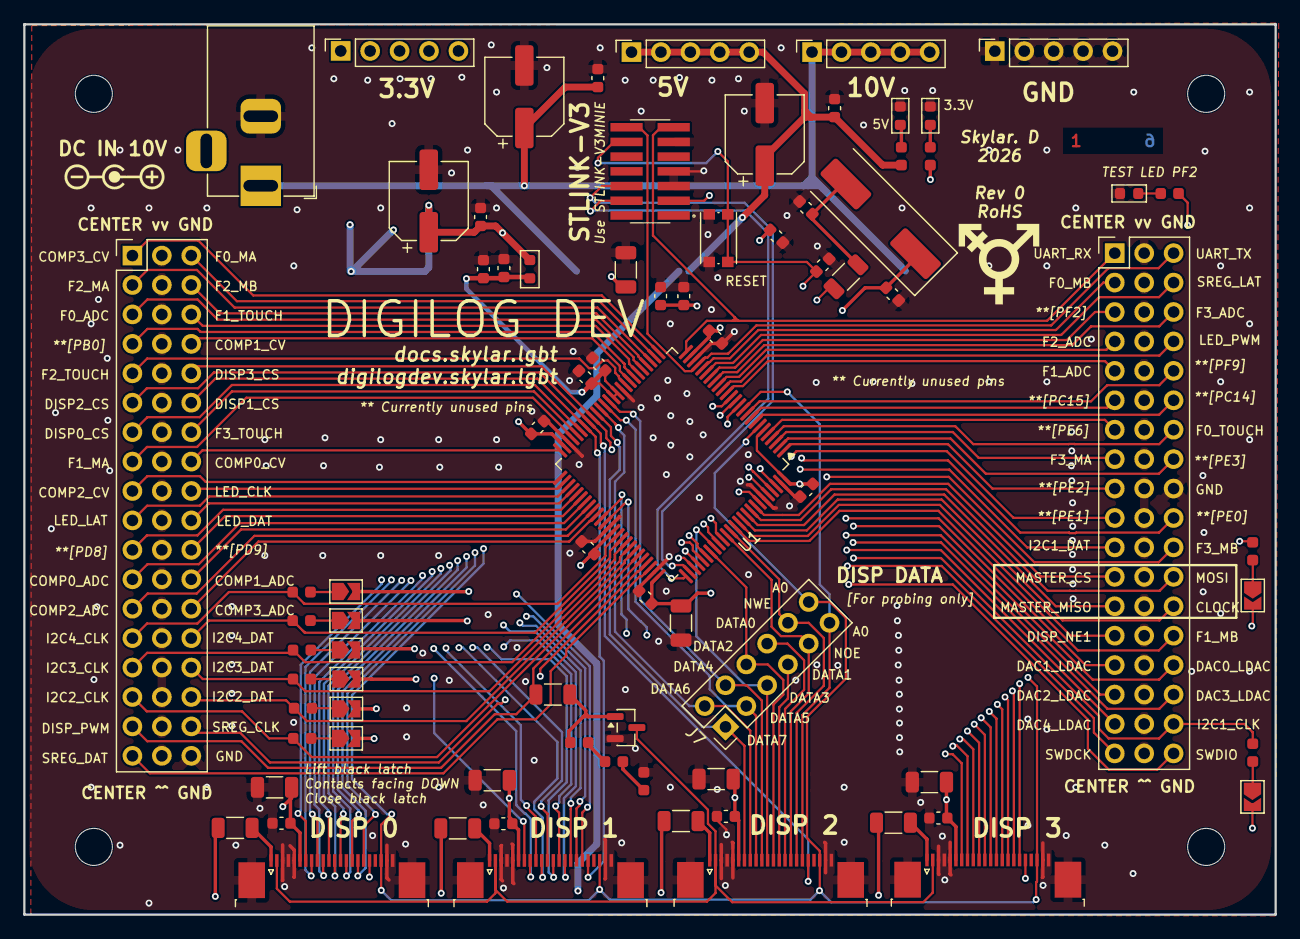
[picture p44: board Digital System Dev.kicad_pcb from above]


Board: 6 copper layers, 108.0 x 76.8 mm, 86 parts (2 on the bottom side), 110 nets.

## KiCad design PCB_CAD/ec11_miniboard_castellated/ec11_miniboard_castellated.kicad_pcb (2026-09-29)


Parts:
J1, J2, J3, J4: Conn_01x01; castellated_single
SW1: EC11_Rotary_Encoder; EC11J0924411

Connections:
GND: J4.1 (Pin_1_1), SW1.C (Pin_2), SW1.D (Pin_4), SW1.G (Pin_6)
unnamed: J1.1 (Pin_1_1), SW1.A (Pin_1)
unnamed: J2.1 (Pin_1_1), SW1.B (Pin_3)
unnamed: J3.1 (Pin_1_1), SW1.E (Pin_5)


Board: 2 copper layers, 18.2 x 12.8 mm, 5 parts (0 on the bottom side), 4 nets.

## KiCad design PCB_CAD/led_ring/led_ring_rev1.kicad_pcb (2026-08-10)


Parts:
C1, C2, C3, C4: 100n; C_0402_1005Metric; LCSC C1525
C5: 10u; C_0402_1005Metric; LCSC C386033
D1, D2, D3, D4, D5, D6, D7, D8, D9, D10, D11, D12, D13, D14, D15, D16, D17, D18, D19, D20, D21, D22, D23, D24, D25, D26, D27, D28, D29, D30, D31, D32: LED; LED_0201_0603Metric; LCSC C52675959
J1: DATA; PinHeader_1x04_P2.54mm_Vertical; LCSC C5116483
J2: POW; PinHeader_1x04_P2.54mm_Vertical; LCSC C5116483
R1, R2, R3, R4, R5, R6, R7, R8, R9, R10, R11, R12, R13, R14, R15, R16, R17, R18, R19, R20, R21, R22, R23, R24, R25, R26, R27, R28, R29, R30, R31, R32: 560; R_0201_0603Metric; LCSC C295808
U1, U2, U3, U4: 74HCT595PW; TSSOP-16_4.4x5mm_P0.65mm; LCSC C54411086
V2, V3, V4, V5, V6, V7, V9, V10, V11, V12, V13, V14, V15, V16, V17, V18, V19, V20, V21, V22, V23, V24, V25, V26, V28, V29, V30, V31, V32: VIA; VIA_0.5_0.3

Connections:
/CAS: J2.1, U4.9 (QH')
/CLK: J1.2, U1.11 (SRCLK), U2.11 (SRCLK), U3.11 (SRCLK), U4.11 (SRCLK)
/DAT: J1.1, U1.14 (SER)
/GND: C1.2, C2.2, C3.2, C4.2, C5.2, D1.1 (K), D2.1 (K), D31.1 (K), D32.1 (K), J2.2, R3.2, R4.2, R5.2, R6.2, R7.2, R8.2, R9.2, R10.2, R11.2, R12.2, R13.2, R14.2, R15.2, R16.2, R17.2, R18.2, R19.2, R20.2, R21.2, R22.2, R23.2, R24.2, R25.2, R26.2, R27.2, R28.2, R29.2, R30.2, U1.8 (GND), U2.8 (GND), U3.8 (GND), U4.8 (GND)
/LAT: J1.3, U1.12 (RCLK), U2.12 (RCLK), U3.12 (RCLK), U4.12 (RCLK)
/OE: J1.4, U1.13 (~OE), U2.13 (~OE), U3.13 (~OE), U4.13 (~OE)
/VCC: C1.1, C2.1, C3.1, C4.1, C5.1, J2.3, J2.4, U1.10 (~SRCLR), U1.16 (VCC), U2.10 (~SRCLR), U2.16 (VCC), U3.10 (~SRCLR), U3.16 (VCC), U4.10 (~SRCLR), U4.16 (VCC)
unnamed: D1.2 (A), R1.2
unnamed: D2.2 (A), R2.2
unnamed: D3.2 (A), U1.2 (QC), V3.1, V3.2
unnamed: D3.1 (K), R3.1
unnamed: D4.2 (A), U1.3 (QD), V4.1, V4.2
unnamed: D4.1 (K), R4.1
unnamed: D5.2 (A), U1.4 (QE), V5.1, V5.2
unnamed: D5.1 (K), R5.1
unnamed: D6.2 (A), U1.5 (QF), V6.1, V6.2
unnamed: D6.1 (K), R6.1
unnamed: D7.2 (A), U1.6 (QG), V7.1, V7.2
unnamed: D7.1 (K), R7.1
unnamed: D8.2 (A), U1.7 (QH)
unnamed: D8.1 (K), R8.1
unnamed: D9.2 (A), U2.15 (QA), V9.1, V9.2
unnamed: D9.1 (K), R9.1
unnamed: D10.2 (A), U2.1 (QB), V10.1, V10.2
unnamed: D10.1 (K), R10.1
unnamed: D11.2 (A), U2.2 (QC), V11.1, V11.2
unnamed: D11.1 (K), R11.1
unnamed: D12.2 (A), U2.3 (QD), V12.1, V12.2
unnamed: D12.1 (K), R12.1
unnamed: D13.2 (A), U2.4 (QE), V13.1, V13.2
unnamed: D13.1 (K), R13.1
unnamed: D14.2 (A), U2.5 (QF), V14.1, V14.2
unnamed: D14.1 (K), R14.1
unnamed: D15.2 (A), U2.6 (QG), V15.1, V15.2
unnamed: D15.1 (K), R15.1
unnamed: D16.2 (A), U2.7 (QH), V16.1, V16.2
unnamed: D16.1 (K), R16.1
unnamed: D17.2 (A), U3.15 (QA), V17.1, V17.2
unnamed: D17.1 (K), R17.1
unnamed: D18.2 (A), U3.1 (QB), V18.1, V18.2
unnamed: D18.1 (K), R18.1
unnamed: D19.2 (A), U3.2 (QC), V19.1, V19.2
unnamed: D19.1 (K), R19.1
unnamed: D20.2 (A), U3.3 (QD), V20.1, V20.2
unnamed: D20.1 (K), R20.1
unnamed: D21.2 (A), U3.4 (QE), V21.1, V21.2
unnamed: D21.1 (K), R21.1
unnamed: D22.2 (A), U3.5 (QF), V22.1, V22.2
unnamed: D22.1 (K), R22.1
unnamed: D23.2 (A), U3.6 (QG), V23.1, V23.2
unnamed: D23.1 (K), R23.1
unnamed: D24.2 (A), U3.7 (QH), V24.1, V24.2
unnamed: D24.1 (K), R24.1
unnamed: D25.2 (A), U4.15 (QA), V25.1, V25.2
unnamed: D25.1 (K), R25.1
unnamed: D26.2 (A), U4.1 (QB), V26.1, V26.2
unnamed: D26.1 (K), R26.1
unnamed: D27.2 (A), U4.2 (QC)
unnamed: D27.1 (K), R27.1
unnamed: D28.2 (A), U4.3 (QD), V28.1, V28.2
unnamed: D28.1 (K), R28.1
unnamed: D29.2 (A), U4.4 (QE), V29.1, V29.2
unnamed: D29.1 (K), R29.1
unnamed: D30.2 (A), U4.5 (QF), V30.1, V30.2
unnamed: D30.1 (K), R30.1
unnamed: D31.2 (A), R31.2
unnamed: D32.2 (A), R32.2
unnamed: R1.1, U1.15 (QA)
unnamed: R2.1, U1.1 (QB), V2.1, V2.2
unnamed: U1.9 (QH'), U2.14 (SER)
unnamed: U2.9 (QH'), U3.14 (SER)
unnamed: U3.9 (QH'), U4.14 (SER)
unnamed: R31.1, U4.6 (QG), V31.1, V31.2
unnamed: R32.1, U4.7 (QH), V32.1, V32.2

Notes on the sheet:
DATA: 1 = SERIAL IN 2 = CLK 3 = LATCH ENABLE 4 = OUTPUT ENABLE
POW: 1 = SERIAL OUT (CASCADE) 2 = GND 3 = 5V 4 = 5V



Board: 4 copper layers, 24.0 x 24.0 mm, 104 parts (6 on the bottom side), 74 nets.

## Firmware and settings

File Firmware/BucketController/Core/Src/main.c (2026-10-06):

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
/* Includes ------------------------------------------------------------------*/
#include "main.h"
#include "cmsis_os.h"

/* USER CODE BEGIN Includes */

#include <stdio.h>

// Skylar
#include "CONFIG.h"
#include "cmsis_os2.h"
#include "control_integration/control_interface.h"
#include "hardware_drivers/fader_driver.h"
#include "hardware_drivers/i2c_driver.h"
#include "hardware_drivers/mcp23017.h"
#include "hardware_drivers/mcp4728.h"
#include "hardware_drivers/mcp4728_cache.h"
#include "hardware_drivers/rotary_encoder.h"
#include "hardware_drivers/led_driver.h"
#include "hardware_drivers/74hc595.h"
#include "portmacro.h"
#include "projdefs.h"
#include "stm32g474xx.h"
#include "FreeRTOS_apps/remote_cmd_handler.h"
#include "FreeRTOS_apps/led_handler.h"
#include "FreeRTOS_apps/i2c_scheduler.h"
#include "FreeRTOS_apps/fader_poller.h"
#include "stm32g4xx_hal.h"

/* USER CODE END Includes */

ADC_HandleTypeDef hadc2;

DAC_HandleTypeDef hdac3;

I2C_HandleTypeDef hi2c1;
I2C_HandleTypeDef hi2c2;
I2C_HandleTypeDef hi2c3;
I2C_HandleTypeDef hi2c4;

SPI_HandleTypeDef hspi1;
SPI_HandleTypeDef hspi2;
DMA_HandleTypeDef hdma_spi2_tx;

TIM_HandleTypeDef htim1;
TIM_HandleTypeDef htim2;
TIM_HandleTypeDef htim3;
TIM_HandleTypeDef htim4;
TIM_HandleTypeDef htim5;

UART_HandleTypeDef huart2;

/* Definitions for defaultTask */
osThreadId_t defaultTaskHandle;
const osThreadAttr_t defaultTask_attributes = {
  .name = "defaultTask",
  .priority = (osPriority_t) osPriorityNormal,
  .stack_size = 128 * 4
};
void SystemClock_Config(void);
static void MX_GPIO_Init(void);
static void MX_DMA_Init(void);
static void MX_I2C1_Init(void);
static void MX_I2C2_Init(void);
static void MX_I2C4_Init(void);
static void MX_TIM2_Init(void);
static void MX_TIM3_Init(void);
static void MX_TIM1_Init(void);
static void MX_USART2_UART_Init(void);
static void MX_I2C3_Init(void);
static void MX_SPI1_Init(void);
static void MX_ADC2_Init(void);
static void MX_DAC3_Init(void);
static void MX_TIM4_Init(void);
static void MX_TIM5_Init(void);
static void MX_SPI2_Init(void);
void StartDefaultTask(void *argument);

/* USER CODE BEGIN 0 */


// start usart2 usb debug
// picocom -b 115200 /dev/cu.usbmodem#####
int __io_putchar(int ch)
{
  if (DEVELOPER_MODE)
  {
    HAL_UART_Transmit(&huart2, (uint8_t *)&ch, 1, 100);
  }
  return ch;
}

/* USER CODE END 0 */

/**
  * @brief  The application entry point.
  * @retval int
  */
int main(void)
{

  /* MCU Configuration--------------------------------------------------------*/

  /* Reset of all peripherals, Initializes the Flash interface and the Systick. */
  HAL_Init();

  /* Configure the system clock */
  SystemClock_Config();

  /* Initialize all configured peripherals */
  MX_GPIO_Init();
  MX_DMA_Init();
  MX_I2C1_Init();
  MX_I2C2_Init();
  MX_I2C4_Init();
  MX_TIM2_Init();
  MX_TIM3_Init();
  MX_TIM1_Init();
  MX_USART2_UART_Init();
  MX_I2C3_Init();
  MX_SPI1_Init();
  MX_ADC2_Init();
  MX_DAC3_Init();
  MX_TIM4_Init();
  MX_TIM5_Init();
  MX_SPI2_Init();
  /* USER CODE BEGIN 2 */

  /*=============================== STARTUP HARDWARE INITIALIZATION ================================*/

  if(DEVELOPER_MODE)
  {
    setvbuf(stdout, NULL, _IONBF, 0); // make lines never disappear USART2
  }

  i2c_init(); // i2c startup

  if(DEVELOPER_MODE)
  {
    printf("\r\n\n\n\n\n\n\n\n\n*******************************************************\r\n");
    printf("Initializing Bucket Controller...\r\n    Build %s %s \r\n\nBEGIN debug log:\r\n", __DATE__, __TIME__);
    printf("*******************************************************\r\n");

    i2c_probeall();
  }

  uart_cmd_init(); // uart2 startup for comms w/ remote app

  led_init(); // PLEASE keep led_init before init_control_interface. otherwise control hardware gets set to nullptrs and we have no LEDs
  init_control_interface();
  shiftreg_init();

  led_brightness(10);


  // I2C DEVICES INIT
  mcp23017_init(I2C1, 0x20);
  mcp4728_init_settings(I2C1, 0x61);

  if(DEVELOPER_MODE)
  {
  led_print_config();

  printf("\r\n*******************************************************\n");
  }



  /*=============================== END STARTUP HARDWARE INITIALIZATION ================================*/


  /* USER CODE END 2 */

  /* Init scheduler */
  osKernelInitialize();

  /* USER CODE BEGIN RTOS_MUTEX */
  /* add mutexes, ... */
  /* USER CODE END RTOS_MUTEX */

  /* USER CODE BEGIN RTOS_SEMAPHORES */
  /* add semaphores, ... */
  /* USER CODE END RTOS_SEMAPHORES */

  /* USER CODE BEGIN RTOS_TIMERS */
  /* start timers, add new ones, ... */
  /* USER CODE END RTOS_TIMERS */

  /* USER CODE BEGIN RTOS_QUEUES */
  /* add queues, ... */
  /* USER CODE END RTOS_QUEUES */

  /* Create the thread(s) */
  /* creation of defaultTask */
  defaultTaskHandle = osThreadNew(StartDefaultTask, NULL, &defaultTask_attributes);

  /* USER CODE BEGIN RTOS_THREADS */

  init_led_handler(); // start LED frame renderer
  init_i2c_scheduler();
  init_fader_poller();
  init_faders();

  /* USER CODE END RTOS_THREADS */

  /* USER CODE BEGIN RTOS_EVENTS */
  /* add events, ... */
  /* USER CODE END RTOS_EVENTS */

  /* Start scheduler */
  osKernelStart();

  /* We should never get here as control is now taken by the scheduler */

  /* Infinite loop */
  /* USER CODE BEGIN WHILE */
  while (1)
  {
    /* USER CODE END WHILE */

    /* USER CODE BEGIN 3 */
  }
  /* USER CODE END 3 */
}

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
/* USER CODE BEGIN Header_StartDefaultTask */
/**
  * @brief  Function implementing the defaultTask thread.
  * @param  argument: Not used
  * @retval None
  */
/* USER CODE END Header_StartDefaultTask */
void StartDefaultTask(void *argument)
{
  /* USER CODE BEGIN 5 */
  

  // bb_claim(I2C1_Clock_GPIO_Port, I2C1_Clock_Pin, I2C1_Data_GPIO_Port, I2C1_Data_Pin);  
  /*mcp4728_init_address(
    GPIOA, // Clock port
    15, // Clock pin
    GPIOB, // Data port
    9, // Data pin
    GPIOB, // ldac port
    6, // ldac pin
    0x62 // New addr
  );*/
  // bb_release(I2C1_Clock_GPIO_Port, I2C1_Clock_Pin, I2C1_Data_GPIO_Port, I2C1_Data_Pin, 4);

  for (;;) // this MUST STAY
  {
    vTaskDelay(portMAX_DELAY);
  }
  


  /* USER CODE END 5 */
}

/**
  * @brief  Period elapsed callback in non blocking mode
  * @note   This function is called  when TIM7 interrupt took place, inside
  * HAL_TIM_IRQHandler(). It makes a direct call to HAL_IncTick() to increment
  * a global variable "uwTick" used as application time base.
  * @param  htim : TIM handle
  * @retval None
  */
void HAL_TIM_PeriodElapsedCallback(TIM_HandleTypeDef *htim)
{
  if (htim->Instance == TIM7)
  {
    HAL_IncTick();
  }
  /* USER CODE BEGIN Callback 1 */

  // I2C Scheduler
  else if (htim->Instance == TIM4){
    i2c_scheduler_trigger_frame();
    fader_poller_trigger_frame();
  }

  // skylar (adding the ISR for LED handler)
  else if (htim->Instance == TIM5)
  {
    led_handler_notify_from_isr();
  }

  /* USER CODE END Callback 1 */
}

/**
  * @brief  This function is executed in case of error occurrence.
  * @retval None
  */
void Error_Handler(void)
{
  /* USER CODE BEGIN Error_Handler_Debug */
  printf("\r\nError!!!!!!!!!!\n");
  __disable_irq();
  while (1)
  {
  }
  /* USER CODE END Error_Handler_Debug */
}
#ifdef USE_FULL_ASSERT
/**
  * @brief  Reports the name of the source file and the source line number
  *         where the assert_param error has occurred.
  * @param  file: pointer to the source file name
  * @param  line: assert_param error line source number
  * @retval None
  */
void assert_failed(uint8_t *file, uint32_t line)
{
  /* USER CODE BEGIN 6 */
  /* User can add his own implementation to report the file name and line number,
     ex: printf("Wrong parameters value: file %s on line %d\r\n", file, line) */
  /* USER CODE END 6 */
}
#endif /* USE_FULL_ASSERT */

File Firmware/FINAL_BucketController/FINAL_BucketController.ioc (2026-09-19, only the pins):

Mcu.UserName=STM32G474VETx
PA0.GPIO_Label=SHIFTREG_Latch
PA0.Signal=GPIO_Output
PA1.GPIO_Label=F0_MoB
PA1.Signal=S_TIM2_CH2
PA10.GPIO_Label=F1_MoB
PA10.Signal=S_TIM2_CH4
PA11.GPIO_Label=SHIFTREG_Clock
PA11.Signal=GPIO_Output
PA12.GPIO_Label=SHIFTREG_Data
PA12.Signal=GPIO_Output
PA13.GPIO_Label=__SWDIO
PA13.Signal=SYS_JTMS-SWDIO
PA14.GPIO_Label=__SWCLK
PA14.Signal=SYS_JTCK-SWCLK
PA15.GPIO_Label=I2C1_Clock
PA15.Signal=I2C1_SCL
PA2.GPIO_Label=__USART2_TX
PA2.Signal=USART2_TX
PA3.GPIO_Label=__USART2_RX
PA3.Signal=USART2_RX
PA4.GPIO_Label=F2_MoB
PA4.Signal=S_TIM3_CH2
PA5.GPIO_Label=F0_MoA
PA5.Signal=S_TIM2_CH1
PA6.GPIO_Label=F2_MoA
PA6.Signal=S_TIM3_CH1
PA7.GPIO_Label=MASTER_MOSI
PA7.Signal=SPI1_MOSI
PA8.GPIO_Label=I2C2_Data
PA8.Signal=I2C2_SDA
PA9.GPIO_Label=I2C2_Clock
PA9.Signal=I2C2_SCL
PB0.GPIO_Label=F3_MoA
PB0.Signal=S_TIM3_CH3
PB1.GPIO_Label=COMP_ADC1
PB1.Signal=ADC1_IN12
PB10.GPIO_Label=F1_MoA
PB10.Signal=S_TIM2_CH3
PB11.GPIO_Label=LED_Data
PB11.Signal=GPIO_Output
PB12.GPIO_Label=LED_Clock
PB12.Signal=GPIO_Output
PB13.GPIO_Label=COMP_CV1
PB13.Signal=OPAMP3_VINP
PB14.GPIO_Label=LED_Latch
PB14.Signal=GPIO_Output
PB15.GPIO_Label=DISP_CS3
PB15.Signal=GPIO_Output
PB2.GPIO_Label=DISP_CS0
PB2.Signal=GPIO_Output
PB3.GPIO_Label=MASTER_Clock
PB3.Signal=SPI1_SCK
PB4.GPIO_Label=MASTER_MISO
PB4.Signal=SPI1_MISO
PB5.GPIO_Label=I2C3_Data
PB5.Signal=I2C3_SDA
PB6.GPIO_Label=DAC_LDAC2
PB6.Signal=GPIO_Output
PB9.GPIO_Label=I2C1_Data
PB9.Signal=I2C1_SDA
PC0.GPIO_Label=MASTER_CS_IN
PC0.Signal=GPIO_Input
PC1.GPIO_Label=LED_PWM
PC1.Signal=S_TIM1_CH2
PC10.GPIO_Label=F3_Touch
PC10.Signal=GPIO_Input
PC11.GPIO_Label=F2_Touch
PC11.Signal=GPIO_Input
PC12.GPIO_Label=F1_Touch
PC12.Signal=GPIO_Input
PC2.GPIO_Label=DISP_PWM
PC2.Signal=S_TIM1_CH3
PC3.GPIO_Label=COMP_ADC0
PC3.Signal=ADC1_IN9
PC4.GPIO_Label=COMP_ADC2
PC4.Signal=ADC2_IN5
PC5.GPIO_Label=COMP_ADC3
PC5.Signal=ADC2_IN11
PC6.GPIO_Label=I2C4_Clock
PC6.Signal=I2C4_SCL
PC7.GPIO_Label=I2C4_Data
PC7.Signal=I2C4_SDA
PC8.GPIO_Label=I2C3_Clock
PC8.Signal=I2C3_SCL
PD0.GPIO_Label=DISP_D2_FMC
PD0.Signal=FMC_D2
PD1.GPIO_Label=DISP_D3_FMC
PD1.Signal=FMC_D3
PD10.GPIO_Label=F1_ADC
PD10.Signal=ADC3_IN7
PD11.GPIO_Label=COMP_CV2
PD11.Signal=OPAMP4_VINP
PD12.GPIO_Label=COMP_CV3
PD12.Signal=OPAMP5_VINP
PD13.GPIO_Label=F2_ADC
PD13.Signal=ADC3_IN10
PD14.GPIO_Label=DISP_D0_FMC
PD14.Signal=FMC_D0
PD15.GPIO_Label=DISP_D1_FMC
PD15.Signal=FMC_D1
PD2.GPIO_Label=F0_Touch
PD2.Signal=GPIO_Input
PD3.GPIO_Label=DAC_LDAC4
PD3.Signal=GPIO_Output
PD4.GPIO_Label=DISP_NOE_FMC
PD4.Signal=FMC_NOE
PD5.GPIO_Label=DISP_NWE_FMC
PD5.Signal=FMC_NWE
PD6.GPIO_Label=DAC_LDAC3
PD6.Signal=GPIO_Output
PD7.GPIO_Label=DISP_NE1_FMC
PD7.Signal=FMC_NE1
PD9.GPIO_Label=COMP_CV0
PD9.Signal=OPAMP6_VINP
PE0.GPIO_Label=DAC_LDAC1
PE0.Signal=GPIO_Output
PE1.GPIO_Label=DAC_LDAC0
PE1.Signal=GPIO_Output
PE10.GPIO_Label=DISP_D7_FMC
PE10.Signal=FMC_D7
PE11.GPIO_Label=F3_ADC
PE11.Signal=ADC3_IN15
PE13.GPIO_Label=F0_ADC
PE13.Signal=ADC3_IN3
PE14.GPIO_Label=DISP_CS1
PE14.Signal=GPIO_Output
PE15.GPIO_Label=DISP_CS2
PE15.Signal=GPIO_Output
PE4.GPIO_Label=DISP_RST
PE4.Signal=GPIO_Output
PE5.GPIO_Label=F3_MoB
PE5.Signal=S_TIM3_CH4
PE7.GPIO_Label=DISP_D4_FMC
PE7.Signal=FMC_D4
PE8.GPIO_Label=DISP_D5_FMC
PE8.Signal=FMC_D5
PE9.GPIO_Label=DISP_D6_FMC
PE9.Signal=FMC_D6
PF0-OSC_IN.GPIO_Label=__OSC_IN
PF0-OSC_IN.Signal=RCC_OSC_IN
PF1-OSC_OUT.GPIO_Label=__OSC_OUT
PF1-OSC_OUT.Signal=RCC_OSC_OUT
PF10.GPIO_Label=DISP_A0_FMC
PF10.Signal=FMC_A0
PF2.GPIO_Label=LED_TEST
PF2.Signal=GPIO_Output

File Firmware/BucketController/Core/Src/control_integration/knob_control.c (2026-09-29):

#include "control_integration/control_interface.h"
#include "hardware_drivers/button_driver.h"
#include "hardware_drivers/led_driver.h"
#include "hardware_drivers/mcp23017.h"
#include "hardware_drivers/rotary_encoder.h"
#include "hardware_sets.h"
#include "hardware_state_sets.h"
#include "hardware_structs.h"
#include "portmacro.h"
#include "stm32g474xx.h"
#include <stdbool.h>

/* Functions related to accepting some states and updating control values */

static inline I2C_TypeDef *channel_to_i2c_bus(uint8_t channel){
    if(channel == 0) return I2C1;
    if(channel == 1) return I2C2;
    if(channel == 2) return I2C3;
    return I2C4;
}

static void s_update_knob_button (
    SemaphoreHandle_t *out_mutex,
    encoder_state_t *state,
    encoder_info_t *info,
    s_scalar_control_t *out //
)
{
    const bool held = !get_button_held(&(info->button_info));
    const bool pressed = held & !(state->button_state.held);

    state->button_state.held = held;

    if (state->button_state.press_countdown > 0)
    {
        state->button_state.press_countdown--;
    }

    if (!pressed)
    {
        return;
    }

    if (state->button_state.press_countdown == 0)
    {
        // single press
        state->button_state.press_countdown = DOUBLE_PRESS_TIME;
        return;
    }

    // Double press
    xSemaphoreTake(*out_mutex, portMAX_DELAY);
    *out = 0;
    xSemaphoreGive(*out_mutex);
}

static void u_update_knob_button (
    SemaphoreHandle_t *out_mutex,
    encoder_state_t *state,
    encoder_info_t *info,
    u_scalar_control_t *out //
)
{
    // Should be fine to pass it as a pointer like this; 0 is the same signed vs unsigned
    s_update_knob_button(out_mutex, state, info, (s_scalar_control_t *)out);
}


// Use negative sensitivity for backwards turning
static void update_u_value_from_encoder (
    SemaphoreHandle_t *out_mutex,
    encoder_state_t *state,
    encoder_info_t *info,
    u_scalar_control_t *out,
    s_scalar_control_t sensitivity //!< sensitivity must be < S_SCALAR_CONTROL_MAX
)
{
    u_update_knob_button(out_mutex, state, info, out);

    if (state->button_state.held)
    {
        sensitivity /= 2;
    }

    encoder_turn_action_t motion = get_encoder_motion(*info, *state, state);
    if (motion == ENCODER_TURN_B)
    {
        sensitivity = -sensitivity;
    }
    else if (motion != ENCODER_TURN_A)
    {
        return;
    }

    xSemaphoreTake(*out_mutex, portMAX_DELAY);
    if (sensitivity > 0 && U_SCALAR_CONTROL_MAX - *out < (u_scalar_control_t)sensitivity)
    {
        *out = U_SCALAR_CONTROL_MAX;
    }
    else if (sensitivity < 0 && (u_scalar_control_t)(-sensitivity) > *out)
    {
        *out = 0;
    }
    else
    {
        *out += sensitivity;
    }
    xSemaphoreGive(*out_mutex);
}

static void update_s_value_from_encoder (
    SemaphoreHandle_t *out_mutex,
    encoder_state_t *state,
    encoder_info_t *info,
    s_scalar_control_t *out,
    s_scalar_control_t sensitivity //!< sensitivity must be < S_SCALAR_CONTROL_MAX
)
{
    s_update_knob_button(out_mutex, state, info, out);

    if (state->button_state.held)
    {
        sensitivity /= 2;
    }

    encoder_turn_action_t motion = get_encoder_motion(*info, *state, state);
    if (motion == ENCODER_TURN_B)
    {
        sensitivity = -sensitivity;
    }
    else if (motion != ENCODER_TURN_A)
    {
        return;
    }

    xSemaphoreTake(*out_mutex, portMAX_DELAY);
    if (sensitivity > 0 && *out > S_SCALAR_CONTROL_MAX - sensitivity)
    {
        *out = S_SCALAR_CONTROL_MAX;
    }
    else if (sensitivity < 0 && *out < S_SCALAR_CONTROL_MIN - sensitivity)
    {
        *out = S_SCALAR_CONTROL_MIN;
    }
    else
    {
        *out += sensitivity;
    }
    xSemaphoreGive(*out_mutex);
}

void update_channel_knob_values (
    SemaphoreHandle_t *vals_mutex,
    channel_controls *vals,
    channel_control_io_state *state,
    channel_control_io_t *io
)
{
    s_scalar_control_t default_sensitivity = S_SCALAR_CONTROL_MAX / 32;

    update_u_value_from_encoder(
        vals_mutex,
        &(state->input_gain_encoder_state),
        &(io->input_gain_knob.encoder),
        &(vals->input_gain),
        default_sensitivity
    );
    update_s_value_from_encoder(
        vals_mutex,
        &(state->hf_interface_state.gain_encoder_state),
        &(io->hf_interface.gain_knob.encoder),
        &(vals->hf_control.gain),
        default_sensitivity
    );

    // TODO: Do this for the rest of the encoders on the channel
}

void update_channel_knob_leds (
    SemaphoreHandle_t *vals_mutex,
    channel_controls *vals,
    channel_control_io_state *state,
    channel_control_io_t *io
)
{
    // begin skylar [edit 2/2]
    xSemaphoreTake(*vals_mutex, portMAX_DELAY);
    const u_scalar_control_t input_gain = vals->input_gain;
    const s_scalar_control_t hf_gain = vals->hf_control.gain;
    xSemaphoreGive(*vals_mutex);

    // we will need one for each led ring plus logic to display the knob's alternate parameter if it is one with push = other param
    led_set(io->input_gain_knob.led_ring, input_gain);
    led_set_signed(io->hf_interface.gain_knob.led_ring, hf_gain);

    // end skylar [edit 2/2]
}
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

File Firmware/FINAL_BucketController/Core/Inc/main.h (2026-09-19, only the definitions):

#define DISP_RST_Pin GPIO_PIN_4
#define DISP_RST_GPIO_Port GPIOE
#define F3_MoB_Pin GPIO_PIN_5
#define F3_MoB_GPIO_Port GPIOE
#define DISP_A0_FMC_Pin GPIO_PIN_10
#define DISP_A0_FMC_GPIO_Port GPIOF
#define __OSC_IN_Pin GPIO_PIN_0
#define __OSC_IN_GPIO_Port GPIOF
#define __OSC_OUT_Pin GPIO_PIN_1
#define __OSC_OUT_GPIO_Port GPIOF
#define MASTER_CS_IN_Pin GPIO_PIN_0
#define MASTER_CS_IN_GPIO_Port GPIOC
#define LED_PWM_Pin GPIO_PIN_1
#define LED_PWM_GPIO_Port GPIOC
#define DISP_PWM_Pin GPIO_PIN_2
#define DISP_PWM_GPIO_Port GPIOC
#define COMP_ADC0_Pin GPIO_PIN_3
#define COMP_ADC0_GPIO_Port GPIOC
#define LED_TEST_Pin GPIO_PIN_2
#define LED_TEST_GPIO_Port GPIOF
#define SHIFTREG_Latch_Pin GPIO_PIN_0
#define SHIFTREG_Latch_GPIO_Port GPIOA
#define F0_MoB_Pin GPIO_PIN_1
#define F0_MoB_GPIO_Port GPIOA
#define __USART2_TX_Pin GPIO_PIN_2
#define __USART2_TX_GPIO_Port GPIOA
#define __USART2_RX_Pin GPIO_PIN_3
#define __USART2_RX_GPIO_Port GPIOA
#define F2_MoB_Pin GPIO_PIN_4
#define F2_MoB_GPIO_Port GPIOA
#define F0_MoA_Pin GPIO_PIN_5
#define F0_MoA_GPIO_Port GPIOA
#define F2_MoA_Pin GPIO_PIN_6
#define F2_MoA_GPIO_Port GPIOA
#define MASTER_MOSI_Pin GPIO_PIN_7
#define MASTER_MOSI_GPIO_Port GPIOA
#define COMP_ADC2_Pin GPIO_PIN_4
#define COMP_ADC2_GPIO_Port GPIOC
#define COMP_ADC3_Pin GPIO_PIN_5
#define COMP_ADC3_GPIO_Port GPIOC
#define F3_MoA_Pin GPIO_PIN_0
#define F3_MoA_GPIO_Port GPIOB
#define COMP_ADC1_Pin GPIO_PIN_1
#define COMP_ADC1_GPIO_Port GPIOB
#define DISP_CS0_Pin GPIO_PIN_2
#define DISP_CS0_GPIO_Port GPIOB
#define DISP_D4_FMC_Pin GPIO_PIN_7
#define DISP_D4_FMC_GPIO_Port GPIOE
#define DISP_D5_FMC_Pin GPIO_PIN_8
#define DISP_D5_FMC_GPIO_Port GPIOE
#define DISP_D6_FMC_Pin GPIO_PIN_9
#define DISP_D6_FMC_GPIO_Port GPIOE
#define DISP_D7_FMC_Pin GPIO_PIN_10
#define DISP_D7_FMC_GPIO_Port GPIOE
#define F3_ADC_Pin GPIO_PIN_11
#define F3_ADC_GPIO_Port GPIOE
#define F0_ADC_Pin GPIO_PIN_13
#define F0_ADC_GPIO_Port GPIOE
#define DISP_CS1_Pin GPIO_PIN_14
#define DISP_CS1_GPIO_Port GPIOE
#define DISP_CS2_Pin GPIO_PIN_15
#define DISP_CS2_GPIO_Port GPIOE
#define F1_MoA_Pin GPIO_PIN_10
#define F1_MoA_GPIO_Port GPIOB
#define LED_Data_Pin GPIO_PIN_11
#define LED_Data_GPIO_Port GPIOB
#define LED_Clock_Pin GPIO_PIN_12
#define LED_Clock_GPIO_Port GPIOB
#define COMP_CV1_Pin GPIO_PIN_13
#define COMP_CV1_GPIO_Port GPIOB
#define LED_Latch_Pin GPIO_PIN_14
#define LED_Latch_GPIO_Port GPIOB
#define DISP_CS3_Pin GPIO_PIN_15
#define DISP_CS3_GPIO_Port GPIOB
#define COMP_CV0_Pin GPIO_PIN_9
#define COMP_CV0_GPIO_Port GPIOD
#define F1_ADC_Pin GPIO_PIN_10
#define F1_ADC_GPIO_Port GPIOD
#define COMP_CV2_Pin GPIO_PIN_11
#define COMP_CV2_GPIO_Port GPIOD
#define COMP_CV3_Pin GPIO_PIN_12
#define COMP_CV3_GPIO_Port GPIOD
#define F2_ADC_Pin GPIO_PIN_13
#define F2_ADC_GPIO_Port GPIOD
#define DISP_D0_FMC_Pin GPIO_PIN_14
#define DISP_D0_FMC_GPIO_Port GPIOD
#define DISP_D1_FMC_Pin GPIO_PIN_15
#define DISP_D1_FMC_GPIO_Port GPIOD
#define I2C4_Clock_Pin GPIO_PIN_6
#define I2C4_Clock_GPIO_Port GPIOC
#define I2C4_Data_Pin GPIO_PIN_7
#define I2C4_Data_GPIO_Port GPIOC
#define I2C3_Clock_Pin GPIO_PIN_8
#define I2C3_Clock_GPIO_Port GPIOC
#define I2C2_Data_Pin GPIO_PIN_8
#define I2C2_Data_GPIO_Port GPIOA
#define I2C2_Clock_Pin GPIO_PIN_9
#define I2C2_Clock_GPIO_Port GPIOA
#define F1_MoB_Pin GPIO_PIN_10
#define F1_MoB_GPIO_Port GPIOA
#define SHIFTREG_Clock_Pin GPIO_PIN_11
#define SHIFTREG_Clock_GPIO_Port GPIOA
#define SHIFTREG_Data_Pin GPIO_PIN_12
#define SHIFTREG_Data_GPIO_Port GPIOA
#define __SWDIO_Pin GPIO_PIN_13
#define __SWDIO_GPIO_Port GPIOA
#define __SWCLK_Pin GPIO_PIN_14
#define __SWCLK_GPIO_Port GPIOA
#define I2C1_Clock_Pin GPIO_PIN_15
#define I2C1_Clock_GPIO_Port GPIOA
#define F3_Touch_Pin GPIO_PIN_10
#define F3_Touch_GPIO_Port GPIOC
#define F2_Touch_Pin GPIO_PIN_11
#define F2_Touch_GPIO_Port GPIOC
#define F1_Touch_Pin GPIO_PIN_12
#define F1_Touch_GPIO_Port GPIOC
#define DISP_D2_FMC_Pin GPIO_PIN_0
#define DISP_D2_FMC_GPIO_Port GPIOD
#define DISP_D3_FMC_Pin GPIO_PIN_1
#define DISP_D3_FMC_GPIO_Port GPIOD
#define F0_Touch_Pin GPIO_PIN_2
#define F0_Touch_GPIO_Port GPIOD
#define DAC_LDAC4_Pin GPIO_PIN_3
#define DAC_LDAC4_GPIO_Port GPIOD
#define DISP_NOE_FMC_Pin GPIO_PIN_4
#define DISP_NOE_FMC_GPIO_Port GPIOD
#define DISP_NWE_FMC_Pin GPIO_PIN_5
#define DISP_NWE_FMC_GPIO_Port GPIOD
#define DAC_LDAC3_Pin GPIO_PIN_6
#define DAC_LDAC3_GPIO_Port GPIOD
#define DISP_NE1_FMC_Pin GPIO_PIN_7
#define DISP_NE1_FMC_GPIO_Port GPIOD
#define MASTER_Clock_Pin GPIO_PIN_3
#define MASTER_Clock_GPIO_Port GPIOB
#define MASTER_MISO_Pin GPIO_PIN_4
#define MASTER_MISO_GPIO_Port GPIOB
#define I2C3_Data_Pin GPIO_PIN_5
#define I2C3_Data_GPIO_Port GPIOB
#define DAC_LDAC2_Pin GPIO_PIN_6
#define DAC_LDAC2_GPIO_Port GPIOB
#define I2C1_Data_Pin GPIO_PIN_9
#define I2C1_Data_GPIO_Port GPIOB
#define DAC_LDAC1_Pin GPIO_PIN_0
#define DAC_LDAC1_GPIO_Port GPIOE
#define DAC_LDAC0_Pin GPIO_PIN_1
#define DAC_LDAC0_GPIO_Port GPIOE

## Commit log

2026-08-05 adding some helpful stuff and getting pin assignment up to date
    [EC11BREAKOUT.kicad_pcb, EC11BREAKOUT.kicad_sch, Pin Assigments.xlsx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]
2026-08-05 added all datasheets
    [EC11BREAKOUT.kicad_sch, Pin Assigments.xlsx]
2026-08-05 stm32 project setup and build
    [Pin Assigments.xlsx]
2026-08-08 more stuff
    [bom.csv, led_ring_rev1.kicad_pcb, led_ring_rev1.kicad_sch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]
2026-08-08 more stuff v2
    [bom.csv, positions.csv]
2026-08-10 written proposal half done ish (fr now). will do rest tomorrow
    [led_ring_rev1.kicad_pcb]
2026-08-12 fixed some dum dum stuff on the psu lol
    [PSU.kicad_pcb, PSU.kicad_sch]
2026-08-13 upload proposal
    [PSU.kicad_pcb, PSU.kicad_sch]
2026-08-13 ive been hiding something... </3
    [CHANNEL_STRIP_LL.kicad_pcb, CHANNEL_STRIP_LL.kicad_sch, bom.csv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]
2026-08-18 stuff and things idk
    [CHANNEL_STRIP_LL.kicad_pcb, CHANNEL_STRIP_LL.kicad_sch, PSU.kicad_pcb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]
2026-08-18 dev boards
    [EC11BREAKOUT.kicad_pcb, EC11BREAKOUT.kicad_sch, analog_pcb.kicad_sch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]
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2026-08-23 reorganized github repo, added master controller project
    [CHANNEL_STRIP_LL.kicad_pcb, CHANNEL_STRIP_LL.kicad_sch, DISPLAY_SCHEM.kicad_sch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]
2026-08-23 documentation and new blank source files for firmware - organizing how we will develop it
    [Pin Assigments.xlsx]
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2026-08-24 got mcp23017s working over i2c and fixed a few small i2c issues + added debug functions and console USART2 functionality. added pins for the 74HC595 that will program the MCP4728s with their addrress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
    [BucketController.ioc, i2c_driver.c, i2c_driver.h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]
2026-08-25 temporary so i can compare with other branch
    [EC11BREAKOUT.kicad_pcb, EC11BREAKOUT.kicad_sch]
2026-08-25 cleaned up lots of unused code and made whole codebase better refactored everything + fixed doc
    [mcp4728_driver.h]
2026-08-26 full single channel dev board
    [FullChanDevBoard.kicad_pcb, FullChanDevBoard.kicad_sch, bom.csv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]
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2026-08-27 chonker dev board
    [FullChanDevBoard.kicad_pcb, FullChanDevBoard.kicad_sch, bom.csv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]
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2026-08-28 getting main up to date just moved some stuff around tbh
    [FullChanDevBoard.kicad_pcb, ch_output_design.kicad_pcb, ch_output_design.kicad_sch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]
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2026-08-30 fixed mcp23017 driver to keep parked pointers and read both gpio registers in one i2c transaction, made the timeout cycles calculation only happen once at startup, fixed some stuff with encoder driver
    [CONFIG.h, i2c_driver.c, i2c_driver.h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]
2026-08-30 fix rotary encoder driver documentation
2026-09-01 we need to rewrite the mcp4728 driver
    [FullChanDevBoard.kicad_sch]
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2026-09-03 pcb designs and reorganization + getting ready to merge
    [CHANNEL_STRIP_LL.kicad_pcb, CHANNEL_STRIP_LL.kicad_sch, DISPLAY_SCHEM.kicad_sch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]
2026-09-03 switch to fixed-size stack data buffers for mcp4728 seqwrite and multiwrite commands
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2026-09-03 save my ver
    [bom.csv, designators.csv, fader.kicad_pcb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]
2026-09-03 moving some pins around, began testing of the mcp4728 dac driver and address programmer
    [bom.csv, designators.csv, fader.kicad_pcb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]
2026-09-03 cleaned up a bunch of stuff and updated documentation, did some updates after full system design tweaks
    [Pin Assigments.xlsx]
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2026-09-04 changed some pcb stuff and documentation and folder organization
    [Pin Assigments.xlsx, analog_component_choices.xlsx, bom.csv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]
2026-09-05 wants to merge
    [dacs.kicad_sch, digidev.kicad_pcb, digidev.kicad_sch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]
2026-09-09 preparing for capstone group to work, and preparing for moving to the VET3 package instead of RET6 for the stm32 for a time further into development
    [Digital System Dev.kicad_pcb, Digital System Dev.kicad_sch, bom.csv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]
2026-09-09 working on the digital systems dev board project
    [Digital System Dev.kicad_sch, ctrls_leds.kicad_sch, cv_sw.kicad_sch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]
2026-09-11 pushing for catching the team up later
    [Digital System Dev.kicad_pcb, Digital System Dev.kicad_sch, bom.csv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]
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2026-09-15 fix small issues with control integration
    [control_interface.c, knob_control.c, main.c]
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2026-09-16 pcb for control board started
    [DISPLAY_SCHEM.kicad_sch, Digital System Dev.kicad_pcb, Digital System Dev.kicad_sch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]
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2026-09-17 saving progress on controls pcb
    [LEDs.kicad_sch, bom.csv, btns1.kicad_sch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]
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2026-09-17 fix incorrect name in mcp4728, simple fader work
    [main.c]
2026-09-18 updates and input gain knob unsigned
    [Digital System Dev.kicad_pcb, Digital System Dev.kicad_sch]
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2026-09-18 revert atomic stuff for mcp caches
    [main.c]
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2026-09-18 merged and builds and ensured nothing from new tim4/5 was missed
    [led_handler.c]
2026-09-18 fixed some cringe stuff with files
    [74hc595.c, main.c]
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2026-09-19 pcb for displays
    [Digital System Dev.kicad_pcb, Digital System Dev.kicad_sch, bom.csv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]
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2026-09-20 merginging, press knob resets it
    [knob_control.c]
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2026-09-22 freertos task cleanup stuff
    create led handler as a statically allocated task, fix control interface init calls (we only called for channel 1 originally), slow down the irc scheduler clock (pls rember to fix this later)
    [BucketController.ioc, control_interface.c, i2c_scheduler.c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]
2026-09-23 move led_init out of led_handler, add mcp4728 init settings function
    move led_init out of led_handler and into the hardware initialization in main.c; separating the timer config from thread stuff might hopefully fix the crash. add a function to the mcp4728 driver to automatically set gain=1x, vref=internal
    [led_handler.c, main.c]
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2026-09-25 reorder init functions in main to fix nullptr control hardware
    [main.c]
2026-09-25 added fader/pan/insert routing analog card
    [Digital System Dev.kicad_pcb, Digital System Dev.kicad_sch, PAN_FADER.kicad_pcb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]
2026-09-25 move some stuff and add the THAT corporation vca application notes
    [eq_card.kicad_pcb, eq_card.kicad_sch, sends_proto2.kicad_pcb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]
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2026-09-25 fader/pan analog board
    [PAN_FADER.kicad_pcb, PAN_FADER.kicad_sch, bom.csv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]
2026-09-26 digital dev (or maybe final) board
    [Digital System Dev.kicad_pcb, Digital System Dev.kicad_sch, bom.csv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]
2026-09-26 fixed led flickering bug due to waiting for floating disconnnected i2c buses to respond until timeout
    [Digital System Dev.kicad_pcb, Digital System Dev.kicad_sch]
2026-09-27 dev/maybe final digital logic board. note to self still need to fix crowbar overvolt prot and the pwm disp backlight driver transistor
    [Digital System Dev.kicad_pcb, positions.csv]
2026-09-27 fix num 2 for my cpu hungry i2c scheduler :c
    [Digital System Dev.kicad_pcb, Digital System Dev.kicad_sch, bom.csv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]
2026-09-27 digilog dev board v1 finished and sent to jlc
    [DISPLAY_SCHEM.kicad_sch, Digital System Dev.kicad_pcb, Digital System Dev.kicad_sch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]
2026-09-27 skip 2000 frames when an i2c device doesn't respond
    [i2c_scheduler.c, led_handler.c]
2026-09-28 extreme pcb design
    [Digital System Dev.kicad_pcb, Digital System Dev.kicad_sch, bom.csv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]
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2026-09-29 only write mcp4728s when their cached values change
    with all 8 i2c devices on one bus, each frame's i2c traffic (2 gpio reads
    + 2 dac fast writes, ~224 scl clocks) ran past the 667us tim4 slot once bus
    capacitance slowed scl. the scheduler tasks busy-wait on the bus, so they
    never blocked, and the lower-priority led task starved: leds stopped
    following the knobs. removing any one device freed enough time to fit.
    dac writes are ~75% of that traffic, so:
    - mcp4728_cache tracks a per-chip synced flag, cleared when a cached value
    actually changes or a flush fails, set on a successful flush
    - scheduler skips synced dacs, but still rewrites each one every 60 calls
    (100ms) so a reset/replugged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
    [i2c_scheduler.c]
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2026-09-30 made documentation match reality better, especially the pin pictures on the main page
    [Pin Assigments.xlsx]
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2026-10-01 save pcb progress lol
    [LEDs.kicad_sch, bom.csv, bucket_controls.kicad_pcb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]
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2026-10-02 fader poller task to replace DMA
    [BucketController.ioc, fader_poller.c, main.c]
2026-10-03 pcb routing all day
    [Digital System Dev.kicad_pcb, LEDs.kicad_sch, bom.csv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]
2026-10-04 finished controls pcb finally
    [designators.csv, positions.csv]
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2026-10-05 ctrls board rev 0 done & sent to fab
    [bom.csv, btns0.kicad_sch, btns1.kicad_sch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]
2026-10-05 revised and ready to fab pan/fader analog board
    [COMP.kicad_pcb, COMP.kicad_sch, EQ.kicad_pcb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]
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2026-10-06 stupid jitter fixes
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2026-10-09 cad, pcb, designing the eq circuits yay, writing and documenting analog design, started the report aaaahhh i finna end it all jk
    [EQ.kicad_sch, channel_strip_faceplate.dxf, hf.kicad_sch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]
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2026-10-16 (heavily clanked) Centralize BucketController hardware mapping in CONFIG.h
    Merge the duplicated dev/release config into one section and keep only
    peripheral selections (I2C buses, timers, ADC, UART, LED SPI) there.
    Pins now use CubeMX labels directly, and plain values are typed consts.
    Replace duplicated channel-to-I2C-bus lookups with shared helpers in
    i2c_driver, and drive LED brightness through HAL PWM instead of raw
    TIM1 registers.
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2026-10-18 fixed a bug with stuff freezing bc of bad ordering of checking for successful i2c transaction produced false error flag if task switched at an exact point (very hard bug to find :c)
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2026-10-23 radio button stuff and dac fixes
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2026-10-26 fixed led bugs lmao
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

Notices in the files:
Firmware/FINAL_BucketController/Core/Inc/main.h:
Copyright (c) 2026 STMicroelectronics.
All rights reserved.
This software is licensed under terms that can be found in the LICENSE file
